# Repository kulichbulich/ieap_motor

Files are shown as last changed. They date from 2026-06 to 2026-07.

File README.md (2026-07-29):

# 4-Channel Motor Controller with ESP32
## Parts

### ESP32
Pin assigment https://github.com/atomic14/esp32-s3-pinouts/blob/main/README.md?utm_source=chatgpt.com

### Motor-driver module
Datasheet: https://www.analog.com/media/en/technical-documentation/data-sheets/TMC2209-BOB_datasheet_rev1.00.pdf
Motor module (KiCAD files): https://www.analog.com/media/en/evaluation-documentation/evaluation-design-files/TMC2209-BOB_Rev1.0.zip

### DC/DC converter
LT8610: https://www.analog.com/media/en/technical-documentation/data-sheets/lt8610.pdf
+5V Power supply
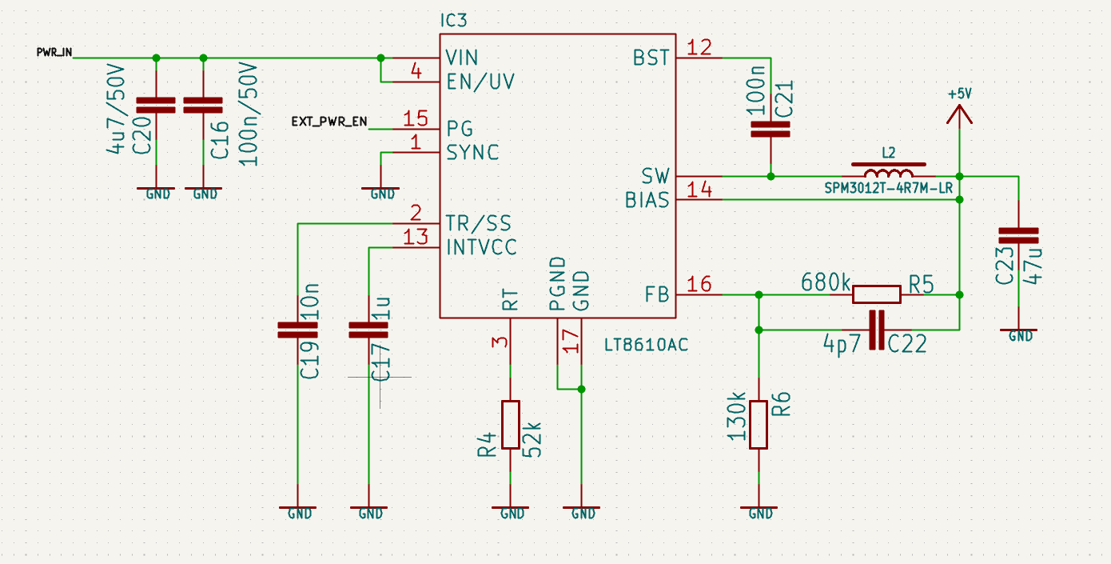
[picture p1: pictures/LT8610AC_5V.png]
image +5V

+5V Power supply
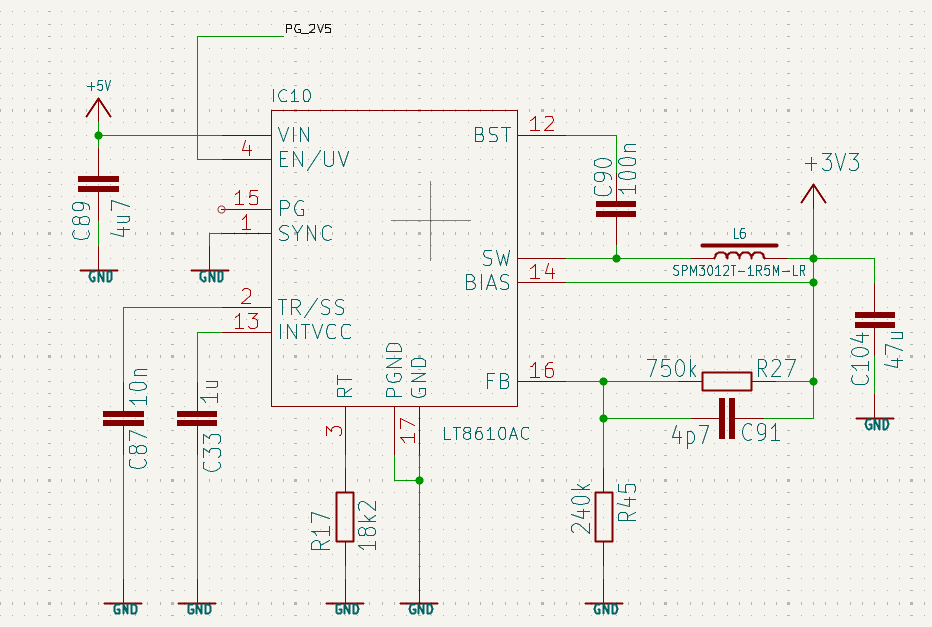
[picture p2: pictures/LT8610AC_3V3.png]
image +3V3


### Polyswitch
https://cz.mouser.com/ProductDetail/Littelfuse/MINISMDC150F-24-2?qs=F6FIpiMdEVZ%2Fp37J%2FDHAxA%3D%3D

# Enclosure

Enclosure - open view

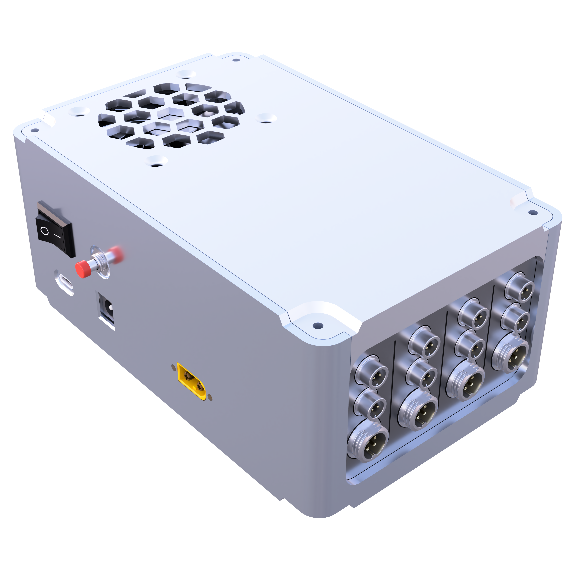
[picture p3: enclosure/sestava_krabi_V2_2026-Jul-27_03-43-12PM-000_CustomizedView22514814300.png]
Enclosure - closed view


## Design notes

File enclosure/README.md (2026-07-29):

# Enclosure

Enclosure - open view

Enclosure - closed view

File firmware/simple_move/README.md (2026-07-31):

# simple_move — základní pohyb driveru BOB-3

Nejjednodušší firmware, který na desce `esp32stepper` (ESP32-S3-WROOM-2 N32R16V + 4× TMC2209
SilentStepStick) rozhýbe **jeden** motor. Po zapnutí nastaví driver po UART, povolí ho a pak už jen
pořád dokola jede **jednu otáčku tam, pauza, jednu otáčku zpět, pauza**. Z konzole se nic neovládá —
konzole jen vypisuje, co se děje.

Vznikl jako osekaná kopie [../FAS_firmware](../FAS_firmware). Rozdíly jsou schválně:

| | simple_move | ../FAS_firmware |
|---|---|---|
| generátor kroků | jen softwarová smyčka (`stepper.cpp`) | smyčka **i** FastAccelStepper (`env:fas_accel`) |
| přepínače chování | žádné (čekání na Enter, vypnutí koncováku…) | `WAIT_FOR_ENTER`, `ENDSTOP_GUARD`, `STOP_ON_KEYPRESS` |
| reset driveru za běhu (výpadek 24 V) | **HALT** a čeká na člověka | sám se znovu nastaví (`driver_survived()`) |

Kdo potřebuje varianty, má sáhnout po `FAS_firmware`. Kdo chce ladit proud, rychlost a mikrokrok
**za běhu**, patří do [../testing_firmware](../testing_firmware), test **T09**.

## Co to potřebuje

| | |
|---|---|
| napájení | 24 V na barrel jacku (bez něj driver komunikuje, ale motor stojí a hlásí `uv_cp`) |
| motor | v konektoru **BOB-3** (čtvrtý slot; jiný slot = `MOTOR` v `include/move_config.h`) |
| ověřeno předem | testy **T06** (UART), **T07** (zapojení) a **T08** (pohyb) v `../testing_firmware` |
| mechanika | volná dráha na obě strany, motor se rozjede **3 s po nabootování** |

## Build a nahrání

`pio run -t upload` na této desce nespolehlivě padá (esptool 4.5.1 v PlatformIO, `BrokenPipeError`),
proto skript s vlastním esptoolem — podrobně v [../FLASH.md](../FLASH.md):

```bash
cd firmware/simple_move
../flash.sh -d .            # build + kontrola flash + zápis
../flash.sh -d . --check    # jen diagnostika, nic nezapisuje
pio device monitor -d .     # konzole (115200, USB CDC)
```

Prostředí je jediné (`simple`) a je v `default_envs`, takže `-e` není potřeba.

## Nastavení

Všechno je v [include/move_config.h](include/move_config.h) jako `constexpr` — změna znamená přeložit
a nahrát. Nejdůležitější hodnoty:

| konstanta | výchozí | co dělá |
|---|---|---|
| `MOTOR` | `3` | slot driveru 0–3; určuje i adresu na UART, STEP pin a koncový spínač |
| `MICROSTEPS` | `16` | mikrokrok; nastavuje se **po UART** (MS1/MS2 na desce drží adresu) |
| `RUN_CURRENT_MA` | `600` | efektivní (RMS) proud fáze při jízdě |
| `HOLD_CURRENT_PCT` | `50` | klidový proud v procentech z jízdního |
| `REVS_PER_MOVE` | `1.0` | jeden pohyb = jedna otáčka |
| `SPEED_RPM` | `60` | cestovní rychlost (60 rpm = otáčka za sekundu) |
| `ACCEL_RPS2` | `4.0` | zrychlení v otáčkách/s² (rozjezd na 60 rpm za 0,25 s) |
| `PAUSE_MS` | `500` | prodleva mezi pohyby |
| `START_DELAY_MS` | `3000` | odpočet po nabootování, než se motor rozjede |

### Proud se zadává v mA, driver ho zná jako CS

Registr `IHOLD_IRUN` má na proud jen 5 bitů, takže zadanou hodnotu nelze potrefit přesně: firmware si
z mA spočítá `CS` (a případně přepne `vsense` na jemnější rozsah) a na konzoli vypíše **obojí** —
co bylo zadáno a co se doopravdy nastavilo. Výchozích 600 mA vyjde na `IRUN = 19, vsense = 1`,
tedy ~612 mA RMS.

Celý přepočet stojí na `R_SENSE_OHM = 0.11` (SilentStepStick / Trinamic TMC2209-BOB). Jiná hodnota
na modulu = všechny proudy o ten podíl vedle. **Ampérmetrem to ověřené není**, jen podle datasheetu —
stejně jako v `FAS_firmware`. Podrobně v [../TMC2209_CURRENT.md](../TMC2209_CURRENT.md).

### MS1/MS2 dělají adresu i mikrokrok

Na této desce drží pull-upy `R13`–`R16` na `MS1`/`MS2` **adresu driveru** na UART sběrnici. Tytéž
piny ale po resetu určují i mikrokrok, takže mikrokrok se musí přepnout na registrový:

1. nejdřív `CHOPCONF.MRES` (žádaný mikrokrok),
2. teprve pak `GCONF` bit 7 `mstep_reg_select`.

V obráceném pořadí by driver na okamžik jel s `MRES` z resetu (1/256). Pořadí v
[src/tmc2209.cpp](src/tmc2209.cpp) je proto záměrné — podrobně v
[../TMC2209_MS1_MS2.md](../TMC2209_MS1_MS2.md).

`GCONF` bit 0 (`I_scale_analog`) zůstává **0** schválně: s jedničkou by proud škáloval pin `VREF`,
který modul driveru na této desce nevyvádí, a přepočet mA → CS by nic neznamenal.

## Co firmware kontroluje

Rozjede se jen tehdy, když všechno projde; jinak jde do `HALT` (driver zakázán, čeká na reset desky):

- **driver odpovídá** po UART a hlásí `VERSION = 0x21` i tu adresu, na kterou se ptáme (pět pokusů,
  driver po zapnutí chvíli nabíhá),
- **konfigurace prošla** — kontroluje se přes `IFCNT` (počet přijatých zápisů) i čtením registrů zpět,
- **`DRV_STATUS` nehlásí chybu** (přehřátí, zkrat na GND/VS) — před rozjezdem i po každém pohybu;
  `otpw` (předzvěst přehřátí) a `cs_actual = 0` (neteče proud → chybí 24 V) jsou jen varování,
- **`GSTAT.reset` po každém pohybu** — když driver mezitím ztratil napájení, přišel o celou
  konfiguraci (mikrokrok zpátky pinový, proud výchozí) a firmware jde do `HALT`. Pokračovat by
  znamenalo jet s proudem, který nikdo nezadal.

Kromě toho po každém cyklu ověří, že se počítadlo kroků vrátilo na začátek. **Pozor:** hlídá tím jen
samo sebe — když motor ztrácí kroky (malý proud, vysoká rychlost, tuhá mechanika), počítadlo o tom
nic neví a bez enkodéru to firmware nepozná.

## Bezpečnost

- **74HC595 má `~OE` na GND**, takže jeho výstupy platí od přivedení napájení a do prvního zápisu
  jsou náhodné. Proto je `mot.begin()` (STEP piny do L, `SR = 0xAA`, tedy všechny drivery zakázané)
  úplně první věc v `setup()` — ještě před konzolí, na kterou se čeká až 3 s.
- **Koncový spínač** `IO16` (pro `MOTOR = 3`) jízdu zastaví. Když je při startu už sepnutý — nebo
  není zapojený — hlídání se samo vypne (jinak by se firmware nikdy nerozjel) a vypíše se `[WARN]`.
- **Jakákoli klávesa** z konzole jízdu přeruší a driver zakáže (hřídel je pak volná); další klávesa
  pokračuje. Kontroluje se každých 16 kroků, tedy při 3200 krocích/s asi každých 5 ms.
- Motor se rozjede **sám** 3 s po nabootování, i bez připojené konzole. `START_DELAY_MS` je jediná
  pojistka, kdy se dá odpojit napájení.

## Stav

**Přeloženo, na desku nenahráno.** `pio run -e simple` staví čistě (`-Wall`, 0 warningů,
RAM 6,0 %, Flash 293 977 B). Kód je kopie logiky z `FAS_firmware`, která na hardwaru také nikdy
neběžela — chování je odvozené z datasheetu TMC2209 a z pin mapy, ne z pozorování na desce.

Neověřeno: skutečný proud fáze ampérmetrem, chování při výpadku 24 V za jízdy, funkce koncového
spínače.

## Struktura

```
simple_move/
  platformio.ini          jedno prostředí "simple" (default_envs), oktální flash config
  include/board_pins.h    kopie z ../testing_firmware — držet v souladu, NENÍ symlink
  include/move_config.h   VŠECHNA nastavení jako constexpr
  include/tmc2209.h + src/tmc2209.cpp   driver po jednodrátové UART, přepočet mA -> CS
  include/stepper.h + src/stepper.cpp   74HC595 (DIR/EN) + generátor kroků s trapézovou rampou
  src/main.cpp            bring-up, kontroly, smyčka pohybů
```

Žádná externí knihovna — je to pět registrů a stejně by se muselo řešit zahazování vlastního echa na
jednodrátové sběrnici, takže `TMCStepper` by nic neušetřil.

`move()` **blokuje**: kroky se generují softwarovou smyčkou na `micros()`, ne timerem ani RMT. Dokud
pohyb neskončí, firmware nedělá nic jiného. Až bude potřeba víc motorů najednou nebo souběžné čtení
enkodérů, tohle se musí přepsat (nebo použít FastAccelStepper — prototyp je v
[../FAS_firmware](../FAS_firmware), prostředí `fas_accel`).

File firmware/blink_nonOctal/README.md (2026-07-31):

Použil jsem tyto dva příkazy:

ls -la /dev/ttyACM* /dev/ttyUSB*
— zjištění, na jakém portu je deska připojená (vyšlo /dev/ttyACM0, nativní USB; /dev/ttyUSB* nebyl přítomen).

cd /home/pe/Documents/repos/ieap_motor/firmware/blink_nonOctal
pio run -t upload --upload-port /dev/ttyACM0
— standardní PlatformIO build + upload (přeloží blink_nonoctal env a nahraje přes zabudovaný esptool 4.5.1, který v platformio.ini komentář zmiňuje jako nefunkční jen pro desku esp32stepper, ne pro tenhle devkit — zde prošel bez problémů).

---------------nebo--------------------

Použil jsem:

cd firmware/blink_nonOctal
pio run                                          # build bez uploadu

# nový esptool z venv (5.3.1, stejný, co používá flash.sh pro octal desku)
~/venv-esptool/bin/python -m esptool \
    --port /dev/ttyACM0 --baud 460800 \
    --before default-reset --connect-attempts 5 \
    write-flash --flash-mode keep --flash-freq keep --flash-size keep \
    0x0     .pio/build/blink_nonoctal/bootloader.bin \
    0x8000  .pio/build/blink_nonoctal/partitions.bin \
    0xe000  ~/.platformio/packages/framework-arduinoespressif32/tools/partitions/boot_app0.bin \
    0x10000 .pio/build/blink_nonoctal/firmware.bin
Jedna odchylka od flash.sh: --before usb-reset (co používá flash.sh pro esp32stepper) na tomhle devkitu selhalo s "No serial data received". Musel jsem přepnout na --before default-reset — tenhle devkit má klasický auto-reset přes RTS/DTR, ne přes signalizaci nativního USB-Serial/JTAG periferie.

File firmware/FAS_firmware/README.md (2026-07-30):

# FAS firmware — pohyb tam a zpět
@doc_pwc: file:README.md | id:HW-00176 | created:2026-07-30 | rev:2 | revised:2026-07-30_1802 | type:MAN

Nejjednodušší **aplikační** firmware desky `esp32stepper` (ESP32-S3-WROOM-2 N32R16V + 4× TMC2209
SilentStepStick). Po zapnutí nastaví jeden driver po UART, povolí ho a pak už jen pořád dokola jede
**jednu otáčku tam, pauza, jednu otáčku zpět, pauza**. Z konzole se nic neovládá — konzole jen
vypisuje, co se děje.

Tohle je první krok od testů k aplikaci: [../testing_firmware](../testing_firmware) se ptá na
parametry a čeká na člověka, tenhle firmware se rozjede sám po zapnutí, jako to bude dělat hotový
stroj.

## Co to potřebuje

| | |
|---|---|
| napájení | 24 V na barrel jacku (bez něj driver komunikuje, ale motor stojí a hlásí `uv_cp`) |
| motor | v konektoru **BOB-3** (čtvrtý slot; jiný slot = `MOTOR` v `include/fas_config.h`) |
| ověřeno předem | testy **T06** (UART), **T07** (zapojení) a **T08** (pohyb) v `../testing_firmware` |
| mechanika | volná dráha na obě strany, motor se rozjede **3 s po nabootování** |

## Build a nahrání

`pio run -t upload` na této desce nespolehlivě padá (esptool 4.5.1 v PlatformIO, `BrokenPipeError`),
proto skript s vlastním esptoolem — podrobně v [../FLASH.md](../FLASH.md):

```bash
cd firmware/FAS_firmware
../flash.sh -d .            # build + kontrola flash + zápis
../flash.sh -d . --check    # jen diagnostika, nic nezapisuje
pio device monitor -d .     # konzole (115200, USB CDC)
```

Prostředí je jediné (`fas`) a je v `default_envs`, takže `-e` není potřeba.

## Nastavení

Všechno je v [include/fas_config.h](include/fas_config.h) jako `constexpr` — změna znamená přeložit
a nahrát. Nejdůležitější hodnoty:

| konstanta | výchozí | co dělá |
|---|---|---|
| `MOTOR` | `3` | slot driveru 0–3; určuje i adresu na UART, STEP pin a koncový spínač |
| `MICROSTEPS` | `16` | mikrokrok; nastavuje se **po UART** (MS1/MS2 na desce drží adresu) |
| `RUN_CURRENT_MA` | `600` | efektivní (RMS) proud fáze při jízdě |
| `HOLD_CURRENT_PCT` | `50` | klidový proud v procentech z jízdního |
| `REVS_PER_MOVE` | `1.0` | jeden pohyb = jedna otáčka |
| `SPEED_RPM` | `60` | cestovní rychlost (60 rpm = otáčka za sekundu) |
| `ACCEL_RPS2` | `4.0` | zrychlení v otáčkách/s² (rozjezd na 60 rpm za 0,25 s) |
| `PAUSE_MS` | `500` | prodleva mezi pohyby |
| `START_DELAY_MS` | `3000` | odpočet po nabootování, než se motor rozjede |
| `WAIT_FOR_ENTER` | `false` | `true` = deska se sama nerozjede, čeká na klávesu |

Ladit proud, rychlost a mikrokrok **za běhu** se dá v `../testing_firmware`, test **T09** — tady se
mění jen v kódu.

### Proud se nastavuje v mA, driver ho zná jako CS

Registr `IHOLD_IRUN` má na proud jen 5 bitů, takže zadanou hodnotu nelze potrefit přesně:

```
I_rms = (CS+1)/32 × V_fs/(R_sense+0,02) × 1/√2      V_fs = 0,325 V (vsense=0) nebo 0,180 V (vsense=1)
```

Firmware si CS spočítá sám, a když se proud vejde do jemnějšího rozsahu (`vsense=1`), použije ho —
polovina chyby zaokrouhlení. Na konzoli vypíše obojí, zadané i skutečné:

```
proud    : zadano 600 mA -> nastaveno 612 mA RMS (IRUN=19, vsense=1, Rsense 0.11 ohm)
           klidovy 50 % = 306 mA (IHOLD=9, IHOLDDELAY=6, TPOWERDOWN=20)
```

Dvě věci, které z toho plynou:

* **`R_SENSE_OHM = 0.11` je jediné číslo, na kterém celý přepočet stojí.** 0,11 Ω má
  SilentStepStick TMC2209 i Trinamic TMC2209-BOB. Když je na modulu jiná hodnota, jsou všechny
  proudy o ten podíl vedle — ověřit ampérmetrem, ne z datasheetu klonu.
* Strop je **1768 mA RMS** (CS=31, `vsense=0`). Vyšší zadání se do něj utne, `SilentStepStick`
  bez chladiče na to ale stejně není.

### MS1/MS2 dělají adresu i mikrokrok

Na této desce mají `MS1`/`MS2` dvě funkce najednou: pull-upy `R13..R16` jim dávají UART adresu, a tím
zároveň každé patici jiné rozlišení mikrokroku (BOB-0 = 1/8, BOB-1 = 1/2, BOB-2 = 1/4, BOB-3 = 1/16).
Podrobně [../TMC2209_MS1_MS2.md](../TMC2209_MS1_MS2.md) (HW-00201). Firmware to řeší takto:

* `CHOPCONF.MRES` se zapisuje **před** `GCONF` bitem 7 (`mstep_reg_select`) — v okamžiku, kdy se
  řízení přebírá z pinů do registru, už v registru musí být správná hodnota. V obráceném pořadí by
  driver mezitím jel podle toho, co v `MRES` zbylo (po resetu 1/256).
* `GCONF` bit 0 (`I_scale_analog`) firmware **záměrně nuluje** — s jedničkou by proud škáloval pin
  `VREF` a přepočet mA → CS by nic neznamenal. Modul driveru `VREF` na této desce ani nevyvádí
  (symbol v `PCB/tmc2209_driver.kicad_sch` má 17 pinů a `VREF` mezi nimi není). Tohle je jediné
  místo, kde se firmware odchyluje od doporučení HW-00201 (čti-uprav-zapiš celého `GCONF`).
* **`GSTAT` bit 0 se čte po každém pohybu.** Registry driveru jsou volatilní — po výpadku 24 V
  naběhne s výchozími hodnotami (mikrokrok zpátky z pinů, `IRUN` = 23, `I_scale_analog` = 1) a na
  `DRV_STATUS` to není vidět. Když firmware reset zachytí, driver zakáže, znovu nastaví, vynuluje
  počítadlo polohy (hřídel se během výpadku mohla protočit) a jede dál. Když se znovunastavení
  nepovede, jde do `HALT`.

## Výpis na konzoli

```
===================================================
  FAS firmware - pohyb tam a zpet
===================================================
driver odpovida: VERSION=0x21, ENN=1, PDN_UART=1
driver   : BOB-3, adresa 3 na UART sbernici (IO17/IO18), STEP=IO7, koncovak=IO16
mikrokrok: 1/16 z registru (MS1/MS2 tady drzi adresu), 3200 kroku na otacku
proud    : zadano 600 mA -> nastaveno 612 mA RMS (IRUN=19, vsense=1, Rsense 0.11 ohm)
pohyb    : 1.00 otacky = 3200 kroku, 60.0 rpm (3200 kroku/s), zrychleni 4.0 ot/s^2
           rampa 398 kroku, jeden pohyb ~1.2 s, pauza 500 ms
koncovy spinac IO16 je rozepnuty - pri sepnuti pohyb zastavi
motor se rozjede za 3 s - mechanika musi mit volnou drahu
driver povolen, hridel drzi klidovy proud. Tady je nula polohy - ...

cyklus 1: 1.00 otacky tam a zpet
  smer A: 3200 kroku za 1247 ms (~2565 kroku/s), poloha +3200
  smer B: 3200 kroku za 1246 ms (~2568 kroku/s), poloha +0
```

Naměřená rychlost je nižší než cestovní — je to průměr přes celý pohyb včetně obou ramp.

## Bezpečnost a zastavení

* **Bezpečný stav je první věc v `setup()`**, ještě před konzolí: `74HC595` má `~OE` na GND, takže
  jeho výstupy platí od přivedení napájení a do prvního zápisu jsou náhodné. Čekání na USB CDC trvá
  až 3 s — tak dlouho nesmí být povolený driver s náhodným DIR.
* **Jakákoli klávesa** z konzole jízdu přeruší (driver se zakáže, hřídel se pustí); další klávesa
  pokračuje. Počítadlo polohy zůstává, ale značka na hřídeli už na startu nebude.
* **Koncový spínač** daného motoru jízdu zastaví — ale jen když je v klidu rozepnutý (H). Když už
  při startu drží L (sepnutý nebo nezapojený bez pull-upu), hlídání se vypne a jedinou pojistkou je
  klávesa. Firmware to na konzoli hlásí.
* **`DRV_STATUS` se čte po každém pohybu.** Přehřátí a zkraty (`ot`, `s2g*`, `s2vs*`) firmware
  zastaví natrvalo (`HALT`, driver zakázán, chce reset desky). `otpw` (předzvěst přehřátí) a
  `ola`/`olb` (rozpojená fáze, hlásí je i zdravý stojící motor) jsou jen varování.
* Symetrický pohyb musí skončit na poloze **0**. Když počítadlo je na nule a značka na hřídeli ne,
  motor **ztrácí kroky** — malý proud, vysoká rychlost, tuhá mechanika.

## Struktura

```
platformio.ini          jedno prostředí "fas"; oktální flash konfigurace (viz níže)
include/board_pins.h    pin mapa desky — kopie z testing_firmware, držet v souladu
include/fas_config.h    všechna nastavení
include/tmc2209.h       driver na jednodrátové UART sběrnici + přepočet mA -> CS
include/stepper.h       generátor kroků, 74HC595 (DIR/EN), trapézová rampa
src/main.cpp            bring-up (ping, GSTAT, konfigurace, kontroly) a smyčka pohybů
```

Žádná externí knihovna (`lib_deps` je prázdné). TMC2209 se obsluhuje přímo — je to pět registrů
a v jednodrátovém režimu se stejně musí zahazovat vlastní echo, takže `TMCStepper` by tu nic
neušetřil.

### Konfigurace flash v `platformio.ini`

Modul je **N32R16V**: 32 MB oktální (OPI) flash + 16 MB oktální PSRAM, obojí na 1V8 (potvrzeno
z efuse). Konfigurace `memory_type = opi_opi` **není kosmetika** a platí na obě strany:

* quad konfigurace na tomto modulu **nenabootuje** — ROM podle efuse zapne OPI a aplikace spadne na
  `assert failed: do_core_init startup.c:328 (flash_ret == ESP_OK)` ve smyčce resetu,
* a binárku s `opi_opi` naopak nenos na DevKitC-1 N8R2 — tam skončí na
  `E cpu_start: Octal Flash option selected, but EFUSE not configured!`.

`flash_mode` je záměrně `dout`, ne `opi`: ani první, ani druhý bootloader OPI neumí, zavádí se
v DOUT a ROM režim nahradí podle efuse. Tři pasti, které stály hodiny, jsou v
[../report.md](../report.md).

## Známé hranice

* **`move()` blokuje.** Kroky se generují softwarovou smyčkou (`micros()` termíny), ne timerem ani
  RMT — na pár tisíc kroků/s to stačí a kód je čitelný, ale dokud pohyb neskončí, firmware nedělá
  nic jiného. Až bude potřeba jet víc motory najednou nebo mezitím číst enkodéry, musí se to
  přepsat na timer.
* Strop generátoru je **20 000 kroků/s**; `SPEED_RPM` nad tuto hranici firmware sníží a nahlásí.
* Jede **jeden motor**, ostatní tři zůstávají zakázané.
* Driver zůstává na výchozím **stealthChop** (tichý, ale nižší moment ve vyšších otáčkách) —
  `spreadCycle` ani `TPWMTHRS` se tu nenastavují.
* **Bez enkodéru.** Poloha je jen počítadlo vydaných kroků, ne měřená skutečnost. Enkodéry na
  desce jsou (I2C mux `TCA9548A`), tenhle firmware je nepoužívá.

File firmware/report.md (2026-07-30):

# Oživení ESP32-S3-WROOM-2 na desce esp32stepper — co bylo špatně a jak s tím zacházet
@doc_pwc: file:report.md | id:HW-00173 | created:2026-07-30 | rev:1 | revised:2026-07-30_0913 | type:PROC

Postmortem k tomu, proč se na desku `PCB/esp32stepper.kicad_pro` nedalo nic nahrát, a závazný postup
pro příště. Řešeno 2026-07-29 a 2026-07-30. **Modul vadný nebyl** — jeden den se to omylem uzavřelo
jako hardwarová závada, což byl špatný závěr.

---

## Shrnutí jednou větou

Na sobě ležely **tři nezávislé problémy**, každý maskoval ten další, a první dva dohromady vypadaly
přesně jako mrtvý hardware.

| # | Problém | Projev | Náprava |
|---|---|---|---|
| 1 | Flash zaseknutá v OPI režimu | `Failed to communicate with the flash chip`, `Manufacturer: 00` | úplné odpojení napájení |
| 2 | Nastavené block-protect bity ve flash | `flash_id` OK, ale zápis tiše selže | `esptool write-flash-status` |
| 3 | Quad build konfigurace na oktálním modulu | boot loop na `do_core_init` assertu | `opi_opi` + `dout` + 32 MB |

Navíc se ukázalo, že **esptool z PlatformIO (4.5.1) je na téhle desce nepoužitelný** a nahrávat se
musí samostatným esptoolem 5.3.1.

---

## Varianta modulu — potvrzeno

`U1` je **ESP32-S3-WROOM-2 N32R16V**: 32 MB oktální (OPI) flash + 16 MB oktální PSRAM, obojí 1,8 V.
Flash je samostatná die na substrátu modulu, ne v čipu.

Ověřeno proti efuse přímo na čipu i proti `RDID`:

```
FLASH_TYPE   = 8 data lines          VDD_SPI_XPD   = True
PSRAM_CAP    = 16M                   VDD_SPI_TIEH  = 1.8V LDO
PSRAM_VENDOR = AP_1v8                VDD_SPI_FORCE = True
FLASH_CAP    = None  (spravne: flash neni v cipu, ale na substratu modulu)
RDID         = C2 80 39  -> Macronix MX25UM25645G, 32 MB
```

BOM `PCB/esp32stepper.csv` uvádí u `U1` jen „ESP32-S3-WROOM-2" bez paměťové přípony, protože se
generuje z KiCadu. **Variantu ber odsud, ne z BOM.** Právě ta nejistota v BOM stála za problémem č. 3.

---

## Problém 1 — flash zaseknutá v OPI režimu

**Projev.** `esptool flash_id` hlásil `Failed to communicate with the flash chip` a
`Manufacturer: 00, Device: 0000`. Čtení flash vracelo nedeterministická data — tři čtení téže adresy
`0x0` daly tři různé MD5. Chip erase „uspěl" za 0,6 s (u 32 MB nemožné) a nic nesmazal.

**Proč.** Reset přes `EN` resetuje procesor, ale **neresetuje flash die**. Když v ní zůstane OPI
režim (nastaví ho ROM podle efuse při bootu, viz problém 3), ROM ani esptool s ní v SPI/DOUT režimu
nedomluví. Ta nedeterministická data byly plovoucí datové linky.

**Náprava.** Úplně odpojit napájení. **Pozor: deska umí jet i z 24 V barrel jacku** (`LT8610` buck →
`LDL1117` na 3V3), takže vytažení jen USB modul nevypne. Odpoj USB **i** barrel jack a počkej ~10 s
na vybití kondenzátorů.

Po power cyclu začal `flash_id` vracet správně `C2 / 8039 / 32MB`.

**Slepé uličky, které stály čas** — tudy ne:

- verze esptoolu (4.5.1 i 5.3.1 selhaly stejně), se stubem i `--no-stub`
- rychlosti: 4 baud raty × 2 režimy stubu, všech 8 kombinací identicky `Manufacturer: 00`.
  Přes nativní USB-Serial/JTAG je baud rate principiálně **no-op**, je to USB CDC — `upload_speed`
  na téhle cestě nemůže udělat nic.
- pájení FTDI na UART0 — nepomůže, závada je na sběrnici SPI0↔flash, tedy *za* hostitelským
  rozhraním; přes UART dostaneš stejnou chybu
- napájení: program u téhle flash tahá jednotky mA, kdežto běžící CPU s USB řádově víc a ten jede
- efuse: jsou od výroby správné, **nic v nich nepal** (viz níže)

## Problém 2 — block-protect bity ve flash

**Projev.** `flash_id` už vracel správně `C2/8039/32MB`, ale zápis tiše neprošel:
`MD5 of file does not match data in flash!`, u zápisu mimo hlavičku
`Write failed, the written flash region is empty`. Chip erase pořád „uspěl" a nic nesmazal.

**Diagnóza.** Status registr `MX25UM25645G` čten jako `SR1 = 0xB0`:

| bit7 | bit6 | bit5 | bit4 | bit3 | bit2 | bit1 | bit0 |
|---|---|---|---|---|---|---|---|
| Reserved | Reserved | **BP3=1** | **BP2=1** | BP1=0 | BP0=0 | WEL=0 | WIP=0 |

`BP[3:0] = 1100`, tedy nenulové → pole chráněné proti zápisu. Datasheet to popisuje doslova:

> *„If a program or erase instruction is applied to a protected memory area, the instruction will be
> ignored and WEL will clear to 0."*
>
> *„only if Block Protect bits (BP3:BP0) set to 0, the CE instruction can be executed"*

To vysvětluje jak tichý fail zápisu, tak chip erase, který nic nesmazal.

**Pozor na dvě věci, které se snadno spletou** (a já je spletl, než jsem si přečetl datasheet):
`MX25UM` (oktální) série **nemá bity `SRWD` ani `QE`** — bit7 a bit6 jsou Reserved. Neber layout
status registru z analogie s quad sérií `MX25U`.

**Náprava.**

```bash
esptool --port /dev/ttyACM0 read-flash-status  --bytes 1                      # kontrola: 0xb0
esptool --port /dev/ttyACM0 write-flash-status --bytes 1 --non-volatile 0x00  # naprava
esptool --port /dev/ttyACM0 read-flash-status  --bytes 1                      # overeni: 0x00
```

Proč přesně takhle:

- `--bytes 1` **záměrně**: `WRSR` (`01h`) bere 8 nebo 16 bitů a jen 8bitová forma nechá
  **konfigurační registr netknutý** (dummy cycles, ODS). 16 bitů by ho přepsalo a rozbilo časování
  čtení.
- `--non-volatile` je **nutné**: posílá `WREN` (`06h`) před `WRSR`, což datasheet vyžaduje. Bez něj
  jde `WEVSR` (`50h`), který tenhle díl nemusí znát.
- `BP` bity jsou nevolatilní, ale **volně přepisovatelné** — není to OTP, jde to vrátit.
- OTP bit `WPSEL` se tímhle nastavit **nedá**, má jiný opcode (`68h`). Kdyby byl `WPSEL=1`, byly by
  `BP` bity bez efektu a blokovaly by `DPB` bity po každém zapnutí; poznalo by se to tím, že se
  zápis do SR neprojeví.

Příčina, proč byly `BP` bity nastavené, není prokázaná. Nejpravděpodobněji je nastavily zápisy do
flash zaseknuté v OPI režimu (problém 1), kde se SPI příkazy interpretují jako něco jiného.

## Problém 3 — quad konfigurace na oktálním modulu

**Projev.** Nahrávání konečně prošlo s `Hash of data verified`, ale deska se resetovala ve smyčce:

```
SPIWP:0xee
Octal Flash Mode Enabled
For OPI Flash, Use Default Flash Boot Mode
...
assert failed: do_core_init startup.c:328 (flash_ret == ESP_OK)
```

**Proč.** ROM podle efuse zapne OPI, ale aplikace byla přeložená pro quad (`qio_qspi`, `dio`, 8 MB),
takže inicializace flash v aplikaci selže.

**Tohle přímo vyvrací, co dřív tvrdil `testing_firmware/README.md`:** že quad konfigurace
„nabootuje na každé variantě S3 včetně modulu, který octal paměti opravdu má". Nenabootuje. **Žádný
quad/oktální společný jmenovatel neexistuje** a obě README i `platformio.ini` jsou už opravené.

**Správná konfigurace** pro N32R16V:

```ini
board_upload.flash_size = 32MB
board_build.partitions = default_16MB.csv
board_build.flash_mode = dout
board_build.arduino.memory_type = opi_opi
```

- `flash_mode = dout`, **ne `opi`**: 1. ani 2. bootloader OPI neumí, zavádí se v DOUT a ROM režim
  nahradí podle efuse. Stejně to má i board def `esp32s3camlcd`, jediný v platformu s `opi_opi`.
- `default_32MB.csv` ve frameworku **neexistuje**; `default_16MB.csv` na 32 MB čipu jede (nevyužije
  zbytek), pro víc prostoru je `large_littlefs_32MB.csv`.

---

## Postup nahrávání odteď

`pio run -t upload` na téhle desce **nepoužívej**. PlatformIO má v sobě esptool 4.5.1
(`tool-esptoolpy 1.40501.0`), který na oktální flash přes nativní USB-Serial/JTAG padá na
`BrokenPipeError: [Errno 32] Broken pipe`, jakmile se čip zároveň resetuje (typicky když je v boot
loopu). Samostatný esptool 5.3.1 se připojí bez problémů.

```bash
# jednorazova priprava
python3 -m venv ~/venv-esptool && ~/venv-esptool/bin/pip install esptool

# 1) jen build, BEZ -t upload
pio run -e usb_j5            # nebo -e menu v testing_firmware

# 2) nahrani samostatnym esptoolem
~/venv-esptool/bin/python -m esptool --port /dev/ttyACM0 --baud 460800 \
    --before usb-reset --connect-attempts 5 \
    write-flash --flash-mode keep --flash-freq keep --flash-size keep \
    0x0     .pio/build/usb_j5/bootloader.bin \
    0x8000  .pio/build/usb_j5/partitions.bin \
    0xe000  ~/.platformio/packages/framework-arduinoespressif32/tools/partitions/boot_app0.bin \
    0x10000 .pio/build/usb_j5/firmware.bin
```

`keep` u všech tří parametrů je důležité — nechá hlavičku z buildu být, aby ji esptool nepřepsal na
jinou velikost nebo režim flash. `--before usb-reset` pomáhá, když se čip resetuje ve smyčce.

## Diagnostický postup, když to zase nejde

Vždycky v tomhle pořadí, od nejlevnějšího:

1. **`flash_id`** — první věc, ještě před jakýmkoli buildem.
   ```bash
   ~/venv-esptool/bin/python -m esptool --port /dev/ttyACM0 flash-id
   ```
   Zdravý stav: `Manufacturer: c2`, `Device: 8039`, `Detected flash size: 32MB`, **bez** varování.
2. **`Manufacturer: 00`** → problém 1. Odpoj USB **i** barrel jack, počkej 10 s, zopakuj.
3. **`flash_id` OK, ale zápis selže** → problém 2. Přečti status registr, případně vynuluj.
4. **Nahraje se, ale boot loop** → problém 3. Zkontroluj `memory_type`/`flash_mode`/`flash_size`
   proti tabulce výše a proti tomu, na jaké desce jsi (WROOM-2 vs. DevKit N8R2).

## Co nikdy nedělat

- **Nepal efuse.** Jsou od výroby správné. `espefuse burn_*` je nevratné a špatné `VDD_SPI` by 1,8 V
  flash zničilo. Nic v nich opravovat netřeba a `summary` je bezpečné (jen čte).
- **Nezapisuj do status registru 16bitovou formou** (`--bytes 2`), přepsalo by to konfigurační
  registr.
- **Neřeš to rychlostmi.** Přes nativní USB je `upload_speed` no-op.
- **Nenos oktální konfiguraci na DevKit N8R2.** Ten má quad flash a skončí na
  `E cpu_start: Octal Flash option selected, but EFUSE not configured!`.

## Otevřené otázky

- **Reset/BOOT hardware desky není zdokumentovaný.** BOM uvádí jen `SW1`, který schéma kreslí jako
  napájecí `SW_SPDT`, plus dvoupinovou lištu `J1`, která v BOM není. `testing_firmware/README`
  tvrdí „tlačítko `BOOT1`, ale žádný reset", `test_simple/platformio.ini` mluví o „cvakni reset na
  J1". Než se na konkrétní tlačítko spolehneš, ověř to ve schématu.
- **Banner z `test_simple` se přes nativní USB CDC nezachytí** — cokoli vypsaného před otevřením
  portu hostem se ztratí. `ALIVE #n` v sekundové smyčce ověří, že to běží; na banner je potřeba
  externí FTDI na `J5`.
- Nikdy se neověřilo, jestli je závada č. 2 na jednom kusu, nebo na celé sérii. **Zkus druhou
  desku**, ať se to ví.

## Stav k 2026-07-30

Deska běží. Firmware `test_simple` nahraný a ověřený (`Hash of data verified`), `ALIVE` počítadlo
běží, po resetu startuje čistě od `#2`, žádný boot loop. Z testovací sady `testing_firmware` zatím
na téhle desce nic neběželo — `T00` a `T01` jsou odladěné jen na DevKitu N8R2.

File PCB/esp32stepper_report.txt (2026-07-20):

PCB statistics report
=====================
- Date: Ne 19. července 2026, 21:08:01
- Project: esp32stepper
- Board name: esp32stepper

Board
-----
- Width: 100,0000 mm
- Height: 80,0000 mm
- Area: 8000,00 mm²
- Front copper area: 3148,227 mm²
- Back copper area: 1132,321 mm²
- Min track clearance: 0,2000 mm
- Min track width: 0,2000 mm
- Min drill diameter: 0,3000 mm
- Board stackup thickness: 1,6000 mm

- Front footprint area: 5329,225 mm²
- Back footprint area: 617,64 mm²
- Front component density: 66,62 %
- Back component density: 7,72 %
Pads
----
- Through hole: 186
- SMD: 324
- Connector: 8
- NPTH: 5
- Castellated: 0
- Press-fit: 0

Vias
----
- Through vias: 106
- Blind vias: 0
- Buried vias: 0
- Micro vias: 0

Components
----------

| | Front Side | Back Side | Total |
|---|---|---|---|
|THT: | 16 | 0 | 16 |
|SMD: | 107 | 0 | 107 |
|Unspecified:  | 18 | 0 | 18 |
|Total: | 141 | 0 | 141 |

Drill holes
-----------

| Count | Shape | X Size | Y Size | Plated | Via/Pad | Start Layer | Stop Layer |
|---|---|---|---|---|---|---|---|
| 98 | Round | 0,3000 mm | 0,3000 mm | PTH | Via | F.Cu | B.Cu |
| 83 | Round | 1,0000 mm | 1,0000 mm | PTH | Pad | F.Cu | B.Cu |
| 40 | Round | 0,9500 mm | 0,9500 mm | PTH | Pad | F.Cu | B.Cu |
| 32 | Round | 0,3000 mm | 0,3000 mm | PTH | Pad | F.Cu | B.Cu |
| 16 | Round | 0,4000 mm | 0,4000 mm | PTH | Pad | F.Cu | B.Cu |
| 4 | Round | 1,0000 mm | 1,0000 mm | PTH | Via | F.Cu | B.Cu |
| 4 | Round | 3,2000 mm | 3,2000 mm | PTH | Pad | F.Cu | B.Cu |
| 4 | Round | 1,2000 mm | 1,2000 mm | NPTH | Pad | F.Cu | B.Cu |
| 2 |  Slot | 1,0000 mm | 2,5000 mm | PTH | Pad | F.Cu | B.Cu |
| 2 |  Slot | 0,6000 mm | 1,4000 mm | PTH | Pad | F.Cu | B.Cu |
| 2 |  Slot | 0,6000 mm | 2,1000 mm | PTH | Pad | F.Cu | B.Cu |
| 2 | Round | 0,6000 mm | 0,6000 mm | PTH | Via | F.Cu | B.Cu |
| 2 | Round | 0,5000 mm | 0,5000 mm | PTH | Via | F.Cu | B.Cu |
| 1 | Round | 1,6000 mm | 1,6000 mm | NPTH | Pad | F.Cu | B.Cu |
| 1 |  Slot | 3,0000 mm | 1,0000 mm | PTH | Pad | F.Cu | B.Cu |
| 1 |  Slot | 2,3000 mm | 1,0000 mm | PTH | Pad | F.Cu | B.Cu |
| 1 |  Slot | 1,0000 mm | 3,2000 mm | PTH | Pad | F.Cu | B.Cu |
| 1 |  Slot | 3,2000 mm | 1,0000 mm | PTH | Pad | F.Cu | B.Cu |
| 1 |  Slot | 3,6000 mm | 1,0000 mm | PTH | Pad | F.Cu | B.Cu |

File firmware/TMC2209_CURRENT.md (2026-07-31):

# TMC2209: jak se na této desce nastavuje proud (IRUN/IHOLD, CS, mA)

@doc_pwc: file:TMC2209_CURRENT.md | id:HW-00179 | created:2026-07-31 | rev:1 | revised:2026-07-31_0923 | type:REF

## Shrnutí

Registr `IHOLD_IRUN` (0x10) nemá proud v miliampérech, ale v abstraktním kroku **CS**
(Current Scale, 0–31). Kolik miliampérů který CS opravdu znamená, závisí na dvou věcech,
které nejsou v registru vidět: snímacím rezistoru na desce driveru (`Rsense`) a jednom
bitu v jiném registru (`vsense` v `CHOPCONF`). Bez těchhle dvou čísel je "IRUN=8" jen
číslo bez jednotky — přesně to je ten "divný stupeň", který si všiml operátor testu T08.

`testing_firmware` (T08, T09) proto nezadává CS přímo, ale přepočítává ho z mA pomocí
`tk::cs_from_ma()` / `tk::ma_from_cs()` v `lib/testkit`.

## Vzorec

Datasheet TMC2209, kapitola o `IHOLD_IRUN`:

```
I_rms = (CS+1)/32 × V_fs / (R_sense + 0,02) × 1/√2
```

- **`CS`** — hodnota 0–31 zapsaná do registru. `+1`, protože CS=0 neznamená nulový
  proud, ale nejnižší nenulový krok.
- **`V_fs`** — plné napěťové rozpětí snímacího zesilovače. Řídí ho bit `vsense`
  v `CHOPCONF` (bit 17): `V_fs = 0,325 V` (vsense=0) nebo `0,180 V` (vsense=1, jemnější
  krok, nižší strop).
- **`R_sense + 0,02`** — snímací rezistor na desce driveru plus 0,02 Ω, což je datasheetem
  udávaný vnitřní odpor spodních spínačů H-můstku. Bez toho přičtení by přepočet byl u
  malých proudů systematicky vedle.
- **`1/√2`** — driver řídí špičkovou hodnotu proudu (sinusovka mikrokrokování), ale
  udávaná i měřená veličina je RMS.

## Rsense téhle desky: 0,11 Ω

Na desce jsou u driveru dva SMD rezistory (jeden na fázi A, jeden na fázi B) s potiskem
`R11`. To je běžný zápis SMD rezistorů pod 1 Ω: `R` nahrazuje desetinnou tečku, takže
`R11` = **0,11 Ω** (analogicky `1R1` by bylo 1,1 Ω, `11R0` by bylo 11 Ω). Ověřeno přímým
pohledem na desku 2026-07-31 — nejde o hodnotu opsanou z README, viz "Jak je to ověřené"
níže.

0,11 Ω je zároveň hodnota, kterou pro tyhle moduly (SilentStepStick / Trinamic
TMC2209-BOB) používá i `FAS_firmware` (`R_SENSE_OHM` v `fas_config.h`) — obě desky tedy
sedí na stejné číslo.

## Dva rozsahy podle `vsense`

Se snímacím rezistorem 0,11 Ω vychází CS 0–31 na tyhle proudy:

| CS | vsense=0 (V_fs=0,325 V) | vsense=1 (V_fs=0,180 V) |
|---|---|---|
| 0  | 55 mA | 31 mA  |
| 8  | 497 mA  | 275 mA |
| 16 | 939 mA  | 520 mA |
| 24 | 1381 mA | 765 mA |
| 31 | 1768 mA | 979 mA |

- **vsense=0** — krok ~55 mA na jeden CS, strop 1768 mA RMS.
- **vsense=1** — krok ~31 mA na jeden CS (jemnější), ale strop jen 979 mA RMS.

Driver po resetu startuje na `vsense=0` a `testing_firmware` do `CHOPCONF` (kde ten bit
je) vůbec nesahá — proto T08/T09 počítají jen s rozsahem **vsense=0, 55–1768 mA**. Nižší
proud s jemnějším krokem by šel (jako ve `FAS_firmware`, který si vybírá rozsah podle
zadaného proudu automaticky), ale vyžaduje číst-upravit-zapsat `CHOPCONF` a hlídat pořadí
zápisů vůči `MRES` (viz `TMC2209_MS1_MS2.md`, HW-00201) — pro bring-up testovací žebřík to
zbytečně zvyšuje riziko na sdíleném kódu.

## IRUN vs. IHOLD

`IHOLD_IRUN` nese dvě hodnoty proudu, ne jednu:

- **IRUN** (bity 12:8) — proud, když se motor točí.
- **IHOLD** (bity 4:0) — proud, když motor stojí, ale driver je povolený (drží hřídel).
  Typicky zlomek IRUN (T08/T09 používají `IHOLD = IRUN/2`), aby motor v klidu zbytečně
  nehřál.
- **IHOLDDELAY** (bity 19:16) — kolik ~2^IHOLDDELAY taktů čeká po zastavení kroků, než
  proud sníží z IRUN na IHOLD.

Obě hodnoty se přepočítávají ze stejného CS rozsahu, takže platí stejný vzorec i stejná
tabulka výše — jen s jiným CS.

## Co dělá `testing_firmware`

`lib/testkit/testkit.h` + `testkit.cpp`:

```cpp
// Jen vsense=0 (V_fs=0,325 V) - CHOPCONF se nikde nemeni.
uint8_t cs_from_ma(uint16_t ma);   // mA -> CS, 0-31 (klepne na kraje rozsahu)
uint16_t ma_from_cs(uint8_t cs);   // CS -> skutecny mA RMS (po zaokrouhleni CS)
```

T08/T09 se ptají operátora na proud v mA (rozsah 55–1768), přepočítají na CS pomocí
`cs_from_ma()` a do logu vypíšou obojí — zadané mA i skutečně nastavené (`ma_from_cs()` po
zaokrouhlení CS), stejně jako to dělá `FAS_firmware`. Díky zaokrouhlení CS totiž zadaná a
skutečná hodnota většinou nejsou stejné — u kroku ~55 mA to může být rozdíl v jednotkách
procent.

## Jak je to ověřené

- **Rezistory**: přímý pohled na osazenou desku, 2026-07-31 — dva rezistory s potiskem
  `R11` u driveru, po jednom na fázi. Fyzický nález, ne převzatý údaj z dokumentace (viz
  poznámka o READMEs v paměti asistenta — repo dokumentace tady občas neodpovídá realitě).
- **Vzorec a konstanty** (`V_fs`, `+0,02`, `1/√2`): datasheet TMC2209, kapitola IHOLD_IRUN
  / Current settings. Stejné konstanty používá a cituje `FAS_firmware/src/tmc2209.cpp`.
- **Skutečný proud do fáze** (ampérmetrem, ne jen z rezistoru): zatím neověřeno — pokud by
  se vzorcem spočítaná hodnota lišila od naměřené, je to znamení, že `Rsense` na desce
  přece jen není 0,11 Ω (klon s jinou hodnotou), viz `HANDOFF_FAS_firmware.md`.

## Související

- `firmware/FAS_firmware/include/tmc2209.h`, `src/tmc2209.cpp` — stejný přepočet, oba
  rozsahy (`vsense=0` i `1`), plus zápis `vsense` bitu do `CHOPCONF`.
- `firmware/FAS_firmware/README.md` — stejná tabulka z pohledu aplikačního firmwaru.
- `firmware/TMC2209_MS1_MS2.md` (HW-00201) — proč se `CHOPCONF` musí zapisovat opatrně a
  ve správném pořadí vůči `GCONF`.
- `firmware/testing_firmware/lib/testkit/testkit.{h,cpp}` — `cs_from_ma()` /
  `ma_from_cs()`.
- `firmware/testing_firmware/src/tests/t08_motor_move.cpp`,
  `src/tests/t09_motor_jog.cpp` — kde se to používá.

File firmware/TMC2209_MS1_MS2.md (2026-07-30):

# TMC2209: MS1/MS2 určují na této desce zároveň adresu i mikrokrokování
@doc_pwc: file:TMC2209_MS1_MS2.md | id:HW-00201 | created:2026-07-30 | rev:2 | revised:2026-07-30_1744 | type:REF

## Shrnutí

Piny `MS1` a `MS2` mají na TMC2209 **dvě funkce najednou**. Na desce esp32stepper jsou
natvrdo zadrátované pull-upy `R13..R16`, aby každá patice měla jinou UART adresu — a tím
je zároveň, jako vedlejší účinek, každé patici nastavené **jiné rozlišení mikrokroku**.

Aplikační firmware to musí přepsat, jinak budou čtyři osy jezdit ve čtyřech různých
měřítkách. Není to chyba návrhu: adresování se na jednodrátové UART sběrnici bez těchto
pinů udělat nedá. Je to past, která se neprojeví při komunikaci, ale až u pohybu.

## Tabulka

| patice | MS2 | MS1 | UART adresa | mikrokrok po zapnutí |
|---|---|---|---|---|
| BOB-0 | 0 | 0 | 0 | 1/8 |
| BOB-1 | 0 | 1 | 1 | 1/2 |
| BOB-2 | 1 | 0 | 2 | 1/4 |
| BOB-3 | 1 | 1 | 3 | 1/16 |

## Jak je to ověřené

Změřeno 2026-07-30 testem `t06_tmc_uart` na osazené patici BOB-3, ostatní tři patice
tehdy osazené nebyly. Řádek BOB-3 je tedy naměřený, zbytek tabulky je z datasheetu
TMC2209 (tabulka MS2/MS1 → microstep resolution), potvrzený tím, že naměřený řádek na ni
sedí.

```
IOIN=0x2100004D  ver=0x21  MS1/MS2 -> addr 3
GCONF        = 0x00000101
CHOPCONF     = 0x14010053
```

- `IOIN` bit 2 (`MS1`) = 1 a bit 3 (`MS2`) = 1 → adresa 3. Potvrzuje, že `R13..R16`
  fungují tak, jak popisuje `testing_firmware/include/board_pins.h`.
- `GCONF` bit 7 (`mstep_reg_select`) = **0** → rozlišení se bere z pinů, ne z registru.
- `CHOPCONF` bity 24–27 (`MRES`) = **4** → 1/16 mikrokroku. Výchozí hodnota po resetu je
  přitom `MRES = 0`, tedy 1/256. Rozdíl je právě vliv pinů.

## Co s tím musí udělat firmware

U **každého** driveru zvlášť, po navázání UART komunikace:

1. `GCONF` bit 7 `mstep_reg_select = 1` — převezme řízení mikrokroku z pinů do registru.
2. `CHOPCONF` `MRES` nastavit explicitně na požadovanou hodnotu, stejnou pro všechny osy.
3. `GCONF` bit 6 `pdn_disable = 1` — doporučeno pro UART provoz, aby pin `PDN_UART`
   nedělal automatické vypínání při stání. Po resetu je 0.

Adresu naopak přepisovat nelze ani netřeba — čte se z pinů průběžně a je správná.

## Kód pro všechny čtyři drivery

Konfigurace jde po té samé jednodrátové UART sběrnici jako čtení (IO17 → `R19` →
sběrnice → IO18). Registry driveru jsou **volatilní** — žijí jen dokud má driver `VM`.
Po výpadku 24 V se vrátí na výchozí hodnoty a piny zase převezmou mikrokrokování, proto
je součástí kódu i hlídání `GSTAT` bitu 0.

```cpp
// MRES: 0=1/256, 1=1/128, 2=1/64, 3=1/32, 4=1/16, 5=1/8, 6=1/4, 7=1/2, 8=plny krok
static constexpr uint8_t MRES_WANTED = 4;  // 1/16 pro vsechny osy

// Nastavi jeden driver. Cti-uprav-zapis, ne zapis celeho slova - jinak se smazou
// ostatni bity (napr. I_scale_analog v GCONF, ktery driver ma po resetu nastaveny).
bool init_driver(tk::TmcBus& bus, uint8_t node, uint8_t mres) {
  uint32_t gconf = 0;
  if (!bus.read_reg(node, tk::TMC_GCONF, &gconf)) return false;
  gconf |= (1UL << 7);   // mstep_reg_select: MRES z registru, ne z pinu MS1/MS2
  gconf |= (1UL << 6);   // pdn_disable: pin PDN nedela power-down pri stani
  bus.write_reg(node, tk::TMC_GCONF, gconf);

  // POZOR na poradi: dokud je bit 7 nula, cte se MRES z pinu. Jakmile se nastavi,
  // zacne platit registrova hodnota - a ta je po resetu 0, tedy 1/256. Kdyby se
  // MRES nezapsal hned tady, driver by potichu preskocil na 1/256 a motor by se
  // na stejny pocet pulzu otocil 16x min.
  uint32_t chop = 0;
  if (!bus.read_reg(node, tk::TMC_CHOPCONF, &chop)) return false;
  chop = (chop & ~(0xFUL << 24)) | (static_cast<uint32_t>(mres) << 24);
  bus.write_reg(node, tk::TMC_CHOPCONF, chop);

  // Zapis se sam nijak nepotvrzuje - TmcBus::write_reg() vraci true vzdycky.
  // Bud se cte zpatky, jako tady, nebo se hlida IFCNT (0x02), ktery driver
  // inkrementuje po kazdem uspesnem zapisu.
  uint32_t back = 0;
  if (!bus.read_reg(node, tk::TMC_CHOPCONF, &back)) return false;
  return ((back >> 24) & 0xF) == mres;
}

// Vsechny ctyri osy najednou. Vraci pocet uspesne nastavenych driveru.
uint8_t init_all_drivers(tk::TmcBus& bus, uint8_t mres) {
  uint8_t ok = 0;
  for (uint8_t m = 0; m < 4; ++m) {
    if (init_driver(bus, TMC_ADDR[m], mres)) ++ok;
  }
  return ok;
}

// Vola se pravidelne za behu. Driver po vypadku VM zapomene konfiguraci a
// GSTAT bit 0 je jediny zpusob, jak to firmware pozna.
void recover_after_reset(tk::TmcBus& bus, uint8_t mres) {
  for (uint8_t m = 0; m < 4; ++m) {
    const uint8_t node = TMC_ADDR[m];
    uint32_t gstat = 0;
    if (!bus.read_reg(node, tk::TMC_GSTAT, &gstat)) continue;
    if (gstat & 0x01) {                          // reset - konfigurace je pryc
      init_driver(bus, node, mres);
      bus.write_reg(node, tk::TMC_GSTAT, 0x01);  // zachytny bit se maze zapisem 1
    }
  }
}
```

## Známá chyba, kterou to opravuje

`testing_firmware/src/tests/t08_motor_move.cpp` zapisuje

```cpp
bus.write_reg(node, tk::TMC_GCONF, (1UL << 6) | (1UL << 7));
```

Nastaví tedy `mstep_reg_select`, ale `MRES` v `CHOPCONF` už nezapíše — driver tím přeskočí
z 1/16 na 1/256. Navíc je to zápis celého slova, takže přemaže i `I_scale_analog` (bit 0).
Projeví se to jako „motor se skoro nehýbe" nebo „ztrácí kroky" a hledá se to v mechanice.

## Související

- `firmware/testing_firmware/src/tests/t06_tmc_uart.cpp` — test, který tyto hodnoty vypisuje
- `firmware/testing_firmware/include/board_pins.h` — mapa pinů a `TMC_ADDR[]`
- `PCB/esp32stepper.kicad_sch` — `R13..R16`
- `firmware/report.md` (HW-00173), `firmware/FLASH.md` (HW-00174)

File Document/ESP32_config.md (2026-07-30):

# ESP32-S3-WROOM-2 (U1) — measured configuration of this board
@doc_pwc: file:ESP32_config.md | id:HW-00200 | created:2026-07-30 | rev:1 | revised:2026-07-30_0911 | type:REF

Everything in this document was **read off this board**, not copied from a datasheet:

- silicon data with `esptool.py` / `espefuse.py` **v4.5.1** (the copy bundled with PlatformIO,
  `~/.platformio/packages/tool-esptoolpy`) over native USB on **2026-07-30**,
- wiring from the KiCad netlist `PCB/esp32stepper.kicad_pcb`, U1 pad-by-pad.

The BOM (`PCB/esp32stepper.csv`) lists U1 only as `ESP32-S3-WROOM-2` without a memory suffix.
The suffix is **N32R16V** — 32 MB octal flash + 16 MB octal PSRAM, both 1.8 V.

---

## 1. Chip identity

| Item | Value | Source |
|---|---|---|
| Chip | ESP32-S3, revision **v0.2** (`WAFER_VERSION_MAJOR=0`, `WAFER_VERSION_MINOR=2`) | `esptool chip_id` |
| Cores / features | 2 × Xtensa LX7, WiFi + BLE, crystal **40 MHz** | `esptool chip_id` |
| Package | `PKG_VERSION = 0` | eFuse BLOCK1 |
| Factory MAC | `<MAC>` — real value in `./credentials.md` in the repo root (gitignored); `CUSTOM_MAC` is unprogrammed | eFuse BLOCK1 |
| Unique ID | `<UNIQUE_ID>` — real value in `./credentials.md` | eFuse BLOCK2 |
| Calibration | `BLK_VERSION_MAJOR = With calibration`, `BLK_VERSION_MINOR = 4` — ADC1/ADC2 and temperature-sensor calibration present (`TEMP_SENSOR_CAL = -17.9`) | eFuse BLOCK1/2 |
| USB identity on the host | `303a:1001`, `Espressif USB JTAG/serial debug unit <MAC>` (the USB serial string **is** the MAC), appears as `/dev/ttyACM0` | `udevadm`, `lsusb` |

## 2. Memory — measured, not assumed

| Item | Value | How it was established |
|---|---|---|
| Flash size | **32 MB** (256 Mbit) | `esptool flash_id` → `Detected flash size: 32MB` |
| Flash JEDEC ID | `Manufacturer: c2` (Macronix), `Device: 8039` — octal 1.8 V family | `esptool flash_id` |
| Flash bus | **octal, 8 data lines** (`FLASH_TYPE = 1`) | eFuse BLOCK0 |
| PSRAM | **16 MB octal** (`PSRAM_CAP = 0b11`), vendor **AP 1.8 V** (`PSRAM_VENDOR = 0b10`), `PSRAM_TEMP = 1` | decoded from raw BLOCK1, see below |
| `FLASH_CAP` / `FLASH_VENDOR` | `None` / `None` — **expected, not a fault**: on WROOM-2 the flash is a separate die on the module substrate, not inside the chip package, so the in-package capability fuses stay blank | eFuse BLOCK1 |
| VDD_SPI rail | **1.8 V**: `VDD_SPI_XPD = True`, `VDD_SPI_TIEH = Connect to 1.8V LDO`, `VDD_SPI_FORCE = True` → *"Flash voltage (VDD_SPI) set to 1.8V by efuse"* | eFuse BLOCK0 |
| GPIO33…37 supply | `PIN_POWER_SELECTION = VDD_SPI` — those pins are used internally by the octal memories and are **not brought out** (module pads 28/29/30 are `NC`) | eFuse BLOCK0 |
| Flash ECC | `FLASH_ECC_EN = False`, `FLASH_ECC_MODE = 16-byte to 18-byte`, `FLASH_PAGE_SIZE = 0`, `FLASH_TPUW = 0` | eFuse BLOCK0 |

`espefuse.py` v4.5.1 does not name the PSRAM fields, so they were decoded from the raw block.
The dump is recorded here so the decode can be re-checked:

```
MAC_SPI_8M_0 (BLOCK1) read_regs: <MAC_W0> <MAC_W1> 00000000 04080000 64196938 6400d404
    bits 123..125 FLASH_CAP    = 0b000 -> None      bits 128..130 FLASH_VENDOR = 0b000 -> None
    bits 131..132 PSRAM_CAP    = 0b11  -> 16 MB     bits 135..136 PSRAM_VENDOR = 0b10  -> AP_1v8
```

Words 0 and 1 of BLOCK1 are the factory MAC (bits 0…47) and are redacted here — the full dump is in
`./credentials.md`. They are not needed for the decode above: every field shown lives in words 3…5.

This agrees with an independent read using esptool **5.3.1** on 2026-07-29
(`PSRAM_CAP = 16M`, `PSRAM_VENDOR = AP_1v8`), so two tool versions confirm it.

## 3. Build settings that follow from the above

This is what both `firmware/testing_firmware/platformio.ini` and
`firmware/test_simple/platformio.ini` now carry (commit `ffcccbe`, 2026-07-30):

```ini
board                              = esp32-s3-devkitc-1   ; generic S3 base, then override:
board_upload.flash_size            = 32MB
board_build.partitions             = default_16MB.csv     ; or large_littlefs_32MB.csv
board_build.flash_mode             = dout                 ; NOT opi — see below
board_build.arduino.memory_type    = opi_opi              ; octal flash + octal PSRAM
```

- **`flash_mode` is deliberately `dout`, not `opi`.** Neither the 1st- nor the 2nd-stage bootloader
  implements OPI, so the image is loaded in DOUT and the ROM switches the mode according to the
  eFuse (`Octal Flash Mode Enabled`). The only board definition in the platform that uses
  `opi_opi`, `esp32s3camlcd`, does the same thing.
- **A quad configuration does not boot on this board**, contrary to what
  `firmware/testing_firmware/README*.md` used to claim: the ROM turns OPI on from the eFuse, and an
  application built for quad then dies in a reset loop with
  `assert failed: do_core_init startup.c:328 (flash_ret == ESP_OK)`. The "conservative quad common
  denominator" is therefore *not* a safe fallback here — it is simply wrong for an N32R16V.
- The Arduino framework ships **no `default_32MB.csv`**. `default_16MB.csv` runs fine on a 32 MB
  chip (it just leaves the rest unused); `large_littlefs_32MB.csv` is there if more space is needed.
- **Never carry `opi_opi` to the ESP32-S3-DevKitC-1 N8R2** used for earlier bring-up tests: it has
  quad flash and boot-loops with `E cpu_start: Octal Flash option selected, but EFUSE not
  configured!`. The two boards need different configs — do not share one env between them.
- **Never burn eFuses to "fix" a mismatch** — eFuses are one-way, and this module's are already
  correct and factory-consistent.

## 4. eFuse / security state — virgin chip

Nothing is locked, nothing is burned, and the block integrity check passes
(`EFUSE_RD_RS_ERR0/1 = 0x00000000`):

| Fuse | Value |
|---|---|
| `WR_DIS` / `RD_DIS` | `0x00000000` / `0b0000000` — no fuse is write- or read-protected |
| `SECURE_BOOT_EN` | `False` (all three `SECURE_BOOT_KEY_REVOKE*` = `False`) |
| `SPI_BOOT_CRYPT_CNT` | `Disable (0b000)` — flash encryption off |
| `BLOCK_KEY0…5`, `BLOCK_USR_DATA`, `BLOCK_SYS_DATA2` | all zero, purpose `USER` |
| `DIS_DOWNLOAD_MODE`, `DIS_FORCE_DOWNLOAD`, `ENABLE_SECURITY_DOWNLOAD` | `False` — download mode fully available |
| `DIS_USB`, `DIS_USB_JTAG`, `DIS_USB_SERIAL_JTAG`, `USB_PHY_SEL`, `USB_EXCHG_PINS` | `False` — internal PHY, USB-Serial/JTAG enabled, D+/D− not swapped |
| `STRAP_JTAG_SEL` | `False` → JTAG comes from the USB-Serial/JTAG unit; GPIO3 does not select it |
| `UART_PRINT_CONTROL` | `Enabled` — the ROM boot log is printed |
| `SECURE_VERSION` | `0` (no anti-rollback) |
| `SPI_PAD_CONFIG_*` | all `0` — the module uses the default SPI pads |

## 5. How the module is wired on this board

All 41 pads of U1, straight from the netlist. `NC` means the pad is connected to nothing on the
PCB — free for future use, except where noted.

| Pad | Module pin | Net | Function on this board |
|---|---|---|---|
| 1, 40, 41 | GND | `GND` | ground (41 = large thermal pad) |
| 2 | 3V3 | `+3V3` | the only supply rail, see §6 |
| 3 | EN | `reset` | R3 10k pull-up to +3V3, C1 100n to GND, brought out to 2-pin header **J1** (J1.1 = GND, J1.2 = EN) — **no reset button on the board**, short J1 to reset |
| 4 | IO4 | `step0` | STEP → BOB-0 |
| 5 | IO5 | `step1` | STEP → BOB-1 |
| 6 | IO6 | `step2` | STEP → BOB-2 |
| 7 | IO7 | `step3` | STEP → BOB-3 |
| 8 | IO15 | `endswitch2` | end switch 2 (10k pull-up, 10 R in series) |
| 9 | IO16 | `endswitch3` | end switch 3 |
| 10 | IO17 | `/esp32/TX` | TMC2209 single-wire UART **TX**, through R19 1k into the shared bus |
| 11 | IO18 | `UART` | TMC2209 single-wire UART **RX** — bus shared by BOB-0…3 pin 7 |
| 12 | IO8 | `SRCLK` | 74HC595 (U4) shift clock, U4.11 |
| 13 | USB_D−/IO19 | `USB D-` | → U5 USBLC6-2SC6 ESD array → USB-C **USB1** |
| 14 | USB_D+/IO20 | `USB D+` | → U5 USBLC6-2SC6 ESD array → USB-C **USB1** |
| 15 | IO3 | NC | free (strapping pin, see §7) |
| 16 | IO46 | `Net-(U1-IO46)` | **R42 10k to GND** — strapping pin held low |
| 17 | IO9 | `SER` | 74HC595 serial data, U4.14 |
| 18 | IO10 | `RCLK` | 74HC595 latch clock, U4.12 |
| 19 | IO11 | `SCL` | I²C clock (3k3 pull-up R27) → TCA9548A (U6) @ 0x70 |
| 20 | IO12 | `SDA` | I²C data (3k3 pull-up R28) |
| 21 | IO13 | `endswitch0` | end switch 0 |
| 22 | IO14 | `endswitch1` | end switch 1 |
| 23 | IO21 | NC | free |
| 24 | IO47 | NC | free |
| 25 | IO48 | NC | free |
| 26 | IO45 | NC | free (strapping pin, see §7) |
| 27 | IO0 | `Net-(U1-IO0)` | tactile switch **BOOT1** (B3SL-1002P) to GND; internal weak pull-up in the chip |
| 28, 29, 30 | NC | — | not brought out by the module (a WROOM-1 uses these pads for GPIO35/36/37; on WROOM-2 the octal memories use them internally) |
| 31 | IO38 | `IO38` | single-pin header **J4** — the only GPIO deliberately left free |
| 32 | MTCK/IO39 | NC | free (JTAG pad) |
| 33 | MTDO/IO40 | NC | free (JTAG pad) |
| 34 | MTDI/IO41 | NC | free (JTAG pad) |
| 35 | MTMS/IO42 | NC | free (JTAG pad) |
| 36 | RXD0/IO44 | NC | **UART0 RX unconnected** |
| 37 | TXD0/IO43 | NC | **UART0 TX unconnected** |
| 38 | IO2 | `tx_ext` | debug UART **TX** → header **J5.2** |
| 39 | IO1 | `rx_ext` | debug UART **RX** → header **J5.3** (J5.1 = GND) |

Consequences worth spelling out:

- **UART0 (IO43/IO44) goes nowhere on this board.** Never route logging there. The ROM bootloader
  talks on UART0, so an external FTDI cannot flash the board unless it is soldered directly to the
  module pads. The board's debug UART is **IO2/IO1 on J5**, and only application firmware speaks
  on it.
- **There is no USB-UART bridge.** The console is native USB CDC through USB1, so anything printed
  before the host opens the port is lost forever — a freshly attached terminal can show an empty
  screen on a perfectly healthy board.
- **USB1 is device-only**: USB-C receptacle USB4085-GF-A with 5.1k CC1/CC2 pulldowns (R1, R2);
  D+/D− protected by U5; VBUS also feeds the USB LDO.
- **No software-controllable LED.** LED1 hangs off the LT8610's PG pin via NPN1 (BC817-40).
- **IO38 on J4 is the only free brought-out GPIO.** The other free pins (IO3, IO21, IO45, IO47,
  IO48, IO39…IO42) need soldering to the module.
- The authoritative firmware-side copy of this map is
  `firmware/testing_firmware/include/board_pins.h`; the pin table in `firmware/README.md` and the
  legacy `firmware/*.py` scripts disagree and are **wrong for this board**.

## 6. Power — how the module is fed

Two sources OR into one **+3V3** rail; there is no +5V net on this board at all:

```
J2 barrel jack (24Vin) → PMOS1 IRF4905 high-side switch (gate on header J6 "PWR_SWITCH",
                         D3 BZX84B9V1 zener) → 24V_Motor → F2 polyfuse MINISMDC150F-24-2
                       → 24V (TVS0 TSM24A, fan1 header) → U3 LT8610 buck → +3V3 → U1.2
USB1 VBUS              → U2 LDL1117 LDO → D2 BAT54WG → +3V3 → U1.2
```

- The LT8610's BIAS pin is tied to its own +3V3 output; its PG pin drives LED1 through NPN1.
- Motor power is separate downstream of the polyfuse: `24V_Motor` reaches BOB-0…3 `+VM` through
  individual fuses F1, F3, F4, F5.
- **A real power cycle of the module needs USB *and* the barrel jack removed.** Pulling EN low
  (J1) resets the chip but does **not** reset the flash die.

## 7. Strapping pins

| Pin | On this board | Effect |
|---|---|---|
| IO0 | BOOT1 to GND, internal pull-up | boot select: hold BOOT1 and pulse J1 to enter download mode |
| IO46 | R42 10k to GND | held low — ROM message printing stays in its default mode |
| IO45 | floating (NC) | would select the VDD_SPI voltage, but `VDD_SPI_FORCE = True` means **the eFuse wins** and VDD_SPI is 1.8 V regardless of this pin |
| IO3 | floating (NC) | JTAG source select; irrelevant here because `STRAP_JTAG_SEL = False` |

Console and flashing, in one place:

- Upload and monitor over native USB (`/dev/ttyACM0`), `monitor_speed = 115200`.
- `upload_speed` is a no-op over USB-Serial/JTAG — baud only matters for a soldered-on FTDI.
- To force download mode: hold **BOOT1**, short **J1**, release BOOT1, then start the upload.
- An external FTDI on J5 must be **3.3 V**; a 5 V one damages the chip.

## 8. State of this unit

| Date | Finding |
|---|---|
| 2026-07-29 | Nothing could be flashed. `flash_id` returned `Manufacturer: 00 / Device: 0000` with *"Failed to communicate with the flash chip"*, identically across 4 baud rates × stub/no-stub and on both esptool 4.5.1 and 5.3.1; a full chip erase "succeeded" in 0.6 s (32 MB takes tens of seconds); three reads of the same address gave three different MD5s. Diagnosed as a fault on the SPI0↔flash path inside the module. eFuses, board wiring and power design were ruled out. |
| 2026-07-30 | **Recovered after a full power cycle** (module unplugged and reconnected). `flash_id` → `c2 / 8039`, 32 MB detected; three consecutive reads of `0x0…0x10000` returned the identical MD5 `0f546f10a7757fb7dd1f95f2dc4b78f6`. The flash path is healthy again, so the fault was not permanent — if it returns, a cold power cycle (USB **and** barrel jack) is the first thing to try. |
| 2026-07-30 | **First firmware to actually run on this board**: `test_simple` (env `usb_j5`) was flashed and printed `ALIVE #1…#449` over native USB CDC, one line per second, with `Saved PC` in `esp_pm_impl_waiti` — a healthy idle loop. Flashing and the USB CDC console are both proven on this hardware. |

Still open: `firmware/testing_firmware/` test T00 `chip_info` has not been run here, so the flash
size and PSRAM have not yet been confirmed *at runtime* by the firmware itself — everything in §2
comes from the eFuses and the flash ID. T00's two validated runs so far were on an
ESP32-S3-DevKitC-1 N8R2, not on this board.

Note for anyone reading the console log: `esptool` / `espefuse` always reset the chip into download
mode, so an attached `pio device monitor` will show
`rst:0x15 (USB_UART_CHIP_RESET), boot:0x23 (DOWNLOAD(USB/UART0))`, `waiting for download` and then
garbage bytes (ROM bootloader baud ≠ monitor baud). That is the tool, not a crash. Short **J1** or
re-plug USB to get the application running again, and expect port-access collisions if the monitor
is open while esptool runs.

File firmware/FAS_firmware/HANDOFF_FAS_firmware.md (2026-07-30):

# Handoff: vznik FAS_firmware (aplikační firmware, pohyb tam a zpět)
@doc_pwc: file:HANDOFF_FAS_firmware.md | id:HW-00177 | created:2026-07-30 | rev:3 | revised:2026-07-30_1824 | type:NOTE

## Stav

`firmware/FAS_firmware/` je nový adresář, staví čistě (`pio run -e fas`, `-Wall`, 0 warningů,
RAM 6,0 %, Flash 4,5 %). **Na desku nebyl nahrán** — motor se po startu rozjíždí sám, nahrávání si
uživatel chtěl odzkoušet sám až později. Commit `f0f3294` obsahuje první verzi; poslední tři úpravy
(níže) jsou v pracovním stromu, **necommitnuté**.

## Co to je

Nejjednodušší aplikační firmware desky `ieap_motor_firmware` — na rozdíl od `../testing_firmware` (which
se ptá na parametry z konzole) se FAS po zapnutí rozjede sám: nastaví jeden driver TMC2209 po UART,
povolí ho a jede porád dokola *1 otáčka tam → pauza → 1 otáčka zpět → pauza*. Konzole jen vypisuje.

Kompletní popis, výchozí hodnoty a bezpečnostní chování je v
[README.md](README.md) — ten je aktuální, nekopíruj obsah sem znovu.

## Struktura

```
FAS_firmware/
  platformio.ini          jedno prostředí "fas" (default_envs), oktální flash config
  include/board_pins.h    kopie z testing_firmware — držet v souladu, NENÍ symlink
  include/fas_config.h    VŠECHNA nastavení jako constexpr (motor, proud, rychlost, rampa, ...)
  include/tmc2209.h + src/tmc2209.cpp   driver po jednodrátové UART, přepočet mA -> CS
  include/stepper.h + src/stepper.cpp   74HC595 (DIR/EN) + generátor kroků s trapézovou rampou
  src/main.cpp            bring-up, kontroly, smyčka pohybů
  README.md               HW-00176
```

Žádná externí knihovna (`TMCStepper` apod.) — je to pět registrů a stejně by se muselo řešit
zahazování vlastního echa na jednodrátové sběrnici, takže knihovna by nic neušetřila.

## Rozhodnutí, která by mohla překvapit při dalším čtení kódu

- **`move()` blokuje.** Kroky se generují softwarovou smyčkou (`micros()` termíny), ne timerem ani
  RMT. Dokud pohyb neskončí, firmware nedělá nic jiného. Až bude potřeba víc motorů najednou nebo
  souběžné čtení enkodérů, tohle se musí přepsat.
- **Proud se zadává v mA**, ne v CS. `fas_config.h::RUN_CURRENT_MA = 600` → firmware si sám spočítá
  `IRUN=19, vsense=1` → 612 mA RMS skutečně; obojí (zadané i skutečné) vypisuje na konzoli. Klíčová
  proměnná je `R_SENSE_OHM = 0.11` (SilentStepStick/Trinamic BOB) — jiná hodnota na modulu = všechny
  proudy o ten podíl vedle. Neověřeno ampérmetrem, jen podle datasheetu driveru.
- **`GCONF` bit 0 (`I_scale_analog`) je záměrně 0**, ne podle doporučení "čti-uprav-zapiš" z
  HW-00201 níže — s jedničkou by proud škáloval pin `VREF`, který na tomto modulu ani není vyvedený
  (ověřeno v `PCB/tmc2209_driver.kicad_sch`, 17 pinů, `VREF` mezi nimi chybí).
- **`CHOPCONF.MRES` se zapisuje před `GCONF` bitem 7** (`mstep_reg_select`) — opačné pořadí by na
  okamžik nechalo driver jet s `MRES` z resetu (1/256).
- Výchozí motor je slot **BOB-3** (`fas_config.h::MOTOR = 3`) — stejně jako v testech T08/T09, tam
  je fyzicky zapojený motor, na kterém se ověřovalo.

## Co bylo doplněno v tomto sezení (necommitnuto)

Uživatel našel nový dokument `firmware/TMC2209_MS1_MS2.md` (HW-00201, MS1/MS2 dělají na této desce
zároveň UART adresu i mikrokrok po resetu) a chtěl vědět, jestli je pokrytý. Odpověď: většina ano
(mstep_reg_select, explicitní MRES zápis, pdn_disable, ověření přes IFCNT i čtením zpět), ale dvě
věci chyběly a byly doplněny:

1. **Pořadí zápisů v `Tmc2209::configure()`** (`src/tmc2209.cpp`) — `CHOPCONF` teď jde před
   `GCONF`, z důvodu popsaného výše. Předtím to bylo obráceně; funkčně to nejspíš nevadilo (driver
   byl při konfiguraci vždy zakázaný), ale HW-00201 na tom pořadí trvá explicitně.
2. **Nová funkce `driver_survived()`** (`src/main.cpp`) — čte a čistí `GSTAT` po každém pohybu.
   Když `GSTAT.reset` (bit 0) naskočí, driver se restartoval (typicky výpadek 24 V) a ztratil celou
   konfiguraci — mikrokrok zpátky z pinů, proud na výchozí. Předtím se `GSTAT` četlo jen jednou při
   bring-upu a nikdy víc, takže firmware by po výpadku napájení jel dál s tichou domněnkou, že
   konfigurace platí. Teď: zakáže driver, zavolá `configure()` znovu, vynuluje počítadlo polohy
   (hřídel se mohla během výpadku protočit, počítadlo už nic neznamená) a pokud se to nepovede, jde
   do `HALT`.

README.md (`FAS_firmware/README.md`, teď rev 2) má novou sekci "MS1/MS2 dělají adresu i mikrokrok"
shrnující tohle rozhodnutí a odkaz na HW-00201.

**Ověřeno:** čistý build po obou úpravách (`pio run -e fas`, 0 warningů, Flash 294 185 B).
**Neověřeno na hardwaru:** chování `driver_survived()` při skutečném výpadku 24 V — logika je
odvozená z datasheetu (GSTAT bit 0 = reset), ne z pozorování na desce.

## Návrh na opravu v HW-00201 samotném (nehotovo, jen poznámka)

Při čtení dokumentu jsem si všiml jednoho možného nesouladu: HW-00201 doporučuje pro `GCONF`
obecně čti-uprav-zapiš, aby se nesmazal bit 0 (`I_scale_analog`). Pro tuhle desku je to ale opačně
žádoucí — `VREF` není vyvedený, takže bit 0 musí zůstat na 0, ne se zachovávat. Nechal jsem to bez
zásahu do HW-00201 (rev 2), protože to je čistě uživatelovo/dokumentační rozhodnutí, ne kód — jen
na to upozorňuji, kdyby při příštím čtení dokumentu vznikl dojem rozporu s `tmc2209.cpp`.

## Vedlejší poznatky z prozkoumávání repa (mimo scope FAS_firmware)

- Doc-ID rezervace/finalizace (`reserve_doc_id.sh`/`finalize_doc_id.sh`) je v
  `~/ws_ur_surobot/src/ur_surobot_ros2/ur_surobot_documentation/meta/` — používá se přes `flock`,
  registr je `doc_registry.md` tamtéž. Použito pro HW-00176 (rev 1→2) a HW-00177 (tento dokument).
- V `firmware/` vedle `FAS_firmware/` a `testing_firmware/` přibyl needited `blink_nonOctal/` —
  nesouvisí s touto prací, nekontrolováno.
- Git status na začátku sezení ukazoval necommitnuté změny v `testing_firmware/src/tests/
  t08_motor_move.cpp` a nový `t09_motor_jog.cpp` — ty vznikly před tímto sezením, FAS_firmware se
  jich nedotýká.

## Co zbývá (další kroky, žádný nezačat)

- Nahrát na desku a ověřit `driver_survived()` reálně (odpojit/připojit 24 V za běhu).
- Ověřit `R_SENSE_OHM = 0.11` ampérmetrem na skutečném proudu do fáze.
- Zvážit opravu HW-00201 (viz sekce výše) nebo aspoň komentář v dokumentu, že doporučení
  čti-uprav-zapiš pro bit 0 neplatí univerzálně, ale závisí na tom, jestli modul vyvádí `VREF`.

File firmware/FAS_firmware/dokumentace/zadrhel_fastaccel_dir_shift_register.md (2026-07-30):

# Zádrhel: FastAccelStepper a DIR přes shift registr (74HC595)

@doc_pwc: file:zadrhel_fastaccel_dir_shift_register.md | id:HW-00178 | created:2026-07-30 | rev:1 | revised:2026-07-30_1900 | type:NOTE

## Zadání

`Stepper::move()` v `stepper.cpp` je blokující busy-wait smyčka na jeden motor
(viz komentář v `stepper.cpp:4-7`) — bude to potřeba přepsat, až firmware
poběží se čtyřmi motory najednou nebo bude potřeba mezitím číst enkodéry.
FastAccelStepper je knihovna přesně na tuhle situaci: generuje kroky přes
RMT/hardware timer, je neblokující a umí víc motorů souběžně s vlastní
rampou.

## Zádrhel

DIR i EN na desce `esp32stepper` nejdou na holé GPIO, ale přes 74HC595
(`ShiftReg`). FastAccelStepper normálně čeká, že DIR pin je reálný GPIO,
který si sám přepíná.

**První hypotéza byla mylná:** zdálo se, že stačí knihovně DIR pin nedat
(`PIN_UNDEFINED`) a směr si řešit sám kolem `move()` — knihovna si prý i tak
polohu počítá správně, jen fyzicky nic nepřepíná. Ve skutečnosti ale
`FastAccelStepper::move()` bez nastaveného DIR pinu **odmítne záporný pohyb**
rovnou chybou `MOVE_ERR_NO_DIRECTION_PIN` (viz `FastAccelStepper.cpp`,
kontrola `(move < 0) && (_dirPin == PIN_UNDEFINED)`). Tahle cesta tedy nejde.

## Skutečné řešení: externí DIR pin

Knihovna má pro přesně tenhle případ (DIR/EN za externím HW jako shift
registr) vestavěný mechanismus - **externí pin callback**:

- `engine.setExternalCallForPin(bool (*func)(uint8_t pin, uint8_t value))`
  registruje jednu globální callback funkci na `FastAccelStepperEngine`.
- `stepper->setDirectionPin(id | PIN_EXTERNAL_FLAG, dirHighCountsUp)` řekne
  knihovně, že DIR pin `id` je "externí" - při změně směru nezavolá
  `digitalWrite`, ale tuhle callback funkci.
- Callback dostane požadovanou úroveň (0/1) a vrací potvrzenou hodnotu. Náš
  zápis do `ShiftReg` je synchronní (shiftOut + latch), takže potvrzujeme
  hned v jednom volání - žádné další čekání není potřeba.

Implementace: `include/stepper_fastaccel.h` + `src/stepper_fastaccel.cpp`
(`StepperFA::set_dir_pin`). EN se do knihovny neregistruje vůbec (žádný
`setEnablePin`/`setAutoEnable`) a zůstává řízen přímo z `enable()`, stejně
jako u původního `Stepper`.

Jediné pravidlo, které je potřeba dodržet: nikdy nereverzovat na běžícím
motoru (vždy čekat na `!stepper->isRunning()`, než se pošle pohyb opačným
směrem) - `StepperFA::move()` to zajišťuje tím, že je to blokující volání,
stejně jako `Stepper::move()`.

## Ověření

API (`setExternalCallForPin`, `PIN_EXTERNAL_FLAG`, `setDirectionPin`,
`MoveResultCode`) ověřeno čtením zdrojového kódu knihovny přímo na GitHubu
(`gin66/FastAccelStepper`), shodné mezi git tagem `v0.34.0` a `master`
(= PlatformIO registry verze `1.2.7`, viz níže). Mechanismus pro externí
direction pin byl v `1.1.0` interně přepracován (nový `ExtDirPendingState`,
automatická 2ms pauza při změně směru na externím pinu), ale veřejné API se
nezměnilo.

Prototyp přeložen (`pio run -e fas_accel`), ještě NEODZKOUŠENO na reálné
desce/motoru.

## Poznámka k verzi knihovny

`gin66/FastAccelStepper` má dvě nezávislá číslování verzí, která je snadné
zaměnit:

- git tagy na GitHubu: `v0.34.0`, `v0.33.14`, ...
- `library.properties` (to, co čte PlatformIO/Arduino Library registry):
  `1.2.7`

Pro `lib_deps` v `platformio.ini` je rozhodující to druhé -
`gin66/FastAccelStepper@1.2.7`, ne git tag.

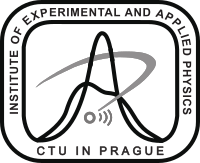
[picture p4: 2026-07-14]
Document/CTU_IEAP_EN_vector_full.eps.png

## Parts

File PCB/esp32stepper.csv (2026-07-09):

Reference | Qty | Value | DNP | Exclude from BOM | Exclude from Board | Footprint | Datasheet
barreljack1 | 1 | PWR |  |  |  | Connector_BarrelJack:BarrelJack_CUI_PJ-063AH_Horizontal | ~
BOB-0,BOB-1,BOB-2,BOB-3 | 4 | ~ |  |  |  | VNfootprints:TMC2209_SilentStepStick
C1,C2,C5,C6,C7,C10,C11 | 7 | 100n |  |  |  | Capacitor_SMD:C_0603_1608Metric_Pad1.08x0.95mm_HandSolder | ~
C3,C13 | 2 | 1u |  |  |  | Capacitor_SMD:C_0603_1608Metric_Pad1.08x0.95mm_HandSolder | ~
C4 | 1 | 4.7u |  |  |  | Capacitor_SMD:C_0603_1608Metric_Pad1.08x0.95mm_HandSolder | ~
C8 | 1 | 10n |  |  |  | Capacitor_SMD:C_0603_1608Metric_Pad1.08x0.95mm_HandSolder | ~
C9 | 1 | 4.7u |  |  |  | Capacitor_SMD:C_0805_2012Metric_Pad1.18x1.45mm_HandSolder | ~
C12 | 1 | 4p7 |  |  |  | Capacitor_SMD:C_0603_1608Metric_Pad1.08x0.95mm_HandSolder | ~
C14 | 1 | 47u |  |  |  | Capacitor_SMD:C_0603_1608Metric_Pad1.08x0.95mm_HandSolder | ~
C15 | 1 | 470n |  |  |  | Capacitor_SMD:C_0603_1608Metric_Pad1.08x0.95mm_HandSolder | ~
C16 | 1 | 22u |  |  |  | Capacitor_SMD:C_0603_1608Metric_Pad1.08x0.95mm_HandSolder | ~
D2 | 1 | BAT54WG |  |  |  | Package_TO_SOT_SMD:SOT-323_SC-70_Handsoldering | ~
D3 | 1 | BZX84B9V1 |  |  |  | Package_TO_SOT_SMD:SOT-23 | ~
encoder0,encoder1,encoder2,encoder3 | 4 | JST-XH-AM 6pin |  |  |  | Connector_JST:JST_XH_B6B-XH-AM_1x06_P2.50mm_Vertical | ~
F2 | 1 | MINISMDC150F_24-2_polyfuse |  |  |  | VNfootprints:polyfuse | http://www.littelfuse.com/~/media/electronics/datasheets/resettable_ptcs/littelfuse_ptc_minismdc_datasheet.pdf.pdf
FB1,FB2,FB3,FB4 | 4 | FerriteBead |  |  |  | Inductor_SMD:L_0603_1608Metric_Pad1.05x0.95mm_HandSolder | ~
J4 | 1 | spare |  |  |  | Connector_PinHeader_2.54mm:PinHeader_1x01_P2.54mm_Vertical | ~
J5 | 1 | UART0 DEBUG |  |  |  | Connector_PinHeader_2.54mm:PinHeader_1x03_P2.54mm_Vertical | ~
L2 | 1 | SPM3012T-1R5M-LR |  |  |  | VNfootprints:SPM3010-3020 | ~
LED1 | 1 | LTST-C170KRKT |  |  |  | LED_SMD:LED_0805_2012Metric_Pad1.15x1.40mm_HandSolder | ~
mot0,mot1,mot2,mot3 | 4 | JST-XH-AM 4pin |  |  |  | Connector_JST:JST_XH_B4B-XH-AM_1x04_P2.50mm_Vertical | ~
PMOS1 | 1 | IRF4905STRLPBF |  |  |  | Package_TO_SOT_SMD:TO-263-2 | https://ngspice.sourceforge.io/docs/ngspice-html-manual/manual.xhtml#cha_MOSFETs
R1,R2 | 2 | 5.1k |  |  |  | Resistor_SMD:R_0603_1608Metric_Pad0.98x0.95mm_HandSolder | ~
R3,R19 | 2 | 1k |  |  |  | Resistor_SMD:R_0603_1608Metric_Pad0.98x0.95mm_HandSolder | ~
R4,R5,R6,R17,R23,R24,R25,R26,R27,R28 | 10 | 3k3 |  |  |  | Resistor_SMD:R_0603_1608Metric_Pad0.98x0.95mm_HandSolder | ~
R7,R18 | 2 | 100k |  |  |  | Resistor_SMD:R_0603_1608Metric_Pad0.98x0.95mm_HandSolder | ~
R8 | 1 | 18k2 |  |  |  | Resistor_SMD:R_0603_1608Metric_Pad0.98x0.95mm_HandSolder | ~
R9 | 1 | 240k |  |  |  | Resistor_SMD:R_0603_1608Metric_Pad0.98x0.95mm_HandSolder | ~
R10 | 1 | 750k |  |  |  | Resistor_SMD:R_0603_1608Metric_Pad0.98x0.95mm_HandSolder | ~
R11,R13,R14,R15,R16,R29,R30,R34,R38,R42 | 10 | 10k |  |  |  | Resistor_SMD:R_0603_1608Metric_Pad0.98x0.95mm_HandSolder | ~
R12 | 1 | 160 |  |  |  | Resistor_SMD:R_0603_1608Metric_Pad0.98x0.95mm_HandSolder | ~
R20,R21,R22,R31,R32,R33,R35,R36,R37,R39,R40,R41 | 12 | 10R |  |  |  | Resistor_SMD:R_0603_1608Metric_Pad0.98x0.95mm_HandSolder | ~
SW1 | 1 | B3SL-1002P |  |  |  | Button_Switch_SMD:SW_SPST_B3SL-1002P | ~
TVS0 | 1 | TSM24ADBZR |  |  |  | Package_TO_SOT_SMD:TSOT-23 | https://www.ti.com/lit/ds/symlink/tsm24a-q1.pdf?ts=1783418861293
TVS1,TVS2,TVS3,TVS4,TVS5,TVS6,TVS7,TVS8,TVS9,TVS10,TVS11,TVS12 | 12 | CDSOD323-T05 |  |  |  | Diode_SMD:D_SOD-323 | https://www.littelfuse.com/~/media/electronics/datasheets/tvs_diode_arrays/littelfuse_tvs_diode_array_sd_c_datasheet.pdf.pdf
U1 | 1 | ESP32-S3-WROOM-2 |  |  |  | RF_Module:ESP32-S3-WROOM-2 | https://www.espressif.com/sites/default/files/documentation/esp32-s3-wroom-2_datasheet_en.pdf
U2 | 1 | LDL1117_SOT223 |  |  |  | Package_TO_SOT_SMD:SOT-223-3_TabPin2 | http://www.st.com/st-web-ui/static/active/en/resource/technical/document/datasheet/CD00000544.pdf
U3 | 1 | LT8610 |  |  |  | Package_SO:MSOP-16-1EP_3x4.039mm_P0.5mm_EP1.651x2.845mm_ThermalVias | https://www.analog.com/media/en/technical-documentation/data-sheets/lt8610.pdf
U4 | 1 | 74HC595D |  |  |  | Package_SO:SOIC-16_3.9x9.9mm_P1.27mm | http://www.ti.com/lit/ds/symlink/sn74hc595.pdf
U5 | 1 | USBLC6-2SC6 |  |  |  | Package_TO_SOT_SMD:SOT-23-6 | https://www.st.com/resource/en/datasheet/usblc6-2.pdf
U6 | 1 | TCA9548APWR |  |  |  | Package_SO:TSSOP-24_4.4x7.8mm_P0.65mm | http://www.ti.com/lit/ds/symlink/tca9548a.pdf
USB1 | 1 | USB4085-GF-A_REVA4 |  |  |  | VNfootprints:GCT_USB4085-GF-A_REVA4

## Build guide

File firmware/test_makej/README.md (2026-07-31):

# test_makej

Non-interactive PlatformIO project derived from `../testing_firmware`
(specifically from `t08_motor_move.cpp`). Instead of prompting the operator
for parameters at runtime, it drives all four motor channels (0-3) one after
another using fixed compile-time constants (the same defaults `t08` used as
prompt fallbacks): `STEPS`, `STEP_RATE_HZ`, `CURRENT_MA`. For each channel it
computes the 74HC595 shift-register value that enables just that motor's
driver, configures the TMC2209 over UART (current, microstep resolution),
and runs a step burst.

`include/board_pins.h` and `lib/testkit/` are standalone copies of the ones
in `testing_firmware` - editing one project does not affect the other.

See `doc/heureka.md` for the debugging history behind this project (why it
didn't move at first, and the microstep-resolution bug that was found by
comparing against a known-working reference implementation).

## Building

`pio` is not on `PATH` when PlatformIO is only installed as the VSCode
extension - it lives at `~/.platformio/penv/bin/pio`. The `Makefile` in this
directory already accounts for that.

```bash
make            # same as `make build`
```

Flashing does **not** go through `pio run -t upload` - esptool 4.5.1 bundled
with PlatformIO crashes on this board with `BrokenPipeError`. Flashing is
done separately via `../flash.sh`; see `../FLASH.md` for the full story.

## Makefile targets

| Target | What it does |
|---|---|
| `make build` (default) | `pio run` - compiles the firmware, does not touch the board. |
| `make flash` | Builds, then runs `../flash.sh -d .` - checks flash health and writes bootloader, partitions, and app to the board. |
| `make check` | Runs `../flash.sh -d . --check` - only reads back flash diagnostics (manufacturer/device ID, size, mode), writes nothing. Use this first if the board is behaving oddly. |
| `make monitor` | `pio device monitor` - opens the serial console (native USB, same port used for flashing). |
| `make clean` | `pio run -t clean` - removes `.pio/build/test_makej`. |

## Hardware notes

- Board: ESP32-S3-WROOM-2 N32R16V (32 MB octal flash, octal PSRAM) - the
  memory config in `platformio.ini` (`dout` flash mode, `opi_opi` PSRAM,
  `default_16MB.csv` partitions) is not optional, see the comments there.
- Console is native USB CDC (`Serial`), not the board's Debug UART0 header -
  that was tried and reverted, see `doc/heureka.md`.
- Motor current is set purely over the TMC2209 UART (`IHOLD_IRUN`) - there is
  no VREF potentiometer on this board.

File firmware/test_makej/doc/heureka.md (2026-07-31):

# heureka.md - vznik test_makej a hledani, proc se motor nehybe

Zaznam konverzace, ve ktere vznikl projekt `test_makej` a resil se bug "motor
stoji na miste". Pro budouci referenci, kdyby se podobny problem opakoval
nebo kdyby bylo potreba pochopit, proc je kod takovy, jaky je.

## Jak se builduje testing_firmware / test_makej

`pio` neni v PATH, kdyz je PlatformIO nainstalovane jen jako VSCode extension -
zije v `~/.platformio/penv/bin/pio`. Bud pouzit plnou cestu, nebo si pridat do
`~/.bashrc`:

```bash
export PATH="$HOME/.platformio/penv/bin:$PATH"
```

Build (bez flashovani):

```bash
cd firmware/test_makej    # nebo firmware/testing_firmware
pio run
```

Flashovani NE pres `pio run -t upload` (esptool 4.5.1 v PlatformIO padá na
`BrokenPipeError`), ale pres `firmware/flash.sh -d firmware/test_makej` - viz
`../FLASH.md`.

## Vznik test_makej

Zalozeno na `testing_firmware` (konkretne na `t08_motor_move.cpp`), ale bez
interaktivnich promptu - parametry, na ktere se t08 normalne ptalo pres
`tk::read_int()`, jsou tady pevne dane konstanty:

- `MOTOR = 3`, `STEPS`, `STEP_RATE_HZ = 800`, `CURRENT_MA = 500`
- `SHIFT_REG_VALUE = SR_ALL_DISABLED & ~(1u << SR_BIT_EN[MOTOR])` - povoli
  driver zvoleneho motoru, ostatni zustanou zakazane, vsechny DIR v L.

Struktura: `include/board_pins.h` a `lib/testkit/` jsou kopie z
`testing_firmware` (samostatna kopie, ne sdileny kod - zmeny v jednom projektu
neovlivni druhy).

## Bug #1 - zadny pohyb vubec (chybely STEP pulzy)

Prvni verze `main.cpp` jen zapsala posuvny registr a vypsala konstanty na
konzoli - **nikdy nevygenerovala zadny pulz na STEP pin**. Motor logicky stal,
protoze ho nemel duvod se hnout. Doplneno: `step_burst()` (stejna logika jako
v t08) + inicializace TMC2209 pres UART (`GCONF`, `IHOLD_IRUN`,
`TPOWERDOWN`) - bez UART zapisu jede driver na resetovy proud, deska nema
VREF potenciometr, CS se nastavuje jen pres UART.

## Bug #2 - konzole nevidet (slepa ulicka s Debug UART0)

Zkousel jsem presmerovat konzoli z nativniho USB CDC na "Debug UART0"
(`Serial0`, piny podle `board_pins.h`). Nejdriv se predpokladalo IO1/IO2
podle puvodniho komentare v `board_pins.h`, pak podle uzivatelova popisu
schematu opraveno na IO43/IO44 (skutecny vychozi UART0 - `U0TXD`/`U0RXD`).
Ani po opravě pinu se ale aplikacni vypis neobjevil - videt byl porad jen ROM
boot log (`rst:0x15 (USB_UART_CHIP_RESET)`, `boot:0x8 ...`), ktery se
vypisuje vzdy pres nativni USB nezavisle na tom, co dela appka.

**Zavěr:** presmerovani na Debug UART0 zruseno, konzole vracena zpatky na
nativni USB CDC (`Serial`, presne jako v `testing_firmware`) - to je port,
ktery uzivatel uz prokazatelne pouziva pro flashovani a kde vidi ROM log, tedy
zadne dalsi zapojeni netreba. Pokud by se v budoucnu Debug UART0 chtelo znovu
zprovoznit, je potreba nejdriv overit multimetrem/logickym analyzatorem, ze
na IO43/44 skutecne nekdo (adapter) poslouchá - jinak neni jak overit, jestli
je chyba v pinech, nebo proste nikdo na druhe strane neni.

## Bug #3 - motor se hybe jen nepatrne (CHOPCONF.MRES)

Uzivatel prinesl referencni Python projekt
(`Temp/TMC2209_ESP32-main/test_script_03_basic_movement.py` a
`tmc/TMC_2209_StepperDriver.py`) jako znamy funkcni priklad inicializace
TMC2209. Srovnanim s nasim kodem:

- **Skutecna prezinat priciny "motor stoji":** `GCONF.mstep_reg_select=1` (uz
  jsme meli) rika driveru, at bere mikrokrokove rozliseni z `CHOPCONF`, ne z
  MS1/MS2 pinu. V resetu je ale `CHOPCONF.MRES = 0` = **256 mikrokroku na
  krok**, zatimco `step_burst()` generuje pulzy s predstavou "1 pulz = 1 cely
  krok". Vysledek: 400 pulzu na STEP = jen 400/256 ≈ 1,6 skutecneho kroku
  motoru - prakticky neznatelne. Oprava: cist-modifikovat-zapsat `CHOPCONF`,
  nastavit `MRES=8` (1 mikrokrok = 1 plny krok, odpovida tomu, jak generujeme
  pulzy) a `intpol=1` (interni vyhlazeni).

- **Co jsme z referencniho skriptu zamerne NEkopirovali:**
  - `setIScaleAnalog(True)` - prepne proudovou referenci na externi VREF pin,
    ktery nase deska nema zapojeny (proud se u nas ridi cistě pres UART
    `IHOLD_IRUN`, internal reference). Prevzeti by proud spis rozbilo.
  - `setVSense(True)` - meni referencni napeti pro vypocet CS; nas
    `tk::cs_from_ma()` pocita s `vsense=0` (overeno primo na desce merenim
    Rsense), takze by tenhle prepinac propocet proudu rozladil.

- **Bitova mapa 74HC595 (U4) potvrzena schematem** od uzivatele: QA→dir0,
  QB→en0, QC→dir1, QD→en1, QE→dir2, QF→en2, QG→dir3, QH→en3, `~OE` na GND,
  `~SRCLR` na 3V3 - presne odpovida `SR_BIT_DIR`/`SR_BIT_EN` v
  `board_pins.h`. Zadny bug v mapovani bitu.

Stejna MRES chyba (bod "Bug #3") je pravdepodobne i v originalnim
`testing_firmware/src/tests/t08_motor_move.cpp` - nebylo tam zatim opraveno,
cekalo se na potvrzeni od uzivatele.

## Otevrene body k dalsimu overeni

- Po oprave MRES: overit na desce, jestli se motor uz toci normalne a jestli
  odber odpovida nastavenemu proudu (drive hlaseno jako "maly odber, jako by
  byl odpojeny").
- Rozhodnout, jestli opravit stejnou MRES chybu i v puvodnim
  `t08_motor_move.cpp` (testing_firmware).

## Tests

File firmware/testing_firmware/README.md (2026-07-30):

# esp32stepper — hardware bring-up test suite

Test suite for the custom 4-channel stepper board (ESP32-S3-WROOM-2 + 4× TMC2209
SilentStepStick). **This is not application firmware** — it is a ladder of tests that prove the
board works, one subsystem at a time.

Czech version of this document: [README_CZ.md](README_CZ.md)

---

## ⚠️ Status: only the first two tests are validated

| Tests | State |
|---|---|
| **T00 `chip_info`, T01 `blink_io38`** | run on real hardware, debugged, behave as documented |
| **T02 … T09** | compile, never executed on hardware — PASS/FAIL logic is unverified |

**Do not run T02 and above on a fresh board.** They drive the shift register, the STEP pins, the
TMC UART and (T08, T09) an actual motor; on an untested board an unvalidated test can just as easily
be wrong about the board as the board is about the test, and T08/T09 move mechanics. Bring a new
board up
with T00 and T01 only, and treat everything above as code that still needs review before its first
run.

The two validated tests were run on an **ESP32-S3-DevKitC-1 N8R2**, not on the target board.

> **The DevKit and the target board now need different memory settings.** The target module is
> confirmed to be an **ESP32-S3-WROOM-2 N32R16V** (32 MB octal flash + 16 MB octal PSRAM, 1.8 V),
> and `platformio.ini` is configured octal for it. That config **will not boot on the N8R2 DevKit**,
> which has quad flash. Flip `flash_mode`/`memory_type`/`flash_size` back to `dout` + `qio_qspi` +
> `8MB` when returning to the DevKit. See [../report.md](../report.md).

---

## Requirements

- [PlatformIO](https://platformio.org/) CLI (`pio`) — the `espressif32` platform is fetched on
  first build
- USB-C cable to the board's **USB1** connector (native USB CDC on IO19/IO20)
- 24 V on the barrel jack only for T06 (optional) and T08 / T09 (required)

All commands below run from this directory (`firmware/testing_firmware/`).

## Quick start

```bash
pio run -e menu -t upload && pio device monitor
```

That flashes a binary containing every test plus an interactive menu, then opens the console. This
is the usual flow — you flash once and pick tests over USB, without reprogramming between them.

> **`-t upload` is unreliable on the target board.** PlatformIO bundles esptool 4.5.1, which dies
> with `BrokenPipeError: [Errno 32] Broken pipe` on this board's octal flash over native
> USB-Serial/JTAG — especially while the chip is resetting. Build with `pio run` and flash with a
> **standalone esptool 5.3.1**; the exact command is in [../report.md](../report.md).

## Flashing with `../flash.sh --help`

Because of the above, flashing goes through [../flash.sh](../flash.sh) — idempotent and
machine-agnostic: it finds (or installs) `pio` and esptool ≥ 5.3.1, checks the flash and only then
writes all four regions. The procedure and the manual fallback are in [../FLASH.md](../FLASH.md).

`--help` prints the usage **and what each test does**; `--list` prints just that list. Both are read
out of `platformio.ini` and `src/test_registry.cpp` — the same source the board's console menu uses,
so the list cannot drift from the firmware.

```text
$ ../flash.sh --help
flash.sh - nahrani firmware do desky esp32stepper (ESP32-S3-WROOM-2 N32R16V).

Proc to nejde pres "pio run -t upload" a co delat, kdyz to nejde vubec, je
ve FLASH.md (HW-00174) a report.md (HW-00173).

Skript je zamerne IDEMPOTENTNI a nic nepredpoklada o stroji: sam si najde
pio i esptool, na novem stroji je dotahne, na uz pouzitem jen zkontroluje
verzi. Nic nemaze a nesaha na efuse.

Pouziti:
  firmware/flash.sh                                  # projekt = aktualni adresar, env = default_envs
  firmware/flash.sh -d firmware/testing_firmware     # projekt explicitne
  firmware/flash.sh -d firmware/test_simple -e usb_j5
  firmware/flash.sh -p /dev/ttyACM1                  # kdyz je pripojenych vic desek
  firmware/flash.sh --check                          # jen diagnostika flash, NIC nezapisuje
  firmware/flash.sh --no-build                       # pouzij uz prelozeny build
  firmware/flash.sh --help                           # tenhle text + co ktery test dela
  firmware/flash.sh --list                           # jen seznam prostredi a testu

--help i --list vypisou prostredi, ktera jde dat za -e, a u testu i to, co
overuji a co k tomu musi byt pripojene - tedy to same, co vypise menu na
konzoli desky. Bez -d se to vezme z aktualniho adresare, jinak ze vsech
projektu vedle skriptu.

Prepsat cestu k venv jde promennou ESPTOOL_VENV.

prostredi pro -e v <repo>/firmware/testing_firmware:
 * menu                 Vychozi prostredi: vsechny testy + menu na konzoli.
   t00_chip_info        hlasi se cip, sedi flash/PSRAM varianta
                          potreba: jen USB
   t01_blink_io38       GPIO vystup na pinu J4
                          potreba: LED+330R nebo multimetr
   t02_shift_register   74HC595 budi DIR a EN
                          potreba: sonda na patky BOB
   t03_step_pins        STEP pulsy na IO4..IO7
                          potreba: osciloskop
   t04_endswitches      koncove spinace IO13..IO16
                          potreba: spinace, ruka
   t05_i2c_scan         TCA9548A a kanaly enkoderu
                          potreba: nic / enkodery
   t06_tmc_uart         drivery odpovidaji na UART
                          potreba: osazene BOB-0..3
   t07_wiring_selftest  DIR/EN/STEP overene ctenim IOIN
                          potreba: osazene BOB-0..3
   t08_motor_move       skutecny pohyb jednoho motoru
                          potreba: 24 V + motor   POZOR: hybe motorem
   t09_motor_jog        pusteni motoru a jednoduche pohyby po krocich
                          potreba: 24 V + motor   POZOR: hybe motorem
   * = default_envs, pouzije se bez -e
```

Without `-d` the list comes from the current directory; run it from the repo root and it lists every
project next to the script (`testing_firmware` and `test_simple`).

### The console starts blank — that is normal

The board has **no USB-UART bridge**; the console is native USB CDC. Anything printed before your
terminal opens the port is lost forever, so a freshly attached monitor can show an empty screen on
a perfectly healthy board.

**Press Enter.** The menu re-prints its prompt every 2 s until the first byte ever arrives, so
within two seconds you will see either the prompt or the whole menu.

## Using the menu

```
test> 0        run a single test by number
test> a        run every test that does not move a motor (skips T08 and T09)
test> ?        print the menu again
```

In sequence mode a failing test stops and asks whether to continue. Individual tests are
interactive: they ask for parameters (`perioda [ms]`, `frekvence [Hz]`, …, Enter accepts the
default in brackets) and ask you to confirm what you observed. Results are printed as
`[ OK ]` / `[FAIL]` / `[WARN]` and summed up at the end of each test.

Tests that loop can be stopped by pressing any key.

## Single-test binaries

Every test also has its own environment, containing nothing but that test and `main.cpp`:

```bash
pio run -e t00_chip_info -t upload && pio device monitor
```

Use these when the board hangs, browns out or resets during a test — the binary then contains
nothing else that could be to blame. The single-test build runs the test immediately after boot and
repeats it on any keypress.

## Build without flashing

`menu` is `default_envs`, so a bare `pio run` builds only that. To check that everything still
compiles, list the envs explicitly:

```bash
pio run -e menu -e t00_chip_info -e t01_blink_io38 -e t02_shift_register -e t03_step_pins \
        -e t04_endswitches -e t05_i2c_scan -e t06_tmc_uart -e t07_wiring_selftest \
        -e t08_motor_move -e t09_motor_jog
```

Compiling every env is the only automated gate — there is no host-side test suite and no CI.

```bash
pio run -t clean     # drop build artifacts
pio device list      # find the serial port if auto-detection fails
```

## The test ladder

Each test assumes the ones before it passed. `src/test_registry.cpp` is the authoritative list.

| # | Test | Proves | Needs | Validated |
|---|---|---|---|---|
| 00 | `chip_info` | chip boots, USB CDC console works, flash size / PSRAM / reset reason | just USB | ✅ |
| 01 | `blink_io38` | a GPIO output really toggles a pin | external LED + 330 R or a meter on J4 | ✅ |
| 02 | `shift_register` | 74HC595 drives DIR and EN | meter/probe on the BOB pads | ❌ |
| 03 | `step_pins` | STEP pulses on IO4…IO7 | scope or logic analyzer | ❌ |
| 04 | `endswitches` | IO13…IO16 read both H and L | end switches, a hand | ❌ |
| 05 | `i2c_scan` | TCA9548A at 0x70, per-channel encoder scan | nothing / encoders | ❌ |
| 06 | `tmc_uart` | all four drivers answer, `VERSION = 0x21`, MS1/MS2 addressing | populated BOB-0…3 | ❌ |
| 07 | `wiring_selftest` | DIR/EN/STEP wiring, **verified automatically** | populated BOB-0…3 | ❌ |
| 08 | `motor_move` | a motor actually turns | 24 V + motor, free mechanics | ❌ |
| 09 | `motor_jog` | motor runs on command: simple moves entered as step counts | 24 V + motor, free mechanics | ❌ |

**T09 is the one you will live in.** T08 answers "does it turn at all"; T09 keeps the driver
configured and enabled and lets you issue moves from the console, all in **steps** (a step is one
microstep at the configured resolution — at 1/16 a revolution of a 200-step motor is 3200 steps).
It defaults to the motor in **slot 03**, the one wired up for bring-up. Parameters asked up front:
motor, `IRUN`, microsteps, steps per move, steps per second.

| key | what it does |
|---|---|
| `f` / `b` | move the configured step count, direction A / B |
| `F` / `B` | a single step, direction A / B (fine positioning) |
| `n` | one-off step count and direction |
| `d` / `v` | change steps per move / rate in steps per second |
| `+` / `-` | rate ±25 % |
| `t` | there-and-back 3× — backlash and lost steps |
| `c` / `C` | run continuously in A / B until a key is pressed |
| `s` | ramp: accelerate to 2× the rate and decelerate back |
| `a` / `u` | change the `IRUN` current / microstep resolution |
| `m` | switch motor (the previous driver is released first) |
| `0` | zero the position counter — "this is the start" |
| `i` | driver status (`DRV_STATUS`, `IOIN`, `IFCNT`) and end-switch level |
| `r` | quit and run the test again from the start (new parameters) |
| `x` | quit — driver disabled, results evaluated |

The position counter runs in steps from the start (`+` = direction A) and is printed after every
move, so a symmetric move that ends off the mark is a lost-step count you can read. The end switch
of the selected motor stops any move — but only if it reads H at rest; if nothing is wired there,
guarding is switched off and the only stop is a keypress.

**T07 is the one worth understanding.** The TMC2209's `IOIN` register reads back the levels of its
own DIR / ENN / STEP input pins, so the firmware can set a level through the shift register or a
GPIO and read it back over the UART. That closes the loop on the whole signal path — shift-register
bit order, cold joints, swapped STEP pins, wrong driver address — with no scope and with the motors
stationary. Prefer extending T07 over adding another probe-and-eyeball test.

## Safety

- `main.cpp` calls `tk::safe_state()` before and after every test: STEP pins low, all drivers
  disabled (`SR = 0xAA`).
- **EN is active-low** (the SilentStepStick's `ENN`); `0` enables a driver. The 74HC595's `~OE` is
  hard-tied to GND, so it drives its outputs the instant the ESP32 boots — a known-safe byte is
  pushed out first.
- T02 briefly enables each driver in turn (holding torque, current draw) and asks before doing so.
  T03 and T07 keep all drivers disabled, so nothing moves even with 24 V connected.
- **Only T08 and T09 move a motor.** Both ask for the motor, step count, rate and `IRUN` current and
  refuse to start until you confirm the mechanics are clear; T09 additionally stops on the selected
  motor's end switch and on any keypress. Both are flagged `moves_motor` in `src/test_registry.cpp`,
  and sequence mode (`a`) skips everything carrying that flag.
- There is **no software-controllable LED** on the board (LED1 hangs off the LT8610's PG pin via an
  NPN). IO38 is brought out to the single-pin header J4 only.

## Pin map

`include/board_pins.h` is the **only correct pin map** — read off the netlist and re-verified
pad-by-pad against `PCB/esp32stepper.kicad_pcb`.

| Signal | GPIO |
|---|---|
| STEP0…3 | 4, 5, 6, 7 (direct GPIO → BOB-0…3) |
| 74HC595 SRCLK / SER / RCLK | 8 / 9 / 10 |
| I2C SCL / SDA | 11 / 12 |
| End switch 0…3 | 13, 14, 15, 16 |
| TMC2209 UART TX / RX | 17 / 18 |
| Debug UART TX / RX (header J5) | 2 / 1 |
| Spare (header J4) | 38 |

Historically two other sources in this repo disagreed and were wrong for this board: a table in
`firmware/README.md` and a set of legacy MicroPython `firmware/*.py` scripts written from a guess at
the schematic, before the board existed. **Neither is in the repo as of 2026-07-30** — `firmware/`
holds only `testing_firmware/` and `test_simple/`. If either ever reappears, do not copy pin numbers
from it.

The DIR/EN bit order in the shift register is **interleaved, not blocked**: writing MSB-first,
`bit0→QA=dir0, bit1→QB=en0, bit2→QC=dir1, bit3→QD=en1, …`. Use `SR_BIT_DIR[]` / `SR_BIT_EN[]`,
never hand-rolled shifts.

## Troubleshooting

**Console stays blank.** Expected — press Enter (see above). `HWCDC::operator bool()` only reports
whether the USB *cable* is plugged in, so the firmware cannot detect your terminal attaching.

**Boot loops with `E cpu_start: Octal Flash option selected, but EFUSE not configured!`**
An octal config (`memory_type = opi_opi`) is running on a module with **quad** flash — typically the
ESP32-S3-DevKitC-1 N8R2. Switch to `dout` + `qio_qspi` + `8MB` + `default_8MB.csv` for that DevKit.

**Boot loops with `assert failed: do_core_init startup.c:328 (flash_ret == ESP_OK)`**
The mirror image of the above, and this README used to claim it could not happen: a **quad** config
on the **octal** target module. The ROM reads the efuse and enables OPI (`Octal Flash Mode Enabled`
appears in the boot log), the quad-built app then fails to init the flash and aborts. Use the
committed octal settings (`dout`, `opi_opi`, `32MB`, `default_16MB.csv`).

There is **no quad/octal common denominator** — the two boards genuinely need different settings.
T00 reports the flash size actually found.

**T00 warns that PSRAM was not found.** A `warn`, not a `fail` — no test in the ladder needs PSRAM.
On the target N32R16V module there are 16 MB of octal PSRAM and `-DBOARD_HAS_PSRAM` is set, so a
warning here means something is genuinely off. On the N8R2 DevKit with a quad config it is expected.

**T00 reports a brownout reset.** Power supply is inadequate or sagging — fix that before running
anything that enables a driver.

**Upload cannot find the port.** `pio device list` to see what is there. Hold `BOOT1` while plugging
USB in to force download mode. (The board's reset/BOOT hardware is not fully documented — the BOM
lists only `SW1`, which the schematic draws as an SPDT power switch, plus a 2-pin header `J1`.
Verify against the schematic before relying on a particular button.)

**`Failed to communicate with the flash chip` / `Manufacturer: 00`, or writes that verify as empty.**
Two separate flash-level faults, both recoverable and both explained step by step with commands in
[../report.md](../report.md): the flash left stuck in OPI mode (needs a full power removal — USB
*and* the barrel jack), and block-protect bits set in the flash status register (needs
`esptool write-flash-status`). Neither means the module is dead.

**UART0 (IO43/IO44) is physically unconnected.** Never route logging there — it goes nowhere on
this board.

## Adding a test

Three places, all required:

1. `src/tests/tNN_name.cpp` defining `void tNN_name()` — no arguments, returns when done.
2. A row in `src/test_registry.cpp` (name, what it proves, what must be connected).
3. A declaration in `src/test_registry.h` and an `[env:tNN_name]` section in `platformio.ini`.

Conventions that keep the suite usable as a bring-up tool:

- Start with `tk::reset_results()` and `tk::banner()`, end with `tk::summary()`.
- Report through `tk::pass/fail/warn/info` — `pass`/`fail` feed the counters sequence mode uses to
  decide whether to stop.
- Leave the board in a safe state on every exit path; a test that enables a driver must disable it
  itself.
- A loop must poll `tk::key_pressed()` so the operator can get out.
- A blocking wait must use `main.cpp`'s `wait_for_input()` pattern, not a bare
  `while (!Serial.available())`.
- Shared hardware helpers (`ShiftReg`, `TmcBus`, console) belong in `lib/testkit/`, not in tests.
- Comments and console output are Czech and ASCII-only (no diacritics) — some terminals mangle
  UTF-8 over USB CDC.

## Layout

```
platformio.ini          envs: menu (default) + one per test
include/board_pins.h    authoritative pin map, shift-register bit map
lib/testkit/            console, result counters, ShiftReg, TmcBus, safe_state
src/main.cpp            interactive menu, or single-test entry via -DTEST_ENTRY
src/test_registry.*     the list the menu prints
src/tests/tNN_*.cpp     one test per file
```

See [../report.md](../report.md) for the hardware facts that constrain this firmware — module
variant, memory settings, and the flashing procedure.

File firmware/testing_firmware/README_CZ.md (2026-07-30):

# esp32stepper — sada testů hardwaru (bring-up)

Testovací sada pro vlastní čtyřkanálovou desku se stepper drivery (ESP32-S3-WROOM-2 + 4× TMC2209
SilentStepStick). **Nejde o aplikační firmware** — je to žebřík testů, který postupně, jeden
podsystém po druhém, dokazuje, že deska funguje.

English version: [README.md](README.md)

---

## ⚠️ Stav: odladěné jsou zatím jen první dva testy

| Testy | Stav |
|---|---|
| **T00 `chip_info`, T01 `blink_io38`** | spuštěné na reálném hardwaru, odladěné, chovají se podle dokumentace |
| **T02 … T09** | přeloží se, na hardwaru nikdy neběžely — logika PASS/FAIL je neověřená |

**Na nové desce nedoporučuji zkoušet T02 a výš.** Budí posuvný registr, STEP piny, TMC UART a (T08,
T09) skutečný motor; na neoživené desce se stejně snadno může mýlit neověřený test jako deska, a T08
s T09 navíc rozhýbou mechaniku. Novou desku oživuj jen testy T00 a T01, na všechno ostatní se koukej jako
na kód, který si před prvním spuštěním zaslouží revizi.

Ty dva odladěné testy běžely na **ESP32-S3-DevKitC-1 N8R2**, ne na cílové desce.

> **DevKit a cílová deska teď potřebují jiné nastavení pamětí.** Varianta cílového modulu je
> potvrzená: **ESP32-S3-WROOM-2 N32R16V** (32 MB oktální flash + 16 MB oktální PSRAM, 1,8 V) a
> `platformio.ini` je pro ni nastavené oktálně. Tahle konfigurace **na DevKitu N8R2 nenabootuje**,
> protože ten má quad flash. Při návratu na DevKit přepni `flash_mode`/`memory_type`/`flash_size`
> zpátky na `dout` + `qio_qspi` + `8MB`. Viz [../report.md](../report.md).

---

## Co je potřeba

- [PlatformIO](https://platformio.org/) CLI (`pio`) — platformu `espressif32` si stáhne sám při
  prvním buildu
- kabel USB-C do konektoru **USB1** na desce (nativní USB CDC na IO19/IO20)
- 24 V na barrel jack až pro T06 (nepovinně) a T08 / T09 (povinně)

Všechny příkazy níže se spouští z této složky (`firmware/testing_firmware/`).

## Rychlý start

```bash
pio run -e menu -t upload && pio device monitor
```

Nahraje binárku, která obsahuje všechny testy plus interaktivní menu, a otevře konzoli. To je běžný
režim — nahraje se jednou a testy se pak vybírají po USB, bez přeprogramování mezi nimi.

> **`-t upload` na cílové desce nefunguje spolehlivě.** PlatformIO má v sobě esptool 4.5.1, který na
> oktální flash přes nativní USB-Serial/JTAG padá na `BrokenPipeError: [Errno 32] Broken pipe`,
> zvlášť když se čip zároveň resetuje. Přelož přes `pio run` a nahraj **samostatným esptoolem
> 5.3.1**; přesný příkaz je v [../report.md](../report.md).

## Nahrávání a `../flash.sh --help`

Kvůli tomu výše se nahrává skriptem [../flash.sh](../flash.sh) — je idempotentní a nic
nepředpokládá o stroji: najde (nebo doinstaluje) `pio` a esptool ≥ 5.3.1, zkontroluje flash a teprve
pak zapíše všechny čtyři regiony. Postup i ruční varianta jsou ve [../FLASH.md](../FLASH.md).

`--help` vypíše nápovědu **a k tomu co který test dělá**, `--list` jen ten seznam. Oboje se čte
z `platformio.ini` a `src/test_registry.cpp`, tedy ze stejného zdroje, ze kterého ho vypisuje menu na
konzoli desky — seznam se proto nemůže rozejít s firmwarem.

```text
$ ../flash.sh --help
flash.sh - nahrani firmware do desky esp32stepper (ESP32-S3-WROOM-2 N32R16V).

Proc to nejde pres "pio run -t upload" a co delat, kdyz to nejde vubec, je
ve FLASH.md (HW-00174) a report.md (HW-00173).

Skript je zamerne IDEMPOTENTNI a nic nepredpoklada o stroji: sam si najde
pio i esptool, na novem stroji je dotahne, na uz pouzitem jen zkontroluje
verzi. Nic nemaze a nesaha na efuse.

Pouziti:
  firmware/flash.sh                                  # projekt = aktualni adresar, env = default_envs
  firmware/flash.sh -d firmware/testing_firmware     # projekt explicitne
  firmware/flash.sh -d firmware/test_simple -e usb_j5
  firmware/flash.sh -p /dev/ttyACM1                  # kdyz je pripojenych vic desek
  firmware/flash.sh --check                          # jen diagnostika flash, NIC nezapisuje
  firmware/flash.sh --no-build                       # pouzij uz prelozeny build
  firmware/flash.sh --help                           # tenhle text + co ktery test dela
  firmware/flash.sh --list                           # jen seznam prostredi a testu

--help i --list vypisou prostredi, ktera jde dat za -e, a u testu i to, co
overuji a co k tomu musi byt pripojene - tedy to same, co vypise menu na
konzoli desky. Bez -d se to vezme z aktualniho adresare, jinak ze vsech
projektu vedle skriptu.

Prepsat cestu k venv jde promennou ESPTOOL_VENV.

prostredi pro -e v <repo>/firmware/testing_firmware:
 * menu                 Vychozi prostredi: vsechny testy + menu na konzoli.
   t00_chip_info        hlasi se cip, sedi flash/PSRAM varianta
                          potreba: jen USB
   t01_blink_io38       GPIO vystup na pinu J4
                          potreba: LED+330R nebo multimetr
   t02_shift_register   74HC595 budi DIR a EN
                          potreba: sonda na patky BOB
   t03_step_pins        STEP pulsy na IO4..IO7
                          potreba: osciloskop
   t04_endswitches      koncove spinace IO13..IO16
                          potreba: spinace, ruka
   t05_i2c_scan         TCA9548A a kanaly enkoderu
                          potreba: nic / enkodery
   t06_tmc_uart         drivery odpovidaji na UART
                          potreba: osazene BOB-0..3
   t07_wiring_selftest  DIR/EN/STEP overene ctenim IOIN
                          potreba: osazene BOB-0..3
   t08_motor_move       skutecny pohyb jednoho motoru
                          potreba: 24 V + motor   POZOR: hybe motorem
   t09_motor_jog        pusteni motoru a jednoduche pohyby po krocich
                          potreba: 24 V + motor   POZOR: hybe motorem
   * = default_envs, pouzije se bez -e
```

Bez `-d` se seznam bere z aktuálního adresáře; spuštěný z kořene repa vypíše všechny projekty vedle
skriptu (`testing_firmware` i `test_simple`).

### Konzole je po připojení prázdná — tak to má být

Deska **nemá USB-UART převodník**, konzole je nativní USB CDC. Cokoli vypsaného dřív, než hostitel
otevře port, se nenávratně ztratí — čerstvě připojený terminál tak může zůstat prázdný i na
naprosto zdravé desce.

**Stiskni Enter.** Menu opakuje výzvu každé 2 s, dokud nedorazí první znak, takže do dvou sekund
uvidíš buď výzvu, nebo celé menu.

## Ovládání menu

```
test> 0        spustí jeden test podle čísla
test> a        spustí za sebou všechny testy, které nehýbou motorem (T08 a T09 vynechá)
test> ?        znovu vypíše menu
```

V sekvenčním režimu se běh na selhaném testu zastaví a zeptá se, jestli pokračovat. Jednotlivé testy
jsou interaktivní: ptají se na parametry (`perioda [ms]`, `frekvence [Hz]`, … Enter vezme výchozí
hodnotu v hranatých závorkách) a na potvrzení toho, co jsi viděl. Výsledky se hlásí jako
`[ OK ]` / `[FAIL]` / `[WARN]` a na konci testu se sečtou.

Testy, které běží ve smyčce, se ukončí stiskem libovolné klávesy.

## Jednoúčelové binárky

Každý test má i vlastní prostředí, ve kterém není nic než ten jeden test a `main.cpp`:

```bash
pio run -e t00_chip_info -t upload && pio device monitor
```

Hodí se, když deska při některém testu tuhne, propadá napájení nebo se resetuje — v binárce pak není
nic jiného, co by to mohlo způsobit. Jednoúčelový build spustí test hned po bootu a po každém stisku
klávesy ho zopakuje.

## Build bez nahrávání

`menu` je `default_envs`, takže samotné `pio run` přeloží jen jeho. Kontrola, že se všechno pořád
překládá, vyžaduje vyjmenovat prostředí:

```bash
pio run -e menu -e t00_chip_info -e t01_blink_io38 -e t02_shift_register -e t03_step_pins \
        -e t04_endswitches -e t05_i2c_scan -e t06_tmc_uart -e t07_wiring_selftest \
        -e t08_motor_move -e t09_motor_jog
```

Překlad všech prostředí je jediná automatická kontrola v repu — žádná sada testů na hostiteli ani CI
neexistuje.

```bash
pio run -t clean     # smaže výstupy buildu
pio device list      # najde sériový port, když autodetekce selže
```

## Žebřík testů

Každý test předpokládá, že ty před ním prošly. Autoritativní seznam je `src/test_registry.cpp`.

| # | Test | Co ověřuje | Co potřebuje | Odladěno |
|---|---|---|---|---|
| 00 | `chip_info` | čip nabootoval, konzole USB CDC funguje, velikost flash / PSRAM / důvod resetu | jen USB | ✅ |
| 01 | `blink_io38` | GPIO výstup opravdu přepíná úroveň na pinu | externí LED + 330 R nebo multimetr na J4 | ✅ |
| 02 | `shift_register` | 74HC595 budí DIR a EN | multimetr/sonda na patky BOB | ❌ |
| 03 | `step_pins` | STEP pulsy na IO4…IO7 | osciloskop nebo logický analyzátor | ❌ |
| 04 | `endswitches` | IO13…IO16 vidí obě úrovně H i L | koncové spínače, ruka | ❌ |
| 05 | `i2c_scan` | TCA9548A na 0x70, scan enkodérů po kanálech | nic / enkodéry | ❌ |
| 06 | `tmc_uart` | všechny čtyři drivery odpovídají, `VERSION = 0x21`, adresace MS1/MS2 | osazené BOB-0…3 | ❌ |
| 07 | `wiring_selftest` | zapojení DIR/EN/STEP, **ověřené automaticky** | osazené BOB-0…3 | ❌ |
| 08 | `motor_move` | motor se skutečně otáčí | 24 V + motor, volná mechanika | ❌ |
| 09 | `motor_jog` | pustí motor a jede jednoduché pohyby zadané v krocích | 24 V + motor, volná mechanika | ❌ |

**T09 je ten, ve kterém se sedí nejvíc.** T08 odpoví na „otočí se to vůbec“; T09 nechá driver
nastavený a povolený a pohyby se zadávají z konzole, všechno v **krocích** (krok = jeden mikrokrok
při nastaveném rozlišení — při 1/16 je otáčka 200krokového motoru 3200 kroků). Výchozí je motor ve
**slotu 03**, ten zapojený na oživování. Na začátku se ptá na motor, `IRUN`, mikrokrok, počet kroků
na jeden pohyb a kroky za sekundu.

| klávesa | co udělá |
|---|---|
| `f` / `b` | ujede nastavený počet kroků, směr A / B |
| `F` / `B` | jeden krok, směr A / B (dokrokování) |
| `n` | jednorázově zadaný počet kroků a směr |
| `d` / `v` | změní počet kroků na pohyb / rychlost v krocích za sekundu |
| `+` / `-` | rychlost ±25 % |
| `t` | tam a zpět 3× — vůle a ztracené kroky |
| `c` / `C` | plynulá jízda směr A / B, dokud nestiskneš klávesu |
| `s` | rampa: rozjezd na 2× rychlost a dojezd |
| `a` / `u` | změní proud `IRUN` / mikrokrok |
| `m` | přepne motor (starý driver se nejdřív pustí) |
| `0` | vynuluje čítač polohy — „tady je start“ |
| `i` | stav driveru (`DRV_STATUS`, `IOIN`, `IFCNT`) a úroveň koncového spínače |
| `r` | konec a spuštění testu znovu od začátku (nové parametry) |
| `x` | konec — driver se zakáže a test se vyhodnotí |

Čítač polohy jde v krocích od startu (`+` = směr A) a vypisuje se po každém pohybu, takže symetrický
pohyb, který skončí mimo značku, je přímo počet ztracených kroků. Koncový spínač vybraného motoru
jízdu zastaví — ale jen když je v klidu v H; když na vstupu nic není, hlídání se vypne a jedinou
pojistkou je klávesa.

**T07 je ten, který se vyplatí pochopit.** Registr `IOIN` v TMC2209 čte zpátky úrovně vlastních
vstupních pinů DIR / ENN / STEP, takže firmware může nastavit úroveň přes posuvný registr nebo GPIO
a přečíst si ji zpátky po UART. Tím se uzavře smyčka přes celou signálovou cestu — pořadí bitů
v posuvném registru, studené spoje, prohozené STEP piny, špatná adresa driveru — bez sondy a se
stojícími motory. Místo dalšího testu typu „přilož sondu a koukej“ radši rozšiř T07.

## Bezpečnost

- `main.cpp` volá `tk::safe_state()` před každým testem i po něm: STEP piny v L, všechny drivery
  zakázané (`SR = 0xAA`).
- **EN je aktivní v L** (je to `ENN` SilentStepSticku), `0` driver povolí. `~OE` na 74HC595 je
  natvrdo na GND, takže registr budí výstupy hned po zapnutí ESP32 — proto se do něj jako první
  vždycky pošle známý bezpečný bajt.
- T02 postupně krátce povolí každý driver (držný moment, odběr proudu) a předem se zeptá. T03 a T07
  drží všechny drivery zakázané, takže se nic nepohne ani při připojených 24 V.
- **Motorem hýbe jen T08 a T09.** Oba se ptají na motor, počet kroků, rychlost a proud `IRUN`
  a nerozjedou se, dokud nepotvrdíš, že je mechanika volná; T09 navíc zastaví na koncovém spínači
  vybraného motoru a na stisk klávesy. Oba mají v `src/test_registry.cpp` příznak `moves_motor`
  a sekvenční režim (`a`) vynechává všechno, co ho nese.
- Na desce **není žádná softwarově řiditelná LED** (LED1 visí na PG výstupu LT8610 přes NPN). IO38
  je vyvedený jen na jednopinovou lištu J4.

## Pin mapa

`include/board_pins.h` je **jediná správná pin mapa** — odečtená z netlistu a znovu ověřená pad po
padu proti `PCB/esp32stepper.kicad_pcb`.

| Signál | GPIO |
|---|---|
| STEP0…3 | 4, 5, 6, 7 (přímo GPIO → BOB-0…3) |
| 74HC595 SRCLK / SER / RCLK | 8 / 9 / 10 |
| I2C SCL / SDA | 11 / 12 |
| Koncový spínač 0…3 | 13, 14, 15, 16 |
| TMC2209 UART TX / RX | 17 / 18 |
| Debug UART TX / RX (lišta J5) | 2 / 1 |
| Volný pin (lišta J4) | 38 |

Historicky s tímhle nesouhlasily dva další zdroje v repu a pro tuhle desku byly špatné: tabulka ve
`firmware/README.md` a staré MicroPython skripty `firmware/*.py`, psané podle odhadu schématu ještě
než deska existovala. **Ani jedno v repu k 2026-07-30 není** — `firmware/` obsahuje jen
`testing_firmware/` a `test_simple/`. Kdyby se někdy vrátily, čísla pinů z nich neopisuj.

Pořadí bitů DIR/EN v posuvném registru je **proložené, ne blokové**: při zápisu MSB-first
`bit0→QA=dir0, bit1→QB=en0, bit2→QC=dir1, bit3→QD=en1, …`. Používej `SR_BIT_DIR[]` / `SR_BIT_EN[]`,
nikdy ruční posuvy.

## Když to nejde

**Konzole zůstává prázdná.** Očekávané — stiskni Enter (viz výš). `HWCDC::operator bool()` hlásí jen
to, jestli je zapojený USB *kabel*, takže firmware připojení terminálu nedokáže detekovat.

**Deska se restartuje ve smyčce s `E cpu_start: Octal Flash option selected, but EFUSE not
configured!`** Oktální konfigurace (`memory_type = opi_opi`) běží na modulu s **quad** flash,
typicky na ESP32-S3-DevKitC-1 N8R2. Pro ten DevKit přepni na `dout` + `qio_qspi` + `8MB` +
`default_8MB.csv`.

**Deska se restartuje ve smyčce s `assert failed: do_core_init startup.c:328 (flash_ret == ESP_OK)`**
Zrcadlový případ toho výše — a tenhle README dřív tvrdil, že nastat nemůže: **quad** konfigurace na
**oktálním** cílovém modulu. ROM podle efuse zapne OPI (v boot logu se objeví `Octal Flash Mode
Enabled`) a aplikace přeložená pro quad pak neinicializuje flash a spadne. Použij commitnuté oktální
nastavení (`dout`, `opi_opi`, `32MB`, `default_16MB.csv`).

Žádný **quad/oktální společný jmenovatel neexistuje** — ty dvě desky opravdu potřebují jiné
nastavení. Skutečně nalezenou velikost flash vypíše T00.

**T00 hlásí, že nenašel PSRAM.** Je to `warn`, ne `fail` — žádný test v žebříku PSRAM nepotřebuje.
Na cílovém modulu N32R16V je 16 MB oktální PSRAM a `-DBOARD_HAS_PSRAM` je nastavené, takže tam tohle
varování znamená, že něco skutečně nehraje. Na DevKitu N8R2 s quad konfigurací je očekávané.

**T00 hlásí reset kvůli brownoutu.** Napájení nestačí nebo kolísá — sprav to, než pustíš cokoli, co
povoluje driver.

**Upload nenajde port.** `pio device list` ukáže, co v systému je. Download režim vynutíš tím, že
držíš `BOOT1` a zapojíš USB. (Reset/BOOT hardware desky není spolehlivě zdokumentovaný — BOM uvádí
jen `SW1`, který schéma kreslí jako napájecí SPDT přepínač, plus dvoupinovou lištu `J1`. Než se
spolehneš na konkrétní tlačítko, ověř si to ve schématu.)

**`Failed to communicate with the flash chip` / `Manufacturer: 00`, nebo zápis, který se ověří jako
prázdný.** Dvě různé závady na úrovni flash, obě opravitelné a obě popsané krok za krokem včetně
příkazů v [../report.md](../report.md): flash zaseknutá v OPI režimu (chce úplné odpojení napájení —
USB *i* barrel jack) a nastavené block-protect bity ve status registru (chce
`esptool write-flash-status`). Ani jedno neznamená, že je modul mrtvý.

**UART0 (IO43/IO44) není fyzicky zapojený.** Nikdy tam nesměruj logování — na téhle desce nevede
nikam.

## Přidání testu

Tři místa, všechna povinná:

1. `src/tests/tNN_name.cpp` s definicí `void tNN_name()` — bez parametrů, po dokončení se vrátí.
2. Řádek v `src/test_registry.cpp` (jméno, co ověřuje, co musí být připojené).
3. Deklarace v `src/test_registry.h` a sekce `[env:tNN_name]` v `platformio.ini`.

Konvence, které drží sadu použitelnou jako nástroj na oživování:

- Začni `tk::reset_results()` a `tk::banner()`, skonči `tk::summary()`.
- Hlas přes `tk::pass/fail/warn/info` — `pass`/`fail` plní počítadla, podle kterých se sekvenční
  režim rozhoduje, jestli zastavit.
- Na každé cestě z testu nech desku v bezpečném stavu; test, který povolí driver, ho musí sám
  zakázat.
- Smyčka musí volat `tk::key_pressed()`, aby se z ní operátor dostal.
- Blokující čekání musí použít vzor `wait_for_input()` z `main.cpp`, ne holé
  `while (!Serial.available())`.
- Společné hardwarové pomůcky (`ShiftReg`, `TmcBus`, konzole) patří do `lib/testkit/`, ne do testů.
- Komentáře i výpisy na konzoli jsou česky a jen ASCII (bez diakritiky) — některé terminály UTF-8
  přes USB CDC komolí.

## Struktura

```
platformio.ini          prostředí: menu (výchozí) + jedno na každý test
include/board_pins.h    autoritativní pin mapa, bitová mapa posuvného registru
lib/testkit/            konzole, počítadla výsledků, ShiftReg, TmcBus, safe_state
src/main.cpp            interaktivní menu, nebo jeden test přes -DTEST_ENTRY
src/test_registry.*     seznam, který vypisuje menu
src/tests/tNN_*.cpp     jeden test na soubor
```

Hardwarová fakta, která tenhle firmware svazují — varianta modulu, nastavení pamětí a postup
nahrávání — jsou v [../report.md](../report.md).

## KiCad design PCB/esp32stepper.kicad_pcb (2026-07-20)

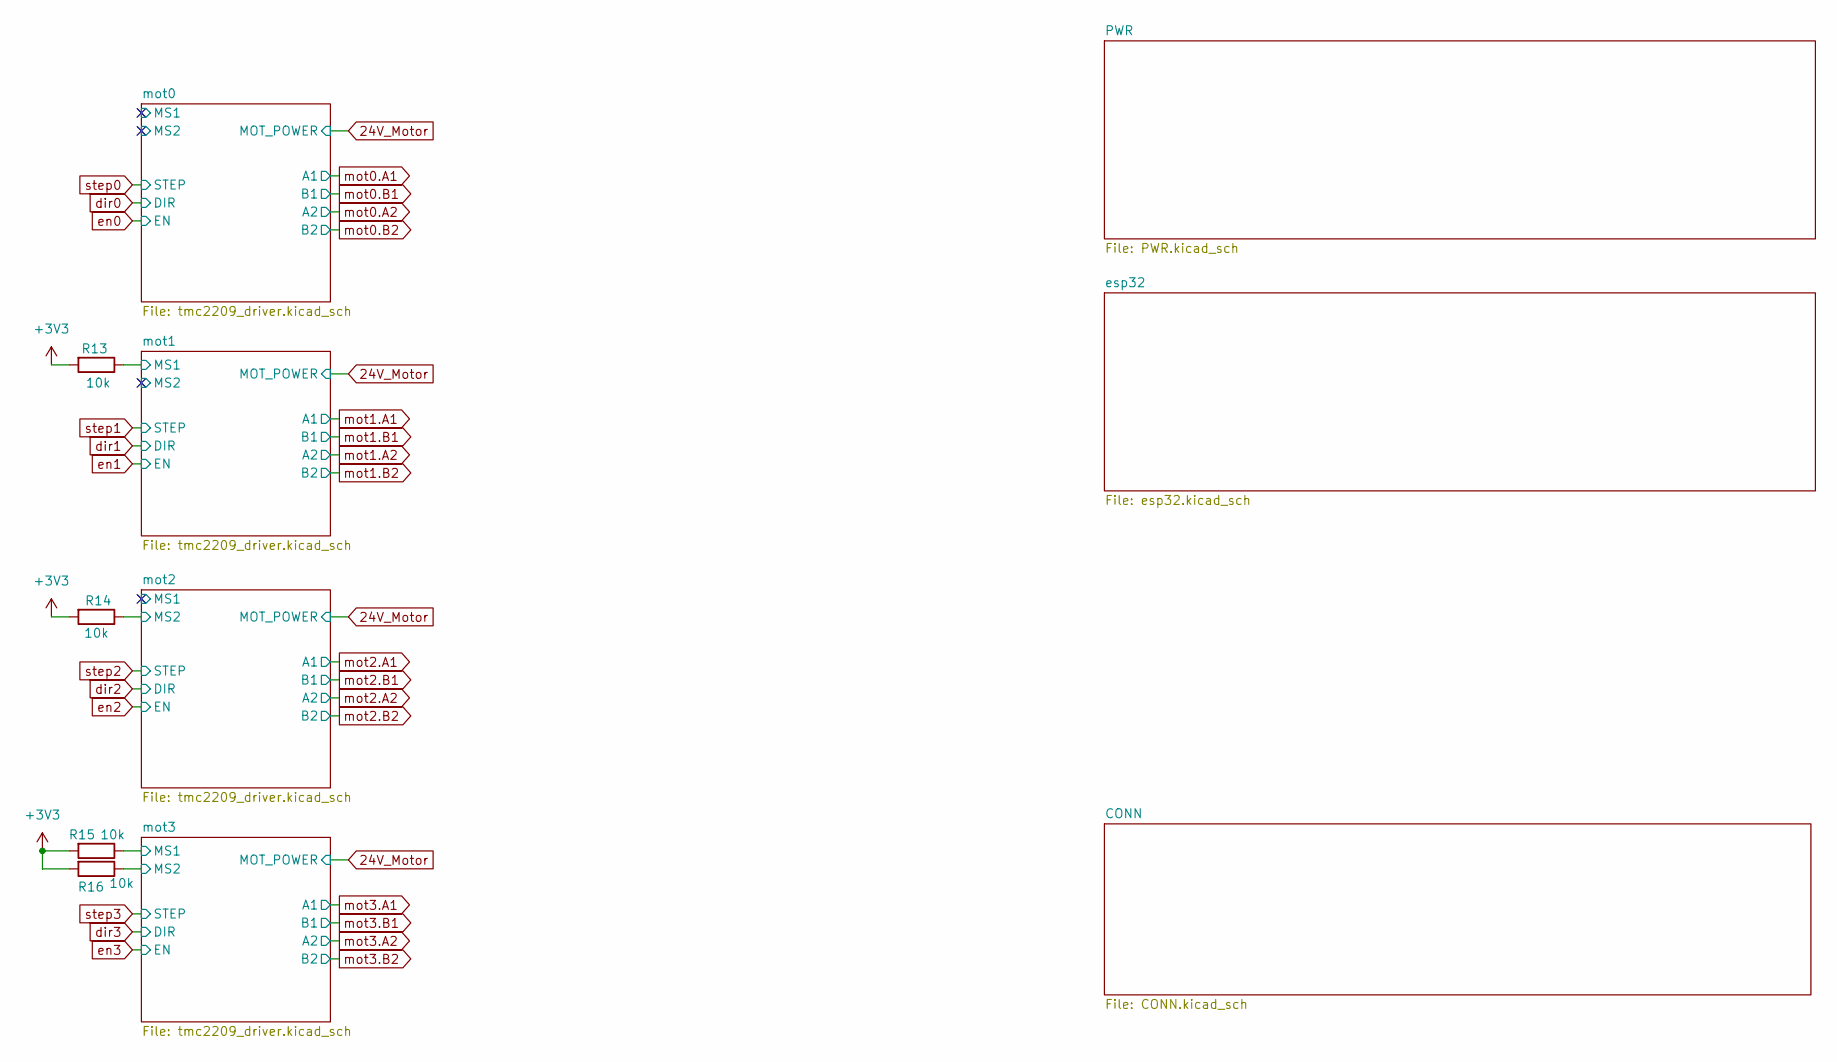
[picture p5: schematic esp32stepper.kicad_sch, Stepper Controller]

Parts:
R13, R14, R15, R16: 10k; R_0603_1608Metric_Pad0.98x0.95mm_HandSolder

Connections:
+3V3: R13.2, R14.2, R15.2, R16.2; also elsewhere on the board
/mot1/MS1: R13.1; also elsewhere on the board
/mot2/MS2: R14.1; also elsewhere on the board
/mot3/MS1: R15.1; also elsewhere on the board
/mot3/MS2: R16.1; also elsewhere on the board

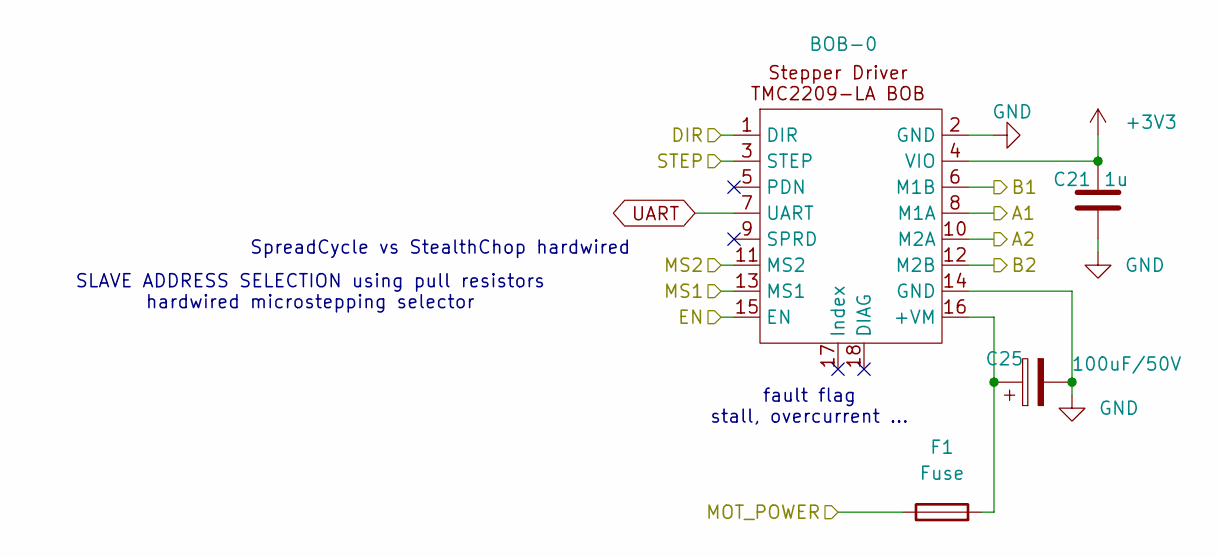
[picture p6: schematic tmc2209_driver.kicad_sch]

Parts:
BOB-0: TMC2209_SilentStepStick
C21: 1u; C_0603_1608Metric_Pad1.08x0.95mm_HandSolder
C25: 100uF/50V; CP_Elec_8x10.5
F1: Fuse; Fuse_1812_4532Metric_Pad1.30x3.40mm_HandSolder

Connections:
24V_Motor: F1.1; also elsewhere on the board
+3V3: BOB-0.4 (VIO), C21.2; also elsewhere on the board
/mot0/MS1: BOB-0.13 (MS1)
/mot0/MS2: BOB-0.11 (MS2)
GND: BOB-0.2 (GND), BOB-0.14 (GND), C21.1, C25.2; also elsewhere on the board
unnamed: BOB-0.16 (+VM), C25.1, F1.2
UART: BOB-0.7 (UART); also elsewhere on the board
dir0: BOB-0.1 (DIR); also elsewhere on the board
en0: BOB-0.15 (EN); also elsewhere on the board
mot0.A1: BOB-0.8 (M1A); also elsewhere on the board
mot0.A2: BOB-0.10 (M2A); also elsewhere on the board
mot0.B1: BOB-0.6 (M1B); also elsewhere on the board
mot0.B2: BOB-0.12 (M2B); also elsewhere on the board
step0: BOB-0.3 (STEP); also elsewhere on the board

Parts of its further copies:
C22, C23, C24: 1u; C_0603_1608Metric_Pad1.08x0.95mm_HandSolder
C26, C27, C28: 100uF/50V; CP_Elec_8x10.5
F3, F4, F5: Fuse; Fuse_1812_4532Metric_Pad1.30x3.40mm_HandSolder

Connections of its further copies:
24V_Motor: F3.1, F4.1, F5.1; also elsewhere on the board
+3V3: C22.2, C23.2, C24.2; also elsewhere on the board
GND: C22.1, C23.1, C24.1, C26.2, C27.2, C28.2; also elsewhere on the board
unnamed 17: C26.1, F3.2; also elsewhere on the board
unnamed 18: C27.1, F4.2; also elsewhere on the board
unnamed 19: C28.1, F5.2; also elsewhere on the board

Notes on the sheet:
fault flag stall, overcurrent ...
SLAVE ADDRESS SELECTION using pull resistors hardwired microstepping selector
SpreadCycle vs StealthChop hardwired

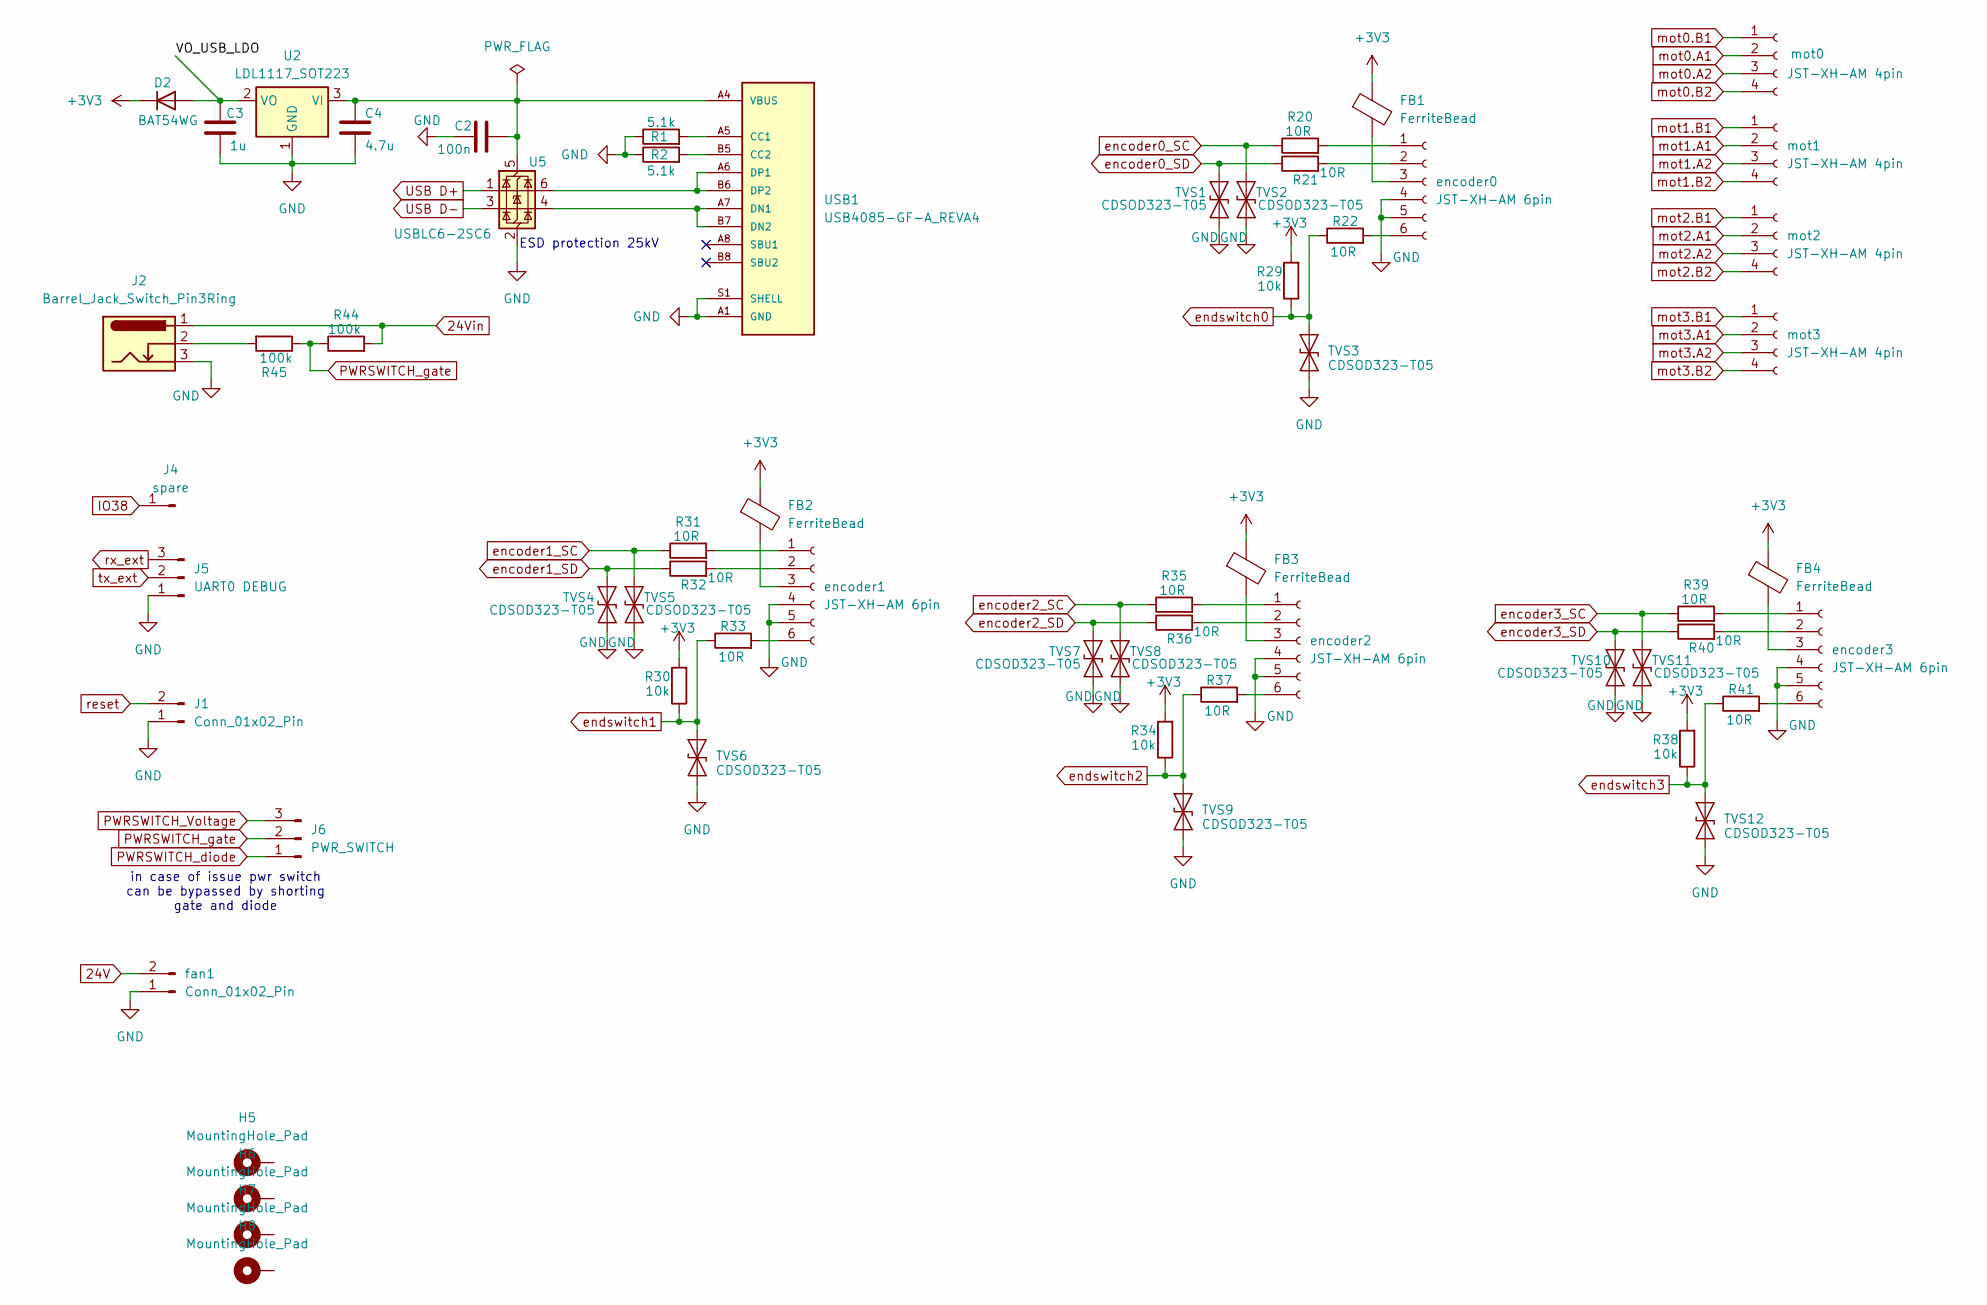
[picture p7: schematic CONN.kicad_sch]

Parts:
C2: 100n; C_0603_1608Metric_Pad1.08x0.95mm_HandSolder
C3: 1u; C_0603_1608Metric_Pad1.08x0.95mm_HandSolder
C4: 4.7u; C_0603_1608Metric_Pad1.08x0.95mm_HandSolder
D2: BAT54WG; SOT-323_SC-70_Handsoldering
FB1, FB2, FB3, FB4: FerriteBead; L_0603_1608Metric_Pad1.05x0.95mm_HandSolder
H5, H6, H7, H8: MountingHole_Pad; MountingHole_3.2mm_M3_DIN965_Pad
J1: Conn_01x02_Pin; PinHeader_1x02_P2.54mm_Vertical
J2: Barrel_Jack_Switch_Pin3Ring; BarrelJack_Wuerth_6941xx301002
J4: spare; PinHeader_1x01_P2.54mm_Vertical
J5: UART0 DEBUG; PinHeader_1x03_P2.54mm_Vertical
J6: PWR_SWITCH; PinHeader_1x03_P2.54mm_Vertical
R1, R2: 5.1k; R_0603_1608Metric_Pad0.98x0.95mm_HandSolder
R20, R21, R22, R31, R32, R33, R35, R36, R37, R39, R40, R41: 10R; R_0603_1608Metric_Pad0.98x0.95mm_HandSolder
R29, R30, R34, R38: 10k; R_0603_1608Metric_Pad0.98x0.95mm_HandSolder
R44, R45: 100k; R_0603_1608Metric_Pad0.98x0.95mm_HandSolder
TVS1, TVS2, TVS3, TVS4, TVS5, TVS6, TVS7, TVS8, TVS9, TVS10, TVS11, TVS12: CDSOD323-T05; D_SOD-323
U2: LDL1117_SOT223; SOT-223-3_TabPin2
U5: USBLC6-2SC6; SOT-23-6
USB1: USB4085-GF-A_REVA4; GCT_USB4085-GF-A_REVA4; PARTREV A4
encoder0, encoder1, encoder2, encoder3: JST-XH-AM 6pin; JST_XH_B6B-XH-AM_1x06_P2.50mm_Vertical
fan1: Conn_01x02_Pin; PinHeader_1x02_P2.54mm_Vertical
mot0, mot1, mot2, mot3: JST-XH-AM 4pin; JST_XH_B4B-XH-AM_1x04_P2.50mm_Vertical

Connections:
24V: fan1.2; also elsewhere on the board
24Vin: J2.1, R44.2; also elsewhere on the board
+3V3: D2.1 (K), FB1.1, FB2.1, FB3.1, FB4.1, R29.2, R30.2, R34.2, R38.2; also elsewhere on the board
/CONN/VO_USB_LDO: C3.1, D2.2 (A), U2.2 (VO)
GND: C2.1, C3.2, C4.2, J1.1, J2.3, J5.1, R1.1, R2.1, TVS1.1 (A1), TVS2.1 (A1), TVS3.1 (A1), TVS4.1 (A1), TVS5.1 (A1), TVS6.1 (A1), TVS7.1 (A1), TVS8.1 (A1), TVS9.1 (A1), TVS10.1 (A1), TVS11.1 (A1), TVS12.1 (A1), U2.1 (GND), U5.2 (GND), USB1.A1 (GND), USB1.A12 (GND), USB1.B1 (GND), USB1.B12 (GND), USB1.S1 (SHELL), USB1.S2 (SHELL), USB1.S3 (SHELL), USB1.S4 (SHELL), encoder0.4, encoder0.5, encoder1.4, encoder1.5, encoder2.4, encoder2.5, encoder3.4, encoder3.5, fan1.1; also elsewhere on the board
IO38: J4.1 (Pin_1_1); also elsewhere on the board
unnamed: J2.2, R45.2
unnamed: R1.2, USB1.A5 (CC1)
unnamed: R2.2, USB1.B5 (CC2)
unnamed: U5.4 (I/O2), USB1.A7 (DN1), USB1.B7 (DN2)
unnamed: U5.6 (I/O1), USB1.A6 (DP1), USB1.B6 (DP2)
unnamed: R20.2, encoder0.1
unnamed: R21.2, encoder0.2
unnamed: FB1.2, encoder0.3
unnamed: R22.2, encoder0.6
unnamed: R31.2, encoder1.1
unnamed: R32.2, encoder1.2
unnamed: FB2.2, encoder1.3
unnamed: R33.2, encoder1.6
unnamed: R35.2, encoder2.1
unnamed: R36.2, encoder2.2
unnamed: FB3.2, encoder2.3
unnamed: R37.2, encoder2.6
unnamed: R39.2, encoder3.1
unnamed: R40.2, encoder3.2
unnamed: FB4.2, encoder3.3
unnamed: R41.2, encoder3.6
PWRSWITCH_Voltage: J6.3; also elsewhere on the board
PWRSWITCH_diode: J6.1; also elsewhere on the board
PWRSWITCH_gate: J6.2, R44.1, R45.1; also elsewhere on the board
USB D+: U5.1 (I/O1); also elsewhere on the board
USB D-: U5.3 (I/O2); also elsewhere on the board
VBUS: C2.2, C4.1, U2.3 (VI), U5.5 (VBUS), USB1.A4 (VBUS), USB1.A9 (VBUS), USB1.B4 (VBUS), USB1.B9 (VBUS)
encoder0_SC: R20.1, TVS2.2 (A2); also elsewhere on the board
encoder0_SD: R21.1, TVS1.2 (A2); also elsewhere on the board
encoder1_SC: R31.1, TVS5.2 (A2); also elsewhere on the board
encoder1_SD: R32.1, TVS4.2 (A2); also elsewhere on the board
encoder2_SC: R35.1, TVS8.2 (A2); also elsewhere on the board
encoder2_SD: R36.1, TVS7.2 (A2); also elsewhere on the board
encoder3_SC: R39.1, TVS11.2 (A2); also elsewhere on the board
encoder3_SD: R40.1, TVS10.2 (A2); also elsewhere on the board
endswitch0: R22.1, R29.1, TVS3.2 (A2); also elsewhere on the board
endswitch1: R30.1, R33.1, TVS6.2 (A2); also elsewhere on the board
endswitch2: R34.1, R37.1, TVS9.2 (A2); also elsewhere on the board
endswitch3: R38.1, R41.1, TVS12.2 (A2); also elsewhere on the board
mot0.A1: mot0.2; also elsewhere on the board
mot0.A2: mot0.3; also elsewhere on the board
mot0.B1: mot0.1; also elsewhere on the board
mot0.B2: mot0.4; also elsewhere on the board
mot1.A1: mot1.2; also elsewhere on the board
mot1.A2: mot1.3; also elsewhere on the board
mot1.B1: mot1.1; also elsewhere on the board
mot1.B2: mot1.4; also elsewhere on the board
mot2.A1: mot2.2; also elsewhere on the board
mot2.A2: mot2.3; also elsewhere on the board
mot2.B1: mot2.1; also elsewhere on the board
mot2.B2: mot2.4; also elsewhere on the board
mot3.A1: mot3.2; also elsewhere on the board
mot3.A2: mot3.3; also elsewhere on the board
mot3.B1: mot3.1; also elsewhere on the board
mot3.B2: mot3.4; also elsewhere on the board
reset: J1.2; also elsewhere on the board
rx_ext: J5.3; also elsewhere on the board
tx_ext: J5.2; also elsewhere on the board

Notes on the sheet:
in case of issue pwr switch can be bypassed by shorting gate and diode
ESD protection 25kV

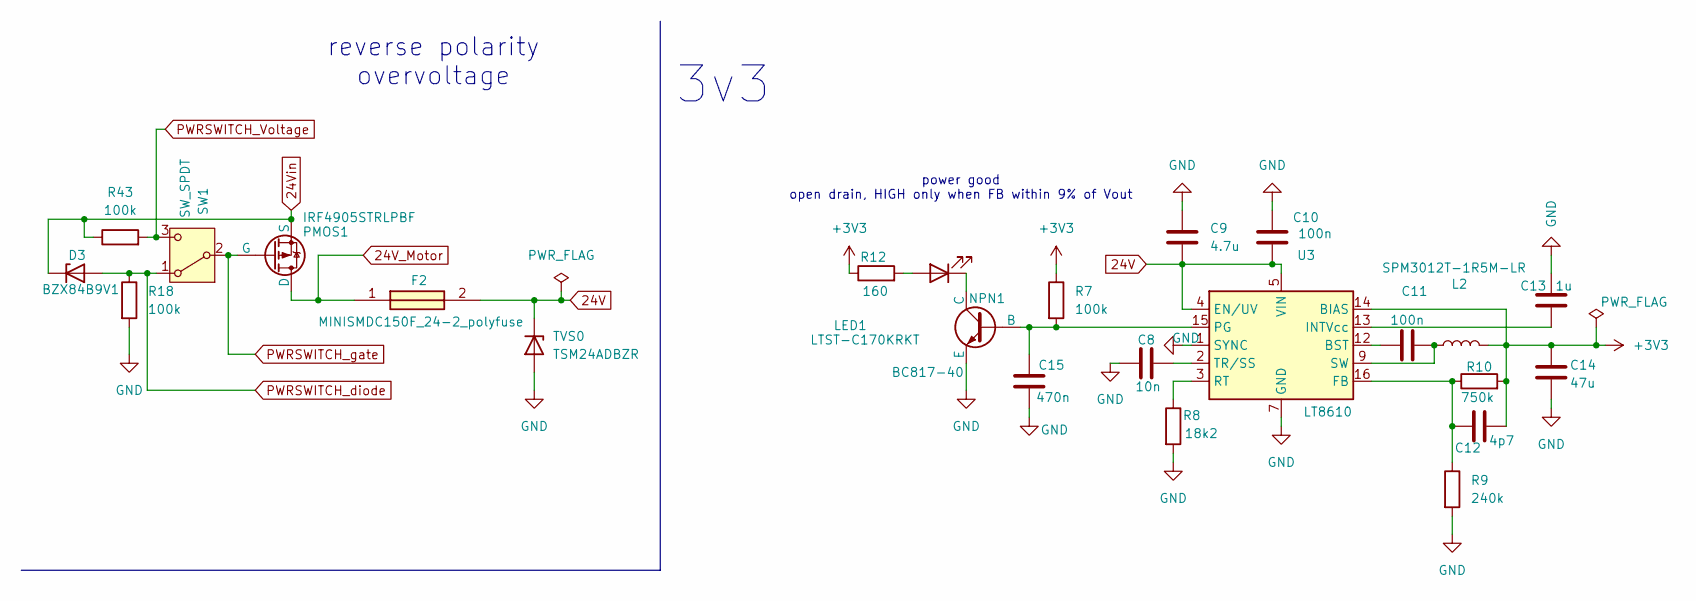
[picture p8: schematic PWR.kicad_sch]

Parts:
C8: 10n; C_0603_1608Metric_Pad1.08x0.95mm_HandSolder
C9: 4.7u; C_0805_2012Metric_Pad1.18x1.45mm_HandSolder
C10, C11: 100n; C_0603_1608Metric_Pad1.08x0.95mm_HandSolder
C12: 4p7; C_0603_1608Metric_Pad1.08x0.95mm_HandSolder
C13: 1u; C_0603_1608Metric_Pad1.08x0.95mm_HandSolder
C14: 47u; C_0603_1608Metric_Pad1.08x0.95mm_HandSolder
C15: 470n; C_0603_1608Metric_Pad1.08x0.95mm_HandSolder
D3: BZX84B9V1; SOT-23
F2: MINISMDC150F_24-2_polyfuse; polyfuse; Mouser Part Number 650-MINISMDC150F/24
L2: SPM3012T-1R5M-LR; SPM3010-3020
LED1: LTST-C170KRKT; LED_0805_2012Metric_Pad1.15x1.40mm_HandSolder
NPN1: BC817-40; TSOT-23_HandSoldering
PMOS1: IRF4905STRLPBF; TO-263-2
R7, R18, R43: 100k; R_0603_1608Metric_Pad0.98x0.95mm_HandSolder
R8: 18k2; R_0603_1608Metric_Pad0.98x0.95mm_HandSolder
R9: 240k; R_0603_1608Metric_Pad0.98x0.95mm_HandSolder
R10: 750k; R_0603_1608Metric_Pad0.98x0.95mm_HandSolder
R12: 160; R_0603_1608Metric_Pad0.98x0.95mm_HandSolder
SW1: SW_SPDT
TVS0: TSM24ADBZR; TSOT-23
U3: LT8610; MSOP-16-1EP_3x4.039mm_P0.5mm_EP1.651x2.845mm_ThermalVias

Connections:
24V: C9.2, C10.2, F2.2, TVS0.1 (K), U3.4 (EN/UV), U3.5 (VIN), U3.6 (VIN); also elsewhere on the board
24V_Motor: F2.1, PMOS1.1 (D); also elsewhere on the board
24Vin: D3.1 (K), PMOS1.3 (S), R43.1; also elsewhere on the board
+3V3: C12.1, C14.1, L2.2, R7.1, R10.2, R12.1, U3.14 (BIAS); also elsewhere on the board
GND: C8.1, C9.1, C10.1, C13.2, C14.2, C15.1, NPN1.3 (E), R8.2, R9.2, R18.2, TVS0.2 (A), U3.1 (SYNC), U3.7 (GND), U3.8 (GND), U3.17 (GND); also elsewhere on the board
unnamed: C11.2, L2.1, U3.9 (SW), U3.10 (SW), U3.11 (SW)
unnamed: LED1.2 (A), R12.2
unnamed: LED1.1 (K), NPN1.1 (C)
unnamed: C15.2, NPN1.2 (B), R7.2, U3.15 (PG)
unnamed: C11.1, U3.12 (BST)
unnamed: C12.2, R9.1, R10.1, U3.16 (FB)
unnamed: C13.1, U3.13 (INTVcc)
unnamed: R8.1, U3.3 (RT)
unnamed: C8.2, U3.2 (TR/SS)
PWRSWITCH_Voltage: R43.2, SW1.3 (C); also elsewhere on the board
PWRSWITCH_diode: D3.2 (A), R18.1, SW1.1 (A); also elsewhere on the board
PWRSWITCH_gate: PMOS1.2 (G), SW1.2 (B); also elsewhere on the board

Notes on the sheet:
power good open drain, HIGH only when FB within 9% of Vout
reverse polarity overvoltage
3v3

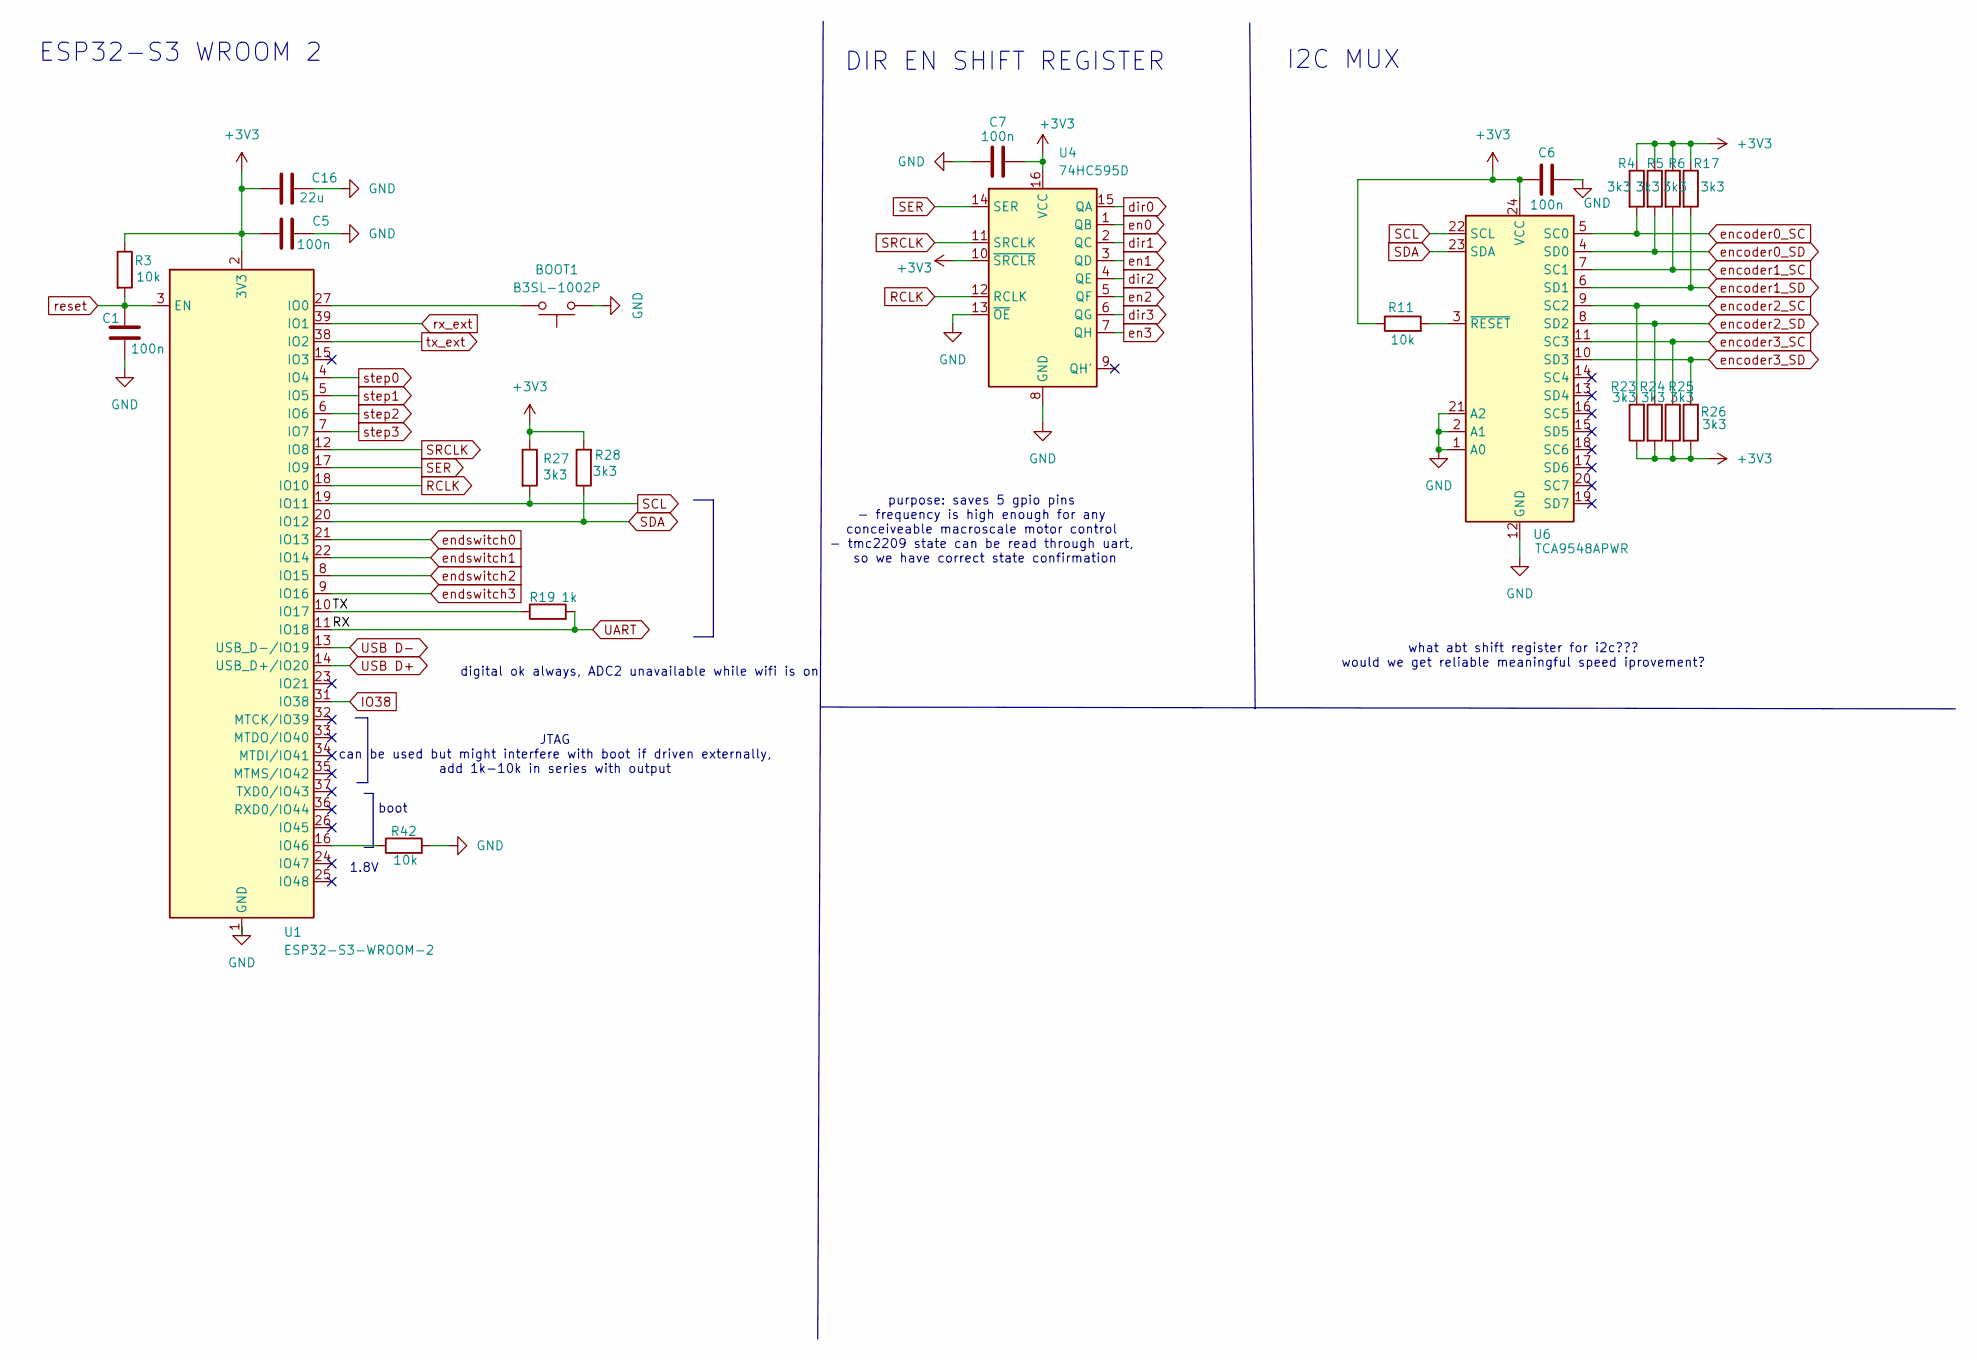
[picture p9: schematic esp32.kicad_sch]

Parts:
BOOT1: B3SL-1002P; SW_SPST_B3SL-1002P
C1, C5, C6, C7: 100n; C_0603_1608Metric_Pad1.08x0.95mm_HandSolder
C16: 22u; C_0603_1608Metric_Pad1.08x0.95mm_HandSolder
R3, R11, R42: 10k; R_0603_1608Metric_Pad0.98x0.95mm_HandSolder
R4, R5, R6, R17, R23, R24, R25, R26, R27, R28: 3k3; R_0603_1608Metric_Pad0.98x0.95mm_HandSolder
R19: 1k; R_0603_1608Metric_Pad0.98x0.95mm_HandSolder
U1: ESP32-S3-WROOM-2
U4: 74HC595D; SOIC-16_3.9x9.9mm_P1.27mm
U6: TCA9548APWR; TSSOP-24_4.4x7.8mm_P0.65mm

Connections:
+3V3: C5.1, C6.1, C7.2, C16.2, R3.1, R4.1, R5.1, R6.1, R11.1, R17.1, R23.1, R24.2, R25.2, R26.2, R27.1, R28.2, U1.2 (3V3), U4.10 (~SRCLR), U4.16 (VCC), U6.24 (VCC); also elsewhere on the board
/esp32/TX: R19.1, U1.10 (IO17)
GND: BOOT1.1, C1.2, C5.2, C6.2, C7.1, C16.1, R42.2, U1.1 (GND), U1.40 (GND), U1.41 (GND), U4.8 (GND), U4.13 (~OE), U6.1 (A0), U6.2 (A1), U6.12 (GND), U6.21 (A2); also elsewhere on the board
IO38: U1.31 (IO38); also elsewhere on the board
unnamed: BOOT1.2, U1.27 (IO0)
unnamed: R42.1, U1.16 (IO46)
unnamed: R11.2, U6.3 (~RESET)
RCLK: U1.18 (IO10), U4.12 (RCLK)
SCL: R27.2, U1.19 (IO11), U6.22 (SCL)
SDA: R28.1, U1.20 (IO12), U6.23 (SDA)
SER: U1.17 (IO9), U4.14 (SER)
SRCLK: U1.12 (IO8), U4.11 (SRCLK)
UART: R19.2, U1.11 (IO18); also elsewhere on the board
USB D+: U1.14 (USB_D+/IO20); also elsewhere on the board
USB D-: U1.13 (USB_D-/IO19); also elsewhere on the board
dir0: U4.15 (QA); also elsewhere on the board
dir1: U4.2 (QC); also elsewhere on the board
dir2: U4.4 (QE); also elsewhere on the board
dir3: U4.6 (QG); also elsewhere on the board
en0: U4.1 (QB); also elsewhere on the board
en1: U4.3 (QD); also elsewhere on the board
en2: U4.5 (QF); also elsewhere on the board
en3: U4.7 (QH); also elsewhere on the board
encoder0_SC: R4.2, U6.5 (SC0); also elsewhere on the board
encoder0_SD: R5.2, U6.4 (SD0); also elsewhere on the board
encoder1_SC: R6.2, U6.7 (SC1); also elsewhere on the board
encoder1_SD: R17.2, U6.6 (SD1); also elsewhere on the board
encoder2_SC: R23.2, U6.9 (SC2); also elsewhere on the board
encoder2_SD: R24.1, U6.8 (SD2); also elsewhere on the board
encoder3_SC: R25.1, U6.11 (SC3); also elsewhere on the board
encoder3_SD: R26.1, U6.10 (SD3); also elsewhere on the board
endswitch0: U1.21 (IO13); also elsewhere on the board
endswitch1: U1.22 (IO14); also elsewhere on the board
endswitch2: U1.8 (IO15); also elsewhere on the board
endswitch3: U1.9 (IO16); also elsewhere on the board
reset: C1.1, R3.2, U1.3 (EN); also elsewhere on the board
rx_ext: U1.39 (IO1); also elsewhere on the board
step0: U1.4 (IO4); also elsewhere on the board
step1: U1.5 (IO5); also elsewhere on the board
step2: U1.6 (IO6); also elsewhere on the board
step3: U1.7 (IO7); also elsewhere on the board
tx_ext: U1.38 (IO2); also elsewhere on the board

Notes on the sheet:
purpose: saves 5 gpio pins - frequency is high enough for any conceiveable macroscale motor control - tmc2209 state can be read through uart, so we have correct state confirmation
JTAG can be used but might interfere with boot if driven externally, add 1k-10k in series with output
digital ok always, ADC2 unavailable while wifi is on
boot
I2C MUX
DIR EN SHIFT REGISTER
what abt shift register for i2c??? would we get reliable meaningful speed iprovement?
1.8V
ESP32-S3 WROOM 2

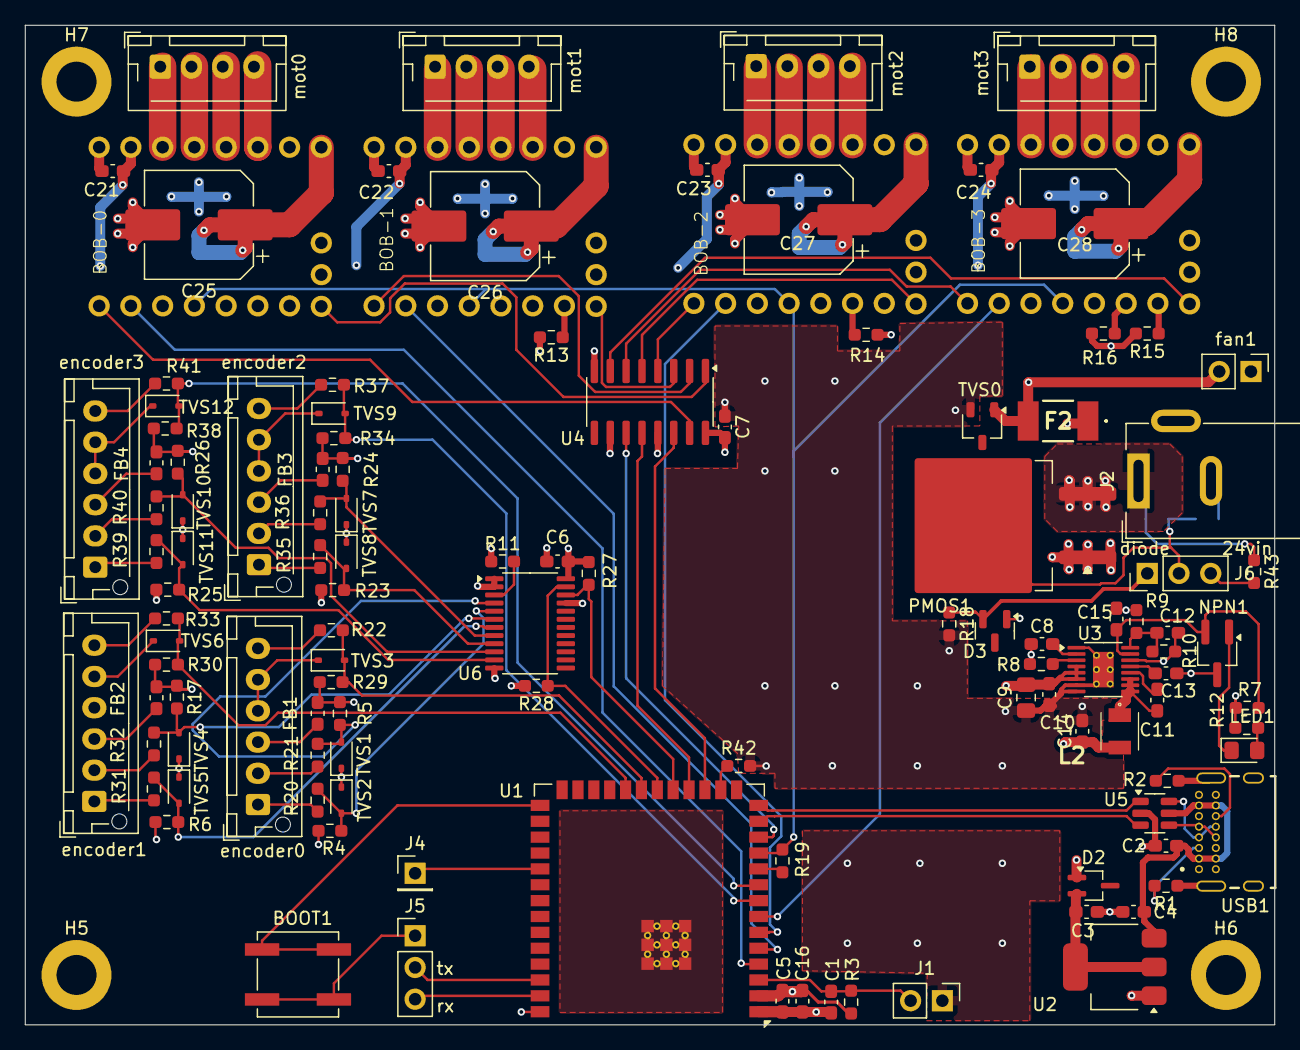
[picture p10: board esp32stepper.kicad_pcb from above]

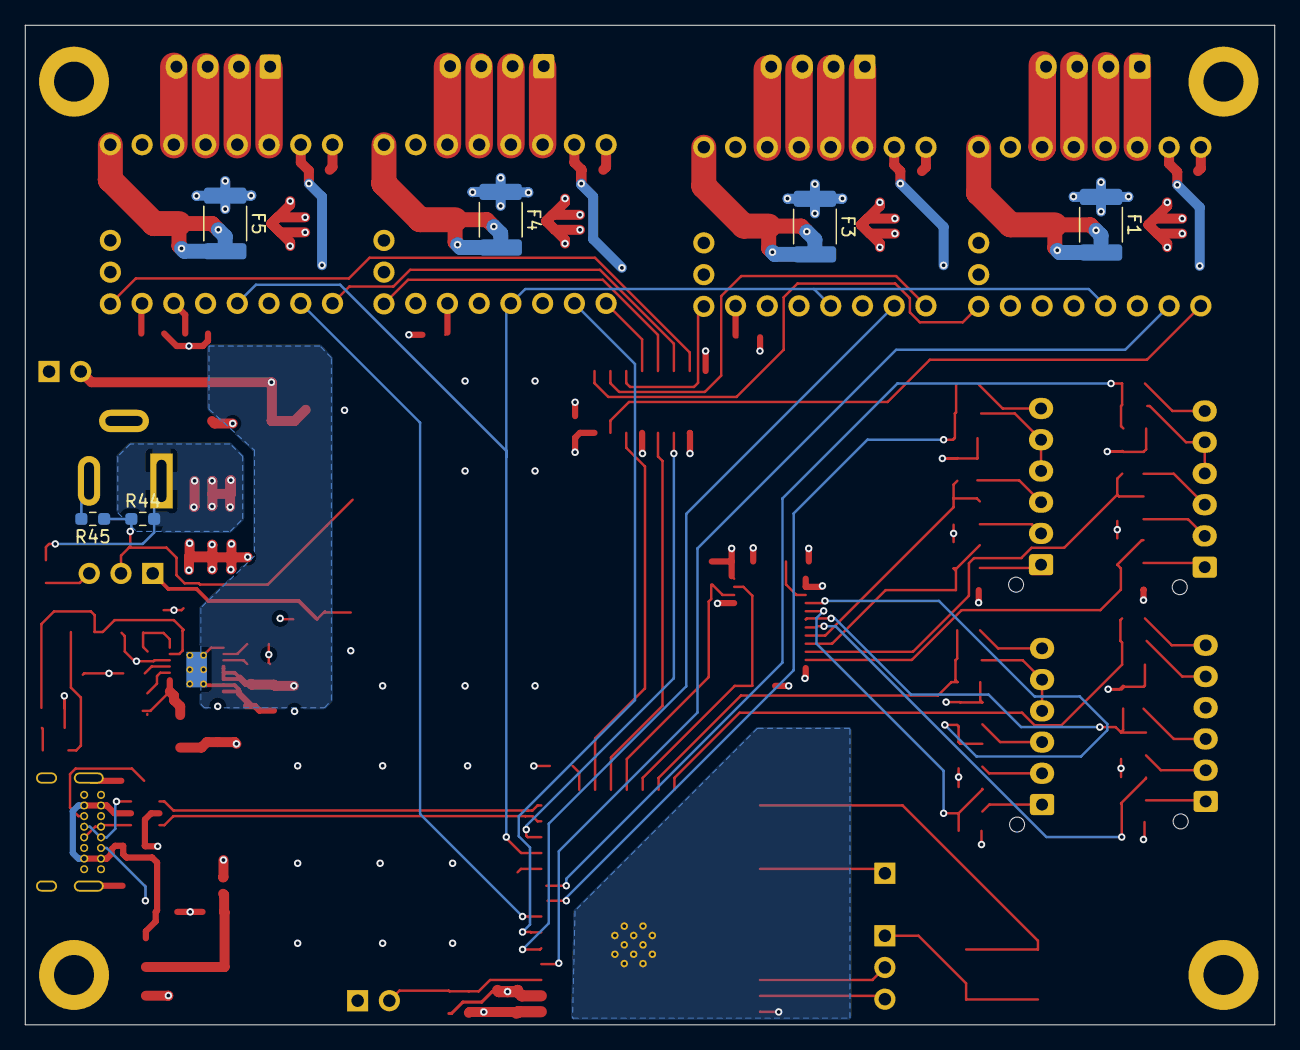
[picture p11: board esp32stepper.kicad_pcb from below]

Board: 4 copper layers, 100.0 x 80.0 mm, 127 parts (6 on the bottom side), 104 nets.

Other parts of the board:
BOB-1, BOB-2, BOB-3: TMC2209_SilentStepStick

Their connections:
+3V3: BOB-1.4 (VIO), BOB-2.4 (VIO), BOB-3.4 (VIO); also elsewhere on the board
/mot1/MS1: BOB-1.13 (MS1); also elsewhere on the board
/mot2/MS2: BOB-2.11 (MS2); also elsewhere on the board
/mot3/MS1: BOB-3.13 (MS1); also elsewhere on the board
/mot3/MS2: BOB-3.11 (MS2); also elsewhere on the board
GND: BOB-1.2 (GND), BOB-1.14 (GND), BOB-2.2 (GND), BOB-2.14 (GND), BOB-3.2 (GND), BOB-3.14 (GND); also elsewhere on the board
unnamed 17: BOB-1.16 (+VM); also elsewhere on the board
unnamed 18: BOB-2.16 (+VM); also elsewhere on the board
unnamed 19: BOB-3.16 (+VM); also elsewhere on the board
UART: BOB-1.7 (UART), BOB-2.7 (UART), BOB-3.7 (UART); also elsewhere on the board
dir1: BOB-1.1 (DIR); also elsewhere on the board
dir2: BOB-2.1 (DIR); also elsewhere on the board
dir3: BOB-3.1 (DIR); also elsewhere on the board
en1: BOB-1.15 (EN); also elsewhere on the board
en2: BOB-2.15 (EN); also elsewhere on the board
en3: BOB-3.15 (EN); also elsewhere on the board
mot1.A1: BOB-1.8 (M1A); also elsewhere on the board
mot1.A2: BOB-1.10 (M2A); also elsewhere on the board
mot1.B1: BOB-1.6 (M1B); also elsewhere on the board
mot1.B2: BOB-1.12 (M2B); also elsewhere on the board
mot2.A1: BOB-2.8 (M1A); also elsewhere on the board
mot2.A2: BOB-2.10 (M2A); also elsewhere on the board
mot2.B1: BOB-2.6 (M1B); also elsewhere on the board
mot2.B2: BOB-2.12 (M2B); also elsewhere on the board
mot3.A1: BOB-3.8 (M1A); also elsewhere on the board
mot3.A2: BOB-3.10 (M2A); also elsewhere on the board
mot3.B1: BOB-3.6 (M1B); also elsewhere on the board
mot3.B2: BOB-3.12 (M2B); also elsewhere on the board
step1: BOB-1.3 (STEP); also elsewhere on the board
step2: BOB-2.3 (STEP); also elsewhere on the board
step3: BOB-3.3 (STEP); also elsewhere on the board

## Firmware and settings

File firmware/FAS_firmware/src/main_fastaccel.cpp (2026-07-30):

// FAS firmware - prototyp main.cpp s FastAccelStepperem (env:fas_accel).
// Verze: 0.0.1
//
// Chovani je zamerne shodne s main.cpp: totez nastaveni z fas_config.h, tatez
// hlaseni na konzoli, stejny cyklus tam-pauza-zpet-pauza. Jedina zmena je
// #include a typ `mot` - misto rucniho generatoru kroku (stepper.h) jede
// StepperFA (stepper_fastaccel.h), ktery kroky generuje pres knihovnu
// FastAccelStepper. Cil je mit oba pristupy vedle sebe k porovnani, ne dva
// ruzne firmwary - kdyz se tu neco upravi, sjednot to i v main.cpp a naopak.
//
// POZOR: motor se rozjede sam, 3 s po nabootovani. Mechanika musi mit volnou
// drahu. Jizdu prerusi jakakoli klavesa z konzole nebo koncovy spinac.

#include <Arduino.h>

#include <stdarg.h>

#include "board_pins.h"
#include "fas_config.h"
#include "stepper_fastaccel.h"
#include "tmc2209.h"

namespace {

fas::Tmc2209 drv;
fas::StepperFA mot;

// Kolik kroku je jeden pohyb. Kroky, ne otacky, jsou to, cim se hybe driver.
constexpr int32_t MOVE_STEPS =
    static_cast<int32_t>(fas::REVS_PER_MOVE * fas::STEPS_PER_REV + 0.5f);

uint32_t cycles = 0;
bool halted = false;
const char* halt_reason = "";

void logln(const char* fmt, ...) {
  char buf[220];
  va_list ap;
  va_start(ap, fmt);
  vsnprintf(buf, sizeof(buf), fmt, ap);
  va_end(ap);
  Serial.print(buf);
  Serial.print("\r\n");
}

// USB CDC ma nemilou vlastnost: co se vypise driv, nez si host otevre port,
// se nenavratne ztrati. Proto to kratke cekani - a proto se dulezite udaje
// (nastaveni driveru) vypisuji jeste jednou u prvniho cyklu.
void console_begin() {
  Serial.begin(115200);
  const uint32_t t0 = millis();
  while (!Serial && (millis() - t0) < 3000) {
    delay(10);
  }
  delay(200);
  Serial.println();
  Serial.println();
}

void banner() {
  logln("===================================================");
  logln("  FAS firmware - pohyb tam a zpet (FastAccelStepper prototyp)");
  logln("===================================================");
}

void halt(const char* why) {
  mot.enable(false);
  halted = true;
  halt_reason = why;
  logln("");
  logln("HALT: %s", why);
  logln("      driver zakazan, motor se dal nehybe. Oprav a resetuj desku.");
}

void print_move_plan() {
  const float move_s =
      static_cast<float>(MOVE_STEPS) / mot.speed_steps_s() +
      mot.speed_steps_s() / mot.accel_steps_s2();  // hruby odhad s rampou
  logln("pohyb    : %.2f otacky = %ld kroku, %.1f rpm (%.0f kroku/s),"
        " zrychleni %.1f ot/s^2",
        fas::REVS_PER_MOVE, static_cast<long>(MOVE_STEPS), fas::SPEED_RPM,
        mot.speed_steps_s(), fas::ACCEL_RPS2);
  logln("           rampa %lu kroku, jeden pohyb ~%.1f s, pauza %lu ms",
        static_cast<unsigned long>(mot.ramp_steps()), move_s,
        static_cast<unsigned long>(fas::PAUSE_MS));
  if (mot.ramp_steps() * 2 > static_cast<uint32_t>(MOVE_STEPS)) {
    logln("           pozn.: rampy se protnou, na cestovni rychlost se"
          " nedojede");
  }
}

void print_driver_config() {
  logln("driver   : BOB-%u, adresa %u na UART sbernici (IO%u/IO%u),"
        " STEP=IO%u, koncovak=IO%u",
        fas::MOTOR, drv.node(), PIN_TMC_TX, PIN_TMC_RX, PIN_STEP[fas::MOTOR],
        PIN_ENDSWITCH[fas::MOTOR]);
  logln("mikrokrok: 1/%u z registru (MS1/MS2 tady drzi adresu),"
        " %lu kroku na otacku",
        drv.microsteps(), static_cast<unsigned long>(fas::STEPS_PER_REV));
  logln("proud    : zadano %u mA -> nastaveno %u mA RMS (IRUN=%u, vsense=%u,"
        " Rsense %.2f ohm)",
        fas::RUN_CURRENT_MA, drv.run_ma_actual(), drv.irun(),
        drv.vsense() ? 1 : 0, fas::R_SENSE_OHM);
  logln("           klidovy %u %% = %u mA (IHOLD=%u, IHOLDDELAY=%u,"
        " TPOWERDOWN=%u)",
        fas::HOLD_CURRENT_PCT, drv.hold_ma_actual(), drv.ihold(),
        fas::IHOLDDELAY, fas::TPOWERDOWN);
}

// Vypise, co se da vycist z DRV_STATUS. Vraci false, kdyz je to chyba, na
// kterou se ma zastavit.
bool report_status(const fas::DrvStatus& st, bool verbose) {
  if (verbose) {
    logln("DRV_STATUS=0x%08lX  cs_actual=%u  stst=%u",
          static_cast<unsigned long>(st.raw), st.cs_actual, st.stst ? 1 : 0);
  }
  if (st.otpw) logln("[WARN] otpw - predzvest prehrati, snizit proud");
  if (st.ot) logln("[FAIL] ot - driver se vypnul prehratim");
  if (st.s2ga) logln("[FAIL] s2ga - zkrat faze A na GND");
  if (st.s2gb) logln("[FAIL] s2gb - zkrat faze B na GND");
  if (st.s2vsa) logln("[FAIL] s2vsa - zkrat faze A na VS");
  if (st.s2vsb) logln("[FAIL] s2vsb - zkrat faze B na VS");
  return !st.fault();
}

// Cela cesta od "deska nabootovala" k "driver je povoleny a smi se hybat".
// false = firmware se nesmi rozjet.
bool bring_up() {
  // mot.begin() uz probehl v setup() jeste pred konzoli - viz komentar tam.
  if (!mot.set_profile(fas::STEPS_PER_REV, fas::SPEED_RPM, fas::ACCEL_RPS2,
                       fas::START_RPM)) {
    logln("[WARN] %.1f rpm je nad stropem generatoru (%.0f kroku/s) -"
          " rychlost snizena",
          fas::SPEED_RPM, fas::MAX_STEP_RATE);
  }

  drv.begin(TMC_ADDR[fas::MOTOR]);

  // Prvni cteni po zapnuti obcas propadne (driver jeste nabiha), proto par
  // pokusu, nez se to prohlasi za mrtve.
  uint32_t ioin = 0;
  bool alive = false;
  for (uint8_t attempt = 0; attempt < 5 && !alive; ++attempt) {
    alive = drv.ping(&ioin);
    if (!alive) delay(50);
  }
  if (!alive) {
    logln("driver BOB-%u (adresa %u) neodpovida, nebo hlasi jinou adresu"
          " (IOIN=0x%08lX)",
          fas::MOTOR, drv.node(), static_cast<unsigned long>(ioin));
    logln("zkontroluj osazeni driveru, R19 na UART sbernici a pull-upy"
          " R13..R16; podrobnou diagnostiku dela test T06");
    halt("driver nekomunikuje po UART");
    return false;
  }
  logln("driver odpovida: VERSION=0x%02lX, ENN=%lu, PDN_UART=%lu",
        static_cast<unsigned long>((ioin >> 24) & 0xFF),
        static_cast<unsigned long>((ioin >> fas::IOIN_ENN) & 1),
        static_cast<unsigned long>((ioin >> fas::IOIN_PDN_UART) & 1));

  uint32_t gstat = 0;
  if (drv.read_and_clear_gstat(&gstat)) {
    if (gstat & 0x01) logln("GSTAT: reset - driver nabehl (ceka se po zapnuti)");
    if (gstat & 0x02) logln("[WARN] GSTAT: drv_err - driver se driv vypnul chybou");
    if (gstat & 0x04) {
      logln("[WARN] GSTAT: uv_cp - podpeti nabojove pumpy, nejspis chybi 24 V");
    }
  }

  if (!drv.configure(fas::RUN_CURRENT_MA, fas::HOLD_CURRENT_PCT,
                     fas::MICROSTEPS)) {
    logln("zapisy do driveru neprosly (IFCNT nebo CHOPCONF nesouhlasi) -"
          " sbernice UART je nespolehliva, %lu chyb cteni",
          static_cast<unsigned long>(drv.bus_errors()));
    halt("driver neprijal konfiguraci");
    return false;
  }
  print_driver_config();
  print_move_plan();

  fas::DrvStatus st;
  if (drv.read_status(&st) && !report_status(st, true)) {
    halt("driver hlasi chybu jeste pred rozjezdem");
    return false;
  }

  // Koncovy spinac ma v klidu pull-up, tedy H. Kdyz je uz pri startu v L, bud je
  // mechanika na koncaku, nebo spinac neni zapojeny - hlidat ho pak nejde,
  // protoze by se firmware nikdy nerozjel.
  if (fas::ENDSTOP_GUARD) {
    if (mot.endstop_closed()) {
      logln("[WARN] koncovy spinac IO%u je uz v klidu sepnuty (nebo neni"
            " zapojeny) - hlidani vypnuto, jizdu zastavi jen klavesa",
            PIN_ENDSWITCH[fas::MOTOR]);
      mot.set_endstop_guard(false);
    } else {
      mot.set_endstop_guard(true);
      logln("koncovy spinac IO%u je rozepnuty - pri sepnuti pohyb zastavi",
            PIN_ENDSWITCH[fas::MOTOR]);
    }
  } else {
    logln("[WARN] hlidani koncoveho spinace je vypnute v konfiguraci");
  }

  logln("");
  if (fas::START_DELAY_MS > 0) {
    logln("motor se rozjede za %lu s - mechanika musi mit volnou drahu",
          static_cast<unsigned long>((fas::START_DELAY_MS + 999) / 1000));
    for (uint32_t left = fas::START_DELAY_MS; left > 0;) {
      const uint32_t chunk = (left > 1000) ? 1000 : left;
      delay(chunk);
      left -= chunk;
    }
  }
  if (fas::WAIT_FOR_ENTER) {
    logln(">>> stisknij klavesu, tim se motor rozjede");
    while (!Serial.available()) {
      delay(10);
    }
  }
  while (Serial.available()) Serial.read();  // at hned nespadne stop klavesa

  mot.enable(true);
  mot.zero();
  logln("driver povolen, hridel drzi klidovy proud. Tady je nula polohy -"
        " udelej si znacku na hrideli.");
  logln("Jakakoli klavesa jizdu prerusi, dalsi ji pusti dal.");
  return true;
}

// Registry driveru jsou volatilni - zijou jen dokud ma driver VM. Po vypadku
// 24 V nabehne s vychozimi hodnotami: mikrokrok zase z pinu MS1/MS2 (viz
// firmware/TMC2209_MS1_MS2.md, HW-00201), IRUN na vychozich 23 a I_scale_analog
// zpatky na jednicce, tedy proud podle VREF. Nic z toho neni videt na
// DRV_STATUS - jediny zpusob, jak to firmware pozna, je GSTAT bit 0 (reset).
//
// Vraci false, kdyz se ma cyklus prerusit: po rekonfiguraci nebo pri haltu.
bool driver_survived() {
  uint32_t gstat = 0;
  if (!drv.read_and_clear_gstat(&gstat)) return true;  // vypadek sbernice resi volajici

  if (gstat & 0x04) {
    logln("[WARN] GSTAT: uv_cp - podpeti nabojove pumpy, nejspis vypadlo 24 V");
  }
  if ((gstat & 0x02) && !(gstat & 0x01)) {
    logln("[WARN] GSTAT: drv_err - driver se vypnul chybou");
  }
  if (!(gstat & 0x01)) return true;  // zadny reset, konfigurace plati dal

  logln("[WARN] driver se restartoval (GSTAT.reset) - konfigurace je pryc:");
  logln("       mikrokrok by se vratil na pinovy z MS1/MS2 a proud na vychozi.");

  // Rekonfigurovat se musi se zakazanym driverem: dokud registry drzi vychozi
  // hodnoty, tece do motoru proud, ktery jsme nezadali.
  mot.enable(false);
  if (!drv.configure(fas::RUN_CURRENT_MA, fas::HOLD_CURRENT_PCT,
                     fas::MICROSTEPS)) {
    logln("znovunastaveni driveru neproslo (%lu chyb cteni na sbernici)",
          static_cast<unsigned long>(drv.bus_errors()));
    halt("driver se restartoval a nelze ho znovu nastavit");
    return false;
  }
  print_driver_config();

  // Behem vypadku napajeni se hridel mohla protocit a citac kroku uz nerika
  // nic o tom, kde doopravdy je. Nulou se prizna, ze je to novy start.
  mot.zero();
  mot.enable(true);
  logln("driver znovu nastaven, citac polohy vynulovan - znacka na hrideli"
        " uz nesedi, jede se dal od tady");
  return false;
}

// Jeden pohyb. false = cyklus se ma prerusit (halt nebo pauza od operatora).
bool do_move(int32_t steps) {
  const char* dir = (steps >= 0) ? "A" : "B";
  const fas::MoveEnd end = mot.move(steps);

  logln("  smer %s: %lu kroku za %lu ms (~%lu kroku/s), poloha %+ld",
        dir, static_cast<unsigned long>(mot.last_steps()),
        static_cast<unsigned long>(mot.last_ms()),
        static_cast<unsigned long>(mot.last_rate()),
        static_cast<long>(mot.position()));

  // Jestli driver po celou dobu pohybu drzel nasi konfiguraci. Kontroluje se
  // po kazdem pohybu, ne raz za cyklus - jinak by druhy pohyb v cyklu jel
  // s vychozim proudem a mikrokrokem, nez by si toho firmware vsiml.
  if (!driver_survived()) return false;

  fas::DrvStatus st;
  if (!drv.read_status(&st)) {
    logln("[WARN] DRV_STATUS nelze precist (%lu chyb cteni celkem)",
          static_cast<unsigned long>(drv.bus_errors()));
  } else {
    if (!report_status(st, false)) {
      halt("driver hlasi chybu po jizde");
      return false;
    }
    if (st.cs_actual == 0) {
      logln("[WARN] cs_actual=0 - do motoru netece proud, zkontroluj 24 V");
    }
  }

  switch (end) {
    case fas::MoveEnd::done:
      return true;
    case fas::MoveEnd::endstop:
      logln("koncovy spinac sepnul - pohyb zastaven");
      halt("koncovy spinac");
      return false;
    case fas::MoveEnd::keypress:
      mot.enable(false);
      logln("preruseno klavesou. Driver zakazan, hridel je volna.");
      logln(">>> dalsi klavesa pokracuje (poloha zustava %+ld)",
            static_cast<long>(mot.position()));
      while (!Serial.available()) {
        delay(10);
      }
      while (Serial.available()) Serial.read();
      mot.enable(true);
      logln("pokracuje se");
      return false;
  }
  return false;
}

}  // namespace

void setup() {
  // Bezpecny stav driveru je prvni vec, jeste pred konzoli: 74HC595 ma ~OE na
  // GND, takze jeho vystupy plati od privedeni napajeni a do prvniho zapisu
  // jsou nahodne. Cekani na USB CDC trva az 3 s - tak dlouho nesmi byt
  // nahodne povoleny driver s nahodnym DIR.
  mot.begin(fas::MOTOR);

  console_begin();
  banner();
  if (!bring_up()) return;  // halt uz je nastaveny, loop() jen hlasi
}

void loop() {
  if (halted) {
    logln("HALT: %s - resetuj desku", halt_reason);
    delay(5000);
    return;
  }

  ++cycles;
  logln("");
  logln("cyklus %lu: %.2f otacky tam a zpet", static_cast<unsigned long>(cycles),
        fas::REVS_PER_MOVE);

  // Porovnava se proti zacatku cyklu, ne proti absolutni nule: kdyz nekdo
  // jeden pohyb prerusil klavesou, dalsi cykly zacinaji jinde a hlasit to
  // porad dokola by nemelo smysl.
  const int32_t start = mot.position();

  if (!do_move(MOVE_STEPS)) return;
  delay(fas::PAUSE_MS);
  if (!do_move(-MOVE_STEPS)) return;
  delay(fas::PAUSE_MS);

  // Kontrola invariantu: symetricky dojety cyklus musi skoncit tam, kde zacal.
  // Citac kroku se tak sam kontroluje - ale POZOR, hlida jen sebe. Kdyz je
  // citac na svem miste a znacka na hrideli ne, motor ztraci kroky (maly
  // proud, vysoka rychlost, tuha mechanika) a bez enkoderu to firmware nepozna.
  if (mot.position() != start) {
    logln("  [WARN] poloha po cyklu je %+ld misto %+ld",
          static_cast<long>(mot.position()), static_cast<long>(start));
  }
}

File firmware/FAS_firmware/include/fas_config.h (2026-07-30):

// Vsechna nastaveni FAS firmware na jednom miste.
//
// Nic z toho se za behu nemeni - firmware nema konzolove prikazy, jen vypisuje.
// Zmena = uprava tohohle souboru, prelozit a nahrat. Ladit hodnoty za behu
// (proud, rychlost, mikrokrok, jiny motor) se da v ../testing_firmware, test T09.

#pragma once

#include <stdint.h>

namespace fas {

// --- ktery motor -----------------------------------------------------------
// Slot driveru, 0..3 (BOB-0..3 na desce). Adresa driveru na UART sbernici je
// TMC_ADDR[MOTOR], koncovy spinac PIN_ENDSWITCH[MOTOR], STEP pin PIN_STEP[MOTOR].
// Vychozi 3 (ctvrty slot) - tam je zapojeny motor, na kterem se oziva deska.
static constexpr uint8_t MOTOR = 3;

// --- motor a mikrokrok -----------------------------------------------------
// Bezny krokovy motor 1.8 stupne = 200 plnych kroku na otacku.
static constexpr uint16_t FULL_STEPS_PER_REV = 200;
// Mikrokrok se nastavuje po UART (CHOPCONF.MRES), NE pinama MS1/MS2 - ty na
// teto desce delaji adresu driveru. Povolene hodnoty: 1, 2, 4, ... 256.
static constexpr uint16_t MICROSTEPS = 16;
// Kolik STEP impulsu je jedna otacka hridele.
static constexpr uint32_t STEPS_PER_REV =
    static_cast<uint32_t>(FULL_STEPS_PER_REV) * MICROSTEPS;

// --- proud (posila se po UART do IHOLD_IRUN) -------------------------------
// Efektivni (RMS) proud na fazi pri jizde, v mA. Firmware si z toho spocita
// CS hodnotu 0..31 a vypise, na jakou se to doopravdy zaokrouhlilo.
// 600 mA je konzervativni start pro NEMA17 - motor jde, ale nehreje.
static constexpr uint16_t RUN_CURRENT_MA = 600;
// Klidovy proud jako procento z RUN. 0 = hridel se pusti, 100 = plna drzici
// sila (a plne hrati). 50 % je bezny kompromis.
static constexpr uint8_t HOLD_CURRENT_PCT = 50;
// Jak rychle se po zastaveni sjede z IRUN na IHOLD (0..15, vetsi = pomaleji).
static constexpr uint8_t IHOLDDELAY = 6;
// Za jak dlouho po poslednim kroku se vubec zacne prepinat na IHOLD
// (jednotky ~0.021 s, 20 => ~0.4 s).
static constexpr uint8_t TPOWERDOWN = 20;

// Snimaci rezistor na modulu driveru. JEDINE cislo, na kterem stoji prepocet
// mA -> CS: 0.11 ohm ma SilentStepStick TMC2209 i Trinamic TMC2209-BOB.
// Kdyz je na modulu jina hodnota, vsechny proudy jsou o ten podil vedle.
static constexpr float R_SENSE_OHM = 0.11f;

// --- pohyb -----------------------------------------------------------------
// Kolik otacek je jeden pohyb. Firmware jede porad totez: tam, pauza, zpet,
// pauza, tam, ... Prvni pohyb je smer A (DIR v L).
static constexpr float REVS_PER_MOVE = 1.0f;
// Cestovni rychlost v otackach za minutu. 60 rpm = jedna otacka za sekundu.
static constexpr float SPEED_RPM = 60.0f;
// Zrychleni v otackach za sekundu na sekundu. Rampa se vejde do pohybu: pri
// 60 rpm a 4 ot/s^2 se na plnou rychlost rozjede za 0.25 s (~ 1/8 otacky).
static constexpr float ACCEL_RPS2 = 4.0f;
// Rychlost prvniho a posledniho kroku. Rampa nesmi zacinat od nuly (perioda
// by byla nekonecna), ale prilis vysoka hodnota znamena skok na start.
static constexpr float START_RPM = 3.0f;
// Prodleva mezi jednotlivymi pohyby.
static constexpr uint32_t PAUSE_MS = 500;

// --- bezpecnost a start ----------------------------------------------------
// Odpocet po nabootovani, nez se motor prvne rozjede. Da se stihnout odpojit
// napajeni, kdyz je mechanika v nepovolenem stavu. 0 = rozjezd hned.
static constexpr uint32_t START_DELAY_MS = 3000;
// Cekat po odpoctu jeste na Enter z konzole? true = deska se sama nerozjede,
// coz je bezpecnejsi na stole, ale nepouzitelne pri behu bez pripojeneho PC.
static constexpr bool WAIT_FOR_ENTER = false;
// Hlidat koncovy spinac motoru a pri sepnuti pohyb zastavit. Kdyz je spinac
// v klidu sepnuty (nebo neni zapojeny a chybi pull-up), hlidani se pri startu
// samo vypne - jinak by se firmware nikdy nerozjel.
static constexpr bool ENDSTOP_GUARD = true;
// Jakykoli znak z konzole behem jizdy pohyb prerusi (softwarova stop klavesa).
static constexpr bool STOP_ON_KEYPRESS = true;

// --- limity generatoru kroku ----------------------------------------------
// Nad 20 000 kroku/s uz rezie digitalWrite prevazi nad periodou a rychlost
// prestava odpovidat zadani. Strop plati i pro SPEED_RPM.
static constexpr float MAX_STEP_RATE = 20000.0f;
// Sirka STEP impulsu. TMC2209 potrebuje minimalne 100 ns, 3 us je s rezervou
// a pri 20 000 krocich/s (perioda 50 us) porad bez problemu.
static constexpr uint32_t STEP_PULSE_US = 3;
// Jak dlouho musi byt DIR stabilni, nez prijde hrana STEP. Datasheet chce
// 20 ns, tady se ceka na zapis do 74HC595, takze radeji hodne s rezervou.
static constexpr uint32_t DIR_SETUP_US = 200;

}  // namespace fas

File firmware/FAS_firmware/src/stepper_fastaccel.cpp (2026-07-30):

#include "stepper_fastaccel.h"

#include "fas_config.h"

namespace fas {

StepperFA* StepperFA::active_ = nullptr;

// Zavola FastAccelStepper, kdyz chce prepnout externi DIR pin. `pin` je to,
// co jsme dali do setDirectionPin() (motor_ | PIN_EXTERNAL_FLAG), `value` je
// pozadovana uroven (0/1). Vracime hned potvrzenou hodnotu - ShiftReg::write()
// uz je hotovy zapis, ne asynchronni operace.
bool StepperFA::set_dir_pin(uint8_t pin, uint8_t value) {
  if (!active_) return value;
  const uint8_t motor = pin & ~PIN_EXTERNAL_FLAG;
  active_->sr_.set_dir(motor, value != 0);
  return value;
}

void StepperFA::begin(uint8_t motor) {
  motor_ = motor;

  // Stejne bezpecnostni poradi jako Stepper::begin(): STEP piny do L, pak
  // zakazat drivery pres 74HC595 - driv, nez cokoli jineho rozjede motor.
  for (uint8_t i = 0; i < 4; ++i) {
    pinMode(PIN_STEP[i], OUTPUT);
    digitalWrite(PIN_STEP[i], LOW);
  }
  sr_.begin();  // SR_ALL_DISABLED
  enabled_ = false;

  active_ = this;
  engine_.init();
  engine_.setExternalCallForPin(&StepperFA::set_dir_pin);
  stepper_ = engine_.stepperConnectToPin(PIN_STEP[motor_]);
  if (stepper_) {
    // dirHighCountsUp = false, aby kladny pohyb (pozice nahoru) odpovidal
    // DIR v L = "smer A", stejne jako v puvodnim Stepperu.
    stepper_->setDirectionPin(static_cast<uint8_t>(motor_) | PIN_EXTERNAL_FLAG,
                               /*dirHighCountsUp=*/false);
  }
  // stepper_ == nullptr by znamenalo, ze RMT/MCPWM prostredku na desce uz
  // nejsou - pri jednom motoru by k tomu nemelo dojit.

  pinMode(PIN_ENDSWITCH[motor_], INPUT);
}

bool StepperFA::set_profile(uint32_t steps_per_rev, float speed_rpm,
                            float accel_rps2, float /*start_rpm*/) {
  const float steps = static_cast<float>(steps_per_rev);
  bool within_limit = true;

  v_max_ = speed_rpm / 60.0f * steps;
  if (v_max_ > MAX_STEP_RATE) {
    v_max_ = MAX_STEP_RATE;
    within_limit = false;
  }
  accel_ = accel_rps2 * steps;
  if (accel_ < 1.0f) accel_ = 1.0f;

  if (stepper_) {
    stepper_->setSpeedInHz(static_cast<uint32_t>(v_max_ + 0.5f));
    stepper_->setAcceleration(static_cast<int32_t>(accel_ + 0.5f));
  }
  return within_limit;
}

void StepperFA::enable(bool on) {
  sr_.set_enable(motor_, on);
  enabled_ = on;
  delay(10);  // driver nabehne na proud, nez prijde prvni krok
}

bool StepperFA::endstop_closed() const {
  return digitalRead(PIN_ENDSWITCH[motor_]) == LOW;
}

int32_t StepperFA::position() const {
  return stepper_ ? stepper_->getCurrentPosition() : 0;
}

void StepperFA::zero() {
  if (stepper_) stepper_->setCurrentPosition(0);
}

uint32_t StepperFA::last_rate() const {
  if (last_ms_ == 0) return 0;
  return static_cast<uint32_t>(static_cast<uint64_t>(last_steps_) * 1000ULL /
                               last_ms_);
}

uint32_t StepperFA::ramp_steps() const {
  // s = v_max^2 / (2a), tedy Stepper::ramp_steps() se start_rpm = 0 - presne
  // to, jak FastAccelStepper rozjezd z klidu pocita sam.
  const float s = (v_max_ * v_max_) / (2.0f * accel_);
  return (s <= 0.0f) ? 0u : static_cast<uint32_t>(s);
}

MoveEnd StepperFA::move(int32_t steps) {
  last_steps_ = 0;
  last_ms_ = 0;
  if (steps == 0 || !stepper_) return MoveEnd::done;

  if (guard_ && endstop_closed()) return MoveEnd::endstop;

  const int32_t p0 = stepper_->getCurrentPosition();
  const uint32_t t_start = millis();

  if (stepper_->move(steps) != MoveResultCode::OK) {
    // Rychlost/zrychleni jeste nebyly nastaveny (set_profile se nezavolal) -
    // DIR samo o sobe nemuze selhat, resi ho externi callback vyse.
    last_ms_ = millis() - t_start;
    return MoveEnd::done;
  }

  MoveEnd end = MoveEnd::done;
  bool stopping = false;
  while (stepper_->isRunning()) {
    if (!stopping) {
      if (guard_ && endstop_closed()) {
        stepper_->forceStop();
        end = MoveEnd::endstop;
        stopping = true;
      } else if (STOP_ON_KEYPRESS && Serial.available()) {
        while (Serial.available()) Serial.read();
        stepper_->forceStop();
        end = MoveEnd::keypress;
        stopping = true;
      }
    }
    // Bez guardu/klavesy se jen ceka, az stepper task (bezi sam na pozadi)
    // frontu dojede. Po forceStop() se pollu castejc, at se drain nezdrzuje.
    delay(stopping ? 1 : 5);
  }

  last_ms_ = millis() - t_start;
  const int32_t delta = stepper_->getCurrentPosition() - p0;
  last_steps_ = static_cast<uint32_t>(delta < 0 ? -delta : delta);
  return end;
}

}  // namespace fas

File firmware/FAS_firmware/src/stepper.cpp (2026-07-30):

#include "stepper.h"

#include <math.h>

#include "fas_config.h"

namespace fas {

// --- 74HC595 ----------------------------------------------------------------

void ShiftReg::begin() {
  pinMode(PIN_SR_SER, OUTPUT);
  pinMode(PIN_SR_SRCLK, OUTPUT);
  pinMode(PIN_SR_RCLK, OUTPUT);
  digitalWrite(PIN_SR_RCLK, LOW);
  digitalWrite(PIN_SR_SRCLK, LOW);
  write(SR_ALL_DISABLED);
}

void ShiftReg::write(uint8_t value) {
  state_ = value;
  // MSB-first: bit7 jde dovnitr prvni a skonci na QH, bit0 zustane na QA.
  shiftOut(PIN_SR_SER, PIN_SR_SRCLK, MSBFIRST, value);
  digitalWrite(PIN_SR_RCLK, HIGH);
  delayMicroseconds(1);
  digitalWrite(PIN_SR_RCLK, LOW);
}

void ShiftReg::set_dir(uint8_t motor, bool high) {
  const uint8_t bit = SR_BIT_DIR[motor];
  write(high ? (state_ | (1u << bit)) : (state_ & ~(1u << bit)));
}

void ShiftReg::set_enable(uint8_t motor, bool enabled) {
  const uint8_t bit = SR_BIT_EN[motor];  // ENN je aktivni v L
  write(enabled ? (state_ & ~(1u << bit)) : (state_ | (1u << bit)));
}

void ShiftReg::disable_all() { write(static_cast<uint8_t>(state_ | 0xAA)); }

// --- Stepper ----------------------------------------------------------------

void Stepper::begin(uint8_t motor) {
  motor_ = motor;

  // Nejdriv STEP piny do L, pak zakazat drivery. V opacnem poradi by povoleny
  // driver mohl stihnout krok na STEP pinu, ktery je jeste ve vzduchu.
  for (uint8_t i = 0; i < 4; ++i) {
    pinMode(PIN_STEP[i], OUTPUT);
    digitalWrite(PIN_STEP[i], LOW);
  }
  sr_.begin();  // SR_ALL_DISABLED
  enabled_ = false;

  pinMode(PIN_ENDSWITCH[motor_], INPUT);  // 10k pull-up je na desce
  pos_ = 0;
}

bool Stepper::set_profile(uint32_t steps_per_rev, float speed_rpm,
                          float accel_rps2, float start_rpm) {
  const float steps = static_cast<float>(steps_per_rev);
  bool within_limit = true;

  v_max_ = speed_rpm / 60.0f * steps;
  if (v_max_ > MAX_STEP_RATE) {
    v_max_ = MAX_STEP_RATE;
    within_limit = false;
  }
  accel_ = accel_rps2 * steps;
  v_start_ = start_rpm / 60.0f * steps;

  // Rampa nesmi zacinat od nuly (perioda by byla nekonecna) ani nad cestovni
  // rychlosti (pak by "rampa" zpomalovala).
  if (v_start_ < 1.0f) v_start_ = 1.0f;
  if (v_start_ > v_max_) v_start_ = v_max_;
  if (accel_ < 1.0f) accel_ = 1.0f;

  return within_limit;
}

void Stepper::enable(bool on) {
  sr_.set_enable(motor_, on);
  enabled_ = on;
  delay(10);  // driver nabehne na proud, nez prijde prvni krok
}

bool Stepper::endstop_closed() const {
  return digitalRead(PIN_ENDSWITCH[motor_]) == LOW;
}

uint32_t Stepper::last_rate() const {
  if (last_ms_ == 0) return 0;
  return static_cast<uint32_t>(static_cast<uint64_t>(last_steps_) * 1000ULL /
                               last_ms_);
}

uint32_t Stepper::ramp_steps() const {
  // s = (v^2 - v0^2) / (2a)
  const float s = (v_max_ * v_max_ - v_start_ * v_start_) / (2.0f * accel_);
  return (s <= 0.0f) ? 0u : static_cast<uint32_t>(s);
}

MoveEnd Stepper::move(int32_t steps) {
  last_steps_ = 0;
  last_ms_ = 0;
  if (steps == 0) return MoveEnd::done;

  const bool dir_b = steps < 0;
  const uint32_t n = static_cast<uint32_t>(dir_b ? -steps : steps);

  if (guard_ && endstop_closed()) return MoveEnd::endstop;

  sr_.set_dir(motor_, dir_b);
  delayMicroseconds(DIR_SETUP_US);

  const uint8_t pin = PIN_STEP[motor_];
  const float v0sq = v_start_ * v_start_;
  const uint32_t t_start = millis();
  uint32_t deadline = micros();
  MoveEnd end = MoveEnd::done;

  for (uint32_t i = 0; i < n; ++i) {
    // Rychlost je minimum z rozjezdu, dojezdu a cestovni rychlosti. Pri
    // kratkem pohybu se obe rampy protnou v pulce a na v_max se nedojede.
    const float v_acc = sqrtf(v0sq + 2.0f * accel_ * static_cast<float>(i));
    const float v_dec =
        sqrtf(v0sq + 2.0f * accel_ * static_cast<float>(n - 1 - i));
    float v = (v_acc < v_dec) ? v_acc : v_dec;
    if (v > v_max_) v = v_max_;

    uint32_t period = static_cast<uint32_t>(1000000.0f / v);
    if (period <= STEP_PULSE_US) period = STEP_PULSE_US + 1;

    digitalWrite(pin, HIGH);
    delayMicroseconds(STEP_PULSE_US);
    digitalWrite(pin, LOW);
    ++last_steps_;
    pos_ += dir_b ? -1 : 1;

    deadline += period;
    // Cekani na dalsi krok. Kdyz uz je zpozdeni vetsi nez cela perioda
    // (dlouhy vypis, preruseni), termin se srovna s pritomnosti - jinak by
    // se dohanel davkou kroku bez prodlevy, tedy skokem rychlosti.
    if (static_cast<int32_t>(micros() - deadline) > static_cast<int32_t>(period)) {
      deadline = micros();
    }
    while (static_cast<int32_t>(micros() - deadline) < 0) {
    }

    // Pojistky se hlidaji jednou za 16 kroku - pri 3200 krocich/s je to 5 ms,
    // rychleji nez staci clovek pustit klavesu, a nezdrzuje to smycku.
    if ((i & 0x0F) == 0x0F) {
      if (guard_ && endstop_closed()) {
        end = MoveEnd::endstop;
        break;
      }
      if (STOP_ON_KEYPRESS && Serial.available()) {
        while (Serial.available()) Serial.read();
        end = MoveEnd::keypress;
        break;
      }
    }
  }

  last_ms_ = millis() - t_start;
  return end;
}

}  // namespace fas

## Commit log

2026-06-17 [upd] Schematic
2026-06-29 initial commit esp32stepper
    [CONN.kicad_sch, PWR.kicad_sch, drivers.kicad_sch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]
2026-06-29 [upd] Reorganization
    [CONN.kicad_sch, PWR.kicad_sch, drivers.kicad_sch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]
2026-06-29 [doc] New module driver
2026-06-30 revision 1: I2C pullups, USB LDO, etc.
    [CONN.kicad_sch, PWR.kicad_sch, esp32.kicad_sch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]
2026-07-03 Fixed UART, cleaned schematic, improved LDO
    [CONN.kicad_sch, PWR.kicad_sch, esp32.kicad_sch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]
2026-07-09 PCB layout v1.0
    [CONN.kicad_sch, PWR.kicad_sch, esp32.kicad_sch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]
2026-07-17 pcb version ready for final check
    [CONN.kicad_sch, PWR.kicad_sch, esp32.kicad_sch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]
2026-07-20 [pcb] Final processing and export of production data
    [CONN.kicad_sch, PWR.kicad_sch, esp32.kicad_sch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]
2026-07-20 Auto stash before merge of "main" and "origin/main"
    [pcb] Updated main connector and LT8610AC layout
    [CONN.kicad_sch, esp32stepper.kicad_pcb]
2026-07-20 [upd] Files reorganization
    [esp32stepper-B_Cu.gbr, esp32stepper-B_Mask.gbr, esp32stepper-B_Paste.gbr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]
2026-07-20 [pcb] New manufactured data
    [esp32stepper-B_Cu.gbr, esp32stepper-B_Mask.gbr, esp32stepper-B_Paste.gbr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]
2026-07-29 [fw] Testing firmware for board bring-up (PlatformIO)
    Adds firmware/testing_firmware - a PlatformIO project with a menu-driven
    test registry for bringing up the motor board: chip info, blink, shift
    register, step pins, endswitches, I2C scan, TMC UART, wiring selftest
    and motor move.
    Build artifacts (.pio/) and editor config (.vscode/) are gitignored;
    .DS_Store added to the root .gitignore.
2026-07-29 [doc] Add enclosure images and README documentation
2026-07-29 [doc] Update README with enclosure images and section
2026-07-29 [doc] Update enclosure image paths in README
2026-07-29 [feat] Add test_simple example for ESP32 with USB CDC and FTDI support
2026-07-30 [fix] Update platformio.ini for ESP32-S3-WROOM-2: correct flash size and memory type settings
2026-07-30 [fix] Update .gitignore to include hardware identifiers and ensure proper exclusion of sensitive files [doc] Revise README and README_CZ to clarify memory settings for ESP32-S3-WROOM-2 and DevKit com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
    [main.cpp]
2026-07-30 [feat] Add documentation for ESP32-S3-WROOM-2 configuration and flashing procedures
2026-07-30 [fix] Update platformio.ini for ESP32-S3-WROOM-2: correct memory configuration and flash settings
2026-07-30 [feat] testing_firmware: minimalni platformio.ini a diagnostika TMC2209 UART
    platformio.ini zkracen na jedine prostredi menu (130 -> 47 radku). Vyhozeny
    per-test envs a redundantni ARDUINO_USB_MODE (dava ho definice desky).
    Pridano lib_deps = Wire - LDF v rezimu chain bundlovanou knihovnu nezaradi
    a t05 se neprelozil. -I include zustava: knihovny v lib/ projektovy include
    dir nevidi a testkit.h nenajde board_pins.h.
    testkit: TmcBus si pamatuje, jestli se vratilo echo vlastniho vysilani
    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
2026-07-30 [feat] FAS_firmware: prvni aplikacni firmware desky (otacka tam a zpet)
    Novy PlatformIO projekt firmware/FAS_firmware — prvni krok od bring-up testu
    k aplikaci. Po zapnuti nastavi jeden driver TMC2209 po UART, povoli ho a pak
    uz jen dokola jede jednu otacku tam, pauza, jednu otacku zpet, pauza. Nic se
    neovlada z konzole, ta jen vypisuje.
    - include/fas_config.h — vsechna nastaveni na jednom miste (slot motoru,
    mikrokrok, proud v mA, rychlost v rpm); zadne konzolove prikazy
    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
2026-07-30 [doc] TMC2209_MS1_MS2: kod pro vsechny ctyri drivery + chyba v t08 (rev 2)
    Doplnen hotovy kod k postupu, ktery dokument dosud jen popisoval slovy:
    init_driver() / init_all_drivers() ctenim-upravou-zapisem (ne zapisem celeho
    slova, jinak se maze I_scale_analog) a recover_after_reset() nad GSTAT bit 0,
    protoze registry driveru jsou volatilni a po vypadku VM se piny zase ujmou
    mikrokrokovani.
    Zaznamenana konkretni chyba v testing_firmware/src/tests/t08_motor_move.cpp:
    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
2026-07-30 [feat] Add PlatformIO configuration for esp32stepper - too many arguments
2026-07-30 [feat] Implement driver survival check and reconfiguration after power loss
2026-07-30 [feat] FAS_firmware: FastAccelStepper prototype (env:fas_accel) for stepper.cpp comparison
2026-07-30 [doc] FAS_firmware: FastAccelStepper external DIR pin note (HW-00178)
2026-07-31 [feat] Implement non-blocking status LED functionality for testing firmware
2026-07-31 [fw] simple_move: zakladni pohyb driveru BOB-3, v1
    Osekana kopie FAS_firmware - jeden generator kroku (softwarova smycka,
    zadne FastAccelStepper), zadne prepinace chovani, zadne automaticke
    zotaveni z vypadku 24 V (misto toho HALT). Motor po zapnuti jede porad
    dokola otacku tam a zpet, driver nastaveny po UART (proud, mikrokrok).
2026-07-31 feat: Implement motor movement test in `main.cpp`
2026-07-31 [fix] Update motor step configuration for proper microstepping in `t08_motor_move`
    [t08_motor_move.cpp]
2026-07-31 fix: Update status LED blink period from 300ms to 80ms for improved responsiveness
    [status_led.cpp]
2026-07-31 [add] All channel motor test
